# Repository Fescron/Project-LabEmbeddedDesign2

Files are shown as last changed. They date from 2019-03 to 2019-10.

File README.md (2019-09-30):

# Project-LabEmbeddedDesign2








<br/>

This repository contains the **presentation**, **reports** and **code** for the project constructed for **Embedded System Design 2 - Lab**.

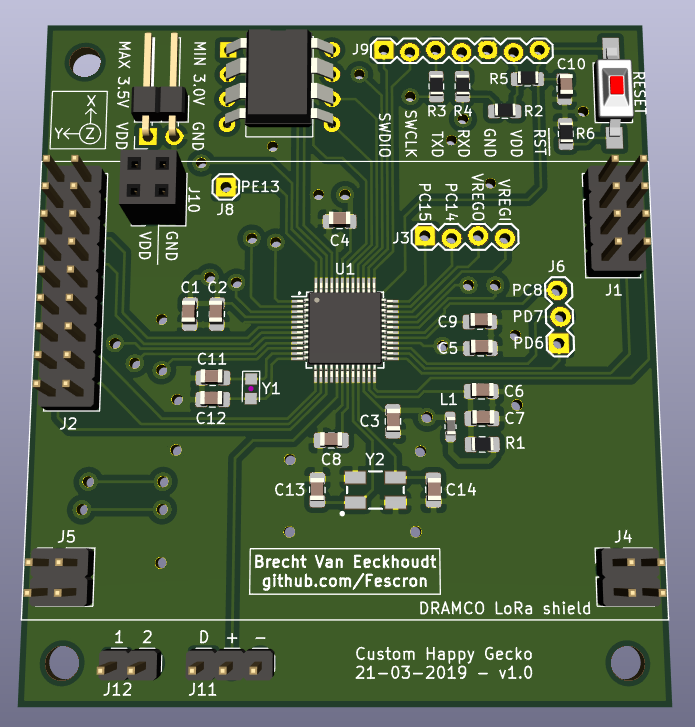
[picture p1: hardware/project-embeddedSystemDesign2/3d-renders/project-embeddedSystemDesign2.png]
Project
 Project

<br/>

## 1 - Quick links

- [**Reports and presentation**](documentation/reports)
- [General important Doxygen documentation](https://fescron.github.io/Project-LabEmbeddedDesign2/index.html)
- [Doxygen code documentation of individual files and methods](https://fescron.github.io/Project-LabEmbeddedDesign2/files.html)
- [Code for the custom TTN decoder](software/decoder.js)
- [Schematic of custom PCB](documentation/schematics/project-embeddedSystemDesign2.pdf)
- [Schematic of DRAMCO LoRaWAN shield](documentation/schematics/dramco-LoRa-addon-schematic-v4-0.pdf)
- [Picture with PCB dimensions](hardware/project-embeddedSystemDesign2/3d-renders/project-embeddedSystemDesign2-pcb-dimensions.png)
- [The Things Network - Applications](https://console.thethingsnetwork.org/applications/)
- [Cayenne Dashboard](https://cayenne.mydevices.com/cayenne/dashboard/start)

<br/>

## 2 - GIT repo structure

|  Location  |  Content  |
| --- | --- |
| [/docs/](https://fescron.github.io/Project-LabEmbeddedDesign2/index.html) | **[Doxygen](http://www.doxygen.org) code documentation.** |
| <br/> | |
| [/documentation/current measurements/](documentation/current%20measurements) | Documents containing current measurements. |
| [/documentation/current measurements/measurements-SF/](documentation/current%20measurements/measurements-SF) | Pictures depicting current profiles for sending 6 measurements at full gain with different LoraWAN *Spreading Factors*. More information can be found in section *"3 - LoRaWAN spreading factor (RN2483)"* in [this](documentation/current%20measurements/currents-2-projectEmbeddedDesign2.pdf) file . |
| <br/> | |
| [/documentation/datasheets/](documentation/datasheets) | General datasheets regarding the used items. |
| [/documentation/datasheets/hardware-design/](documentation/datasheets/hardware-design) | Documents regarding hardware design for the `EFM32HG` microcontroller. |
| [/documentation/datasheets/timers-energy-rtc/](documentation/datasheets/timers-energy-rtc) | Documents regarding `timers`, the `RTC` and `energy modes` on the `EFM32HG` microcontroller. |
| <br/> | |
| [/documentation/figures/](documentation/figures) | Figures used in reports and the README. |
| [/documentation/figures/installation/](documentation/figures/installation) | **Pictures taken during the project installation.** |
| [/documentation/reports/](documentation/reports) | **Reports and presentation.** |
| [/documentation/schematics/](documentation/schematics) | Schematics. <br/>  See [this](documentation/schematics/project-embeddedSystemDesign2.pdf) file for the schematic of the *self designed PCB* and [this](documentation/schematics/dramco-LoRa-addon-schematic-v4-0.pdf) file for the schematic of the *DRAMCO LoRaWAN shield*.
| <br/> | |
| [/hardware/project-embeddedSystemDesign2/](hardware/project-embeddedSystemDesign2) | [KiCad](http://kicad-pcb.org/) PCB design files. <br/> See [this](hardware/project-embeddedSystemDesign2/pdf/project-embeddedSystemDesign2.pdf) file for the *schematic* and [this](hardware/project-embeddedSystemDesign2/bom/bom-custom-gecko-v1-0.pdf) file for the *BOM*. |
| [/hardware/project-embeddedSystemDesign2/3d-renders/](hardware/project-embeddedSystemDesign2/3d-renders) | Pictures of 3D renders of the *self designed PCB*. <br/> On [this](hardware/project-embeddedSystemDesign2/3d-renders/project-embeddedSystemDesign2-pcb-dimensions.png) picture the *dimensions* are displayed. <br/>  [This](hardware/project-embeddedSystemDesign2/3d-renders/project-embeddedSystemDesign2.png) is a render of the *front* and [this](hardware/project-embeddedSystemDesign2/3d-renders/project-embeddedSystemDesign2-back.png) is a render of the *back*. |
| <br/> | |
| [/software/EFM32HG-Embedded2-project/](software/EFM32HG-Embedded2-project) | **Code for the project.** <br/> See [this](https://fescron.github.io/Project-LabEmbeddedDesign2/index.html) page for *general important documentation* and [this](https://fescron.github.io/Project-LabEmbeddedDesign2/files.html) page for information regarding *individual files and their methods*. [This](software/decoder.js) is the *decoder* for use on The *Things Network*. |

<br/>

## 3 - Code flow

**Note:** The code is developed using `Simplicity Studio v4` on `Ubuntu 18.04 LTS`. The code also has [dbprint](https://github.com/Fescron/dbprint) functionality.

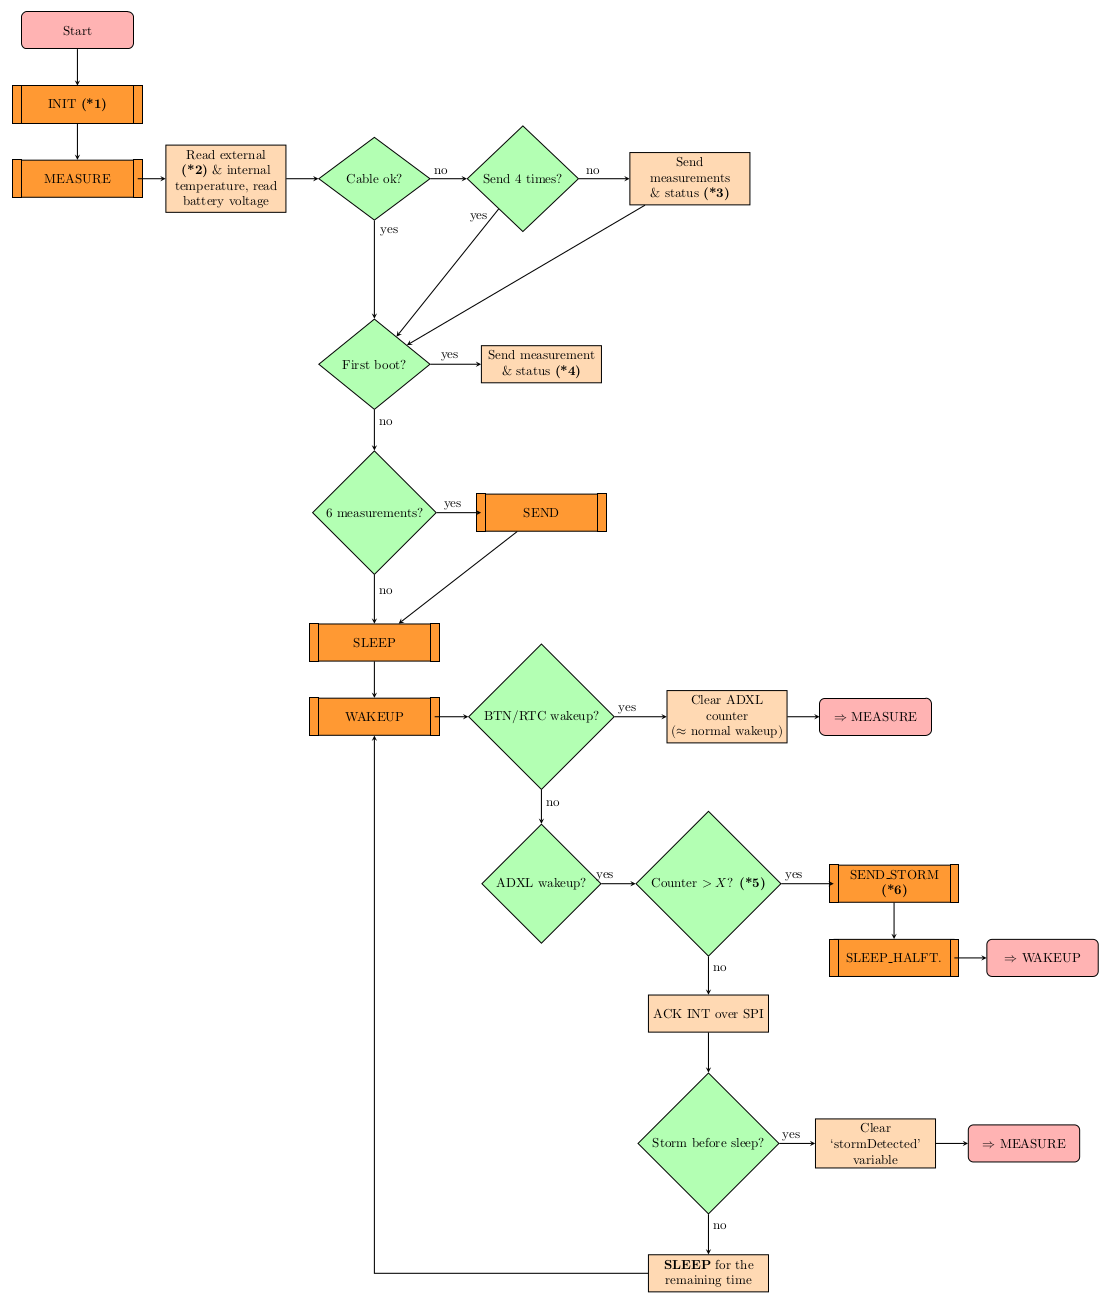
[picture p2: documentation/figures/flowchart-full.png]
Flowchart


**Extra notes on the flowchart:**

- **(\*1):** The following things get initialized:
    - Chip
    - GPIO wakeup (buttons & ADXL INT1)
    - ADC
    - Disable RN2483
    - Accelerometer (initialize SPI and use it to configure the accelerometer
- **(\*2):** On every external temperature measurement the VDD and DATA pin get re-configured. The oneWire protocol is achieved using *bit-banging*.
- **(\*3):** The RN2483 module gets enabled and configured before sending the data. Afterwards it gets disabled again. The **status** message is always send, measurements only if there are any recorded.
- **(\*4):** Only one set of measurements are send along with the status message.
- **(\*5):** The value of **X** depends on a configured setting.
- **(\*6):** A status message is send along with any recorded measurements.

<br/>

- Before entering a *sleep* state **all GPIO (data) pins are disabled** so they can't consume any power.
- **Clocks and peripherals** are only enabled when necessary.
- If an **error** occures this gets **forwarded to the cloud using a LoRaWAN status message**.
- To conserve sended bytes a **custom data-format** was used (along with a *decoder*).
- Negative internal and external temperatures were successfully send and displayed. The internal temperature seems to be 2 - 3 °C off.

<br/>

## 4 - Extra hardware changes

The [schematic](hardware/project-embeddedSystemDesign2/pdf/project-embeddedSystemDesign2.pdf) for the custom PCB **misses two resistors**. A surface mount `10 kΩ` resistor was added between the *data* and *power* pin for the DS18B20 temperature sensor. A `3,3 kΩ` resistor with wires was added between the `BREAK_1`pin and `VDD`. These added resistors can be seen on the bottom right on the left most picture below.

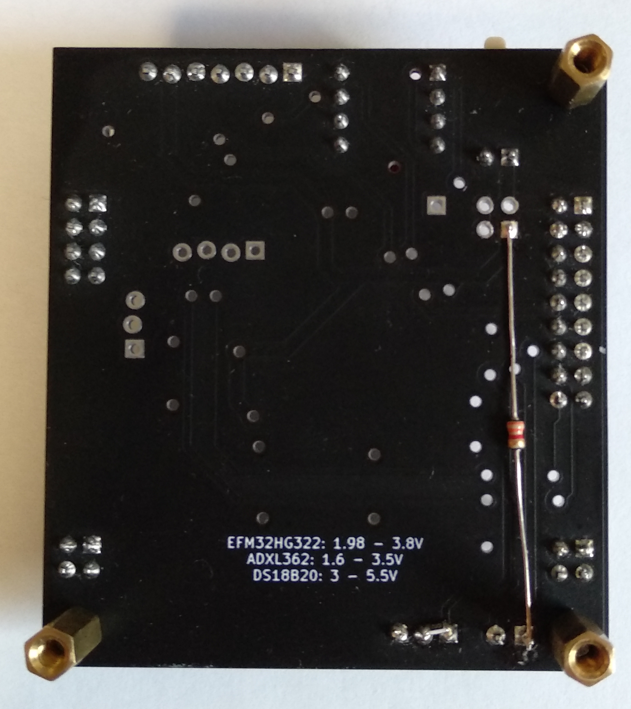
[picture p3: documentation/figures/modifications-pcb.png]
Added resistors
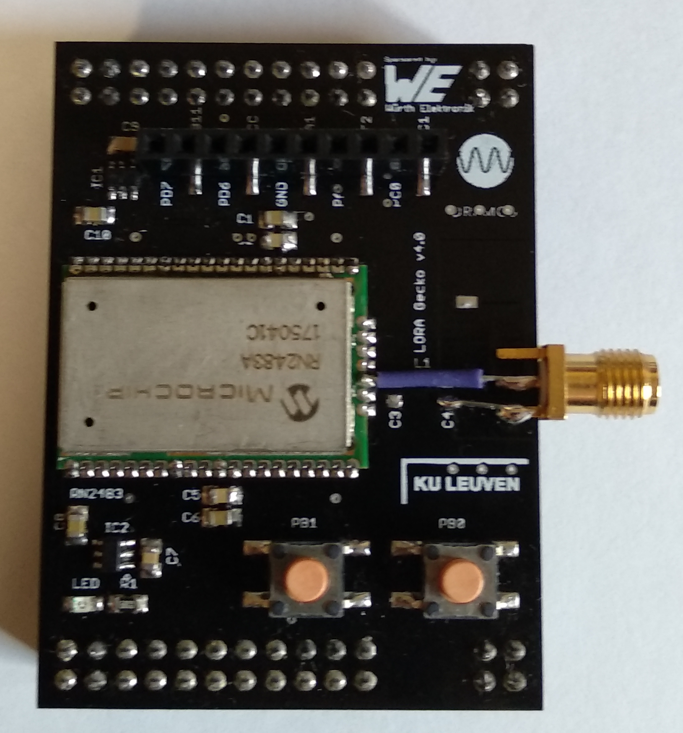
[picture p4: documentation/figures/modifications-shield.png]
Shield modifications
 

An **SMA connector for an external antenna** was also added to the DRAMCO LoRaWAN shield. This was done by **removing** the `chip-antenna`, capacitors `C3` and `C4` and inductor `L1` and replacing it with an SMA connector directly connected to the signal pin of the *RN2483* module. This modification can be seen on the right on the right most picture above.

To protect the PCB's from moisture and other contaminants, they were given 2 coats of `PLASTIK 70`.

Protection during coating Coating process

<br/>

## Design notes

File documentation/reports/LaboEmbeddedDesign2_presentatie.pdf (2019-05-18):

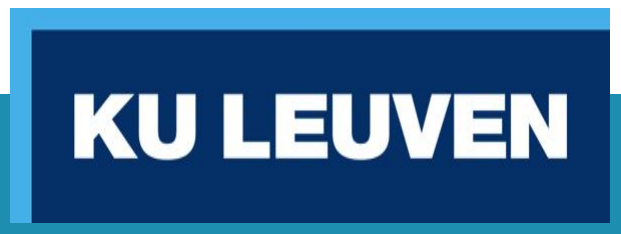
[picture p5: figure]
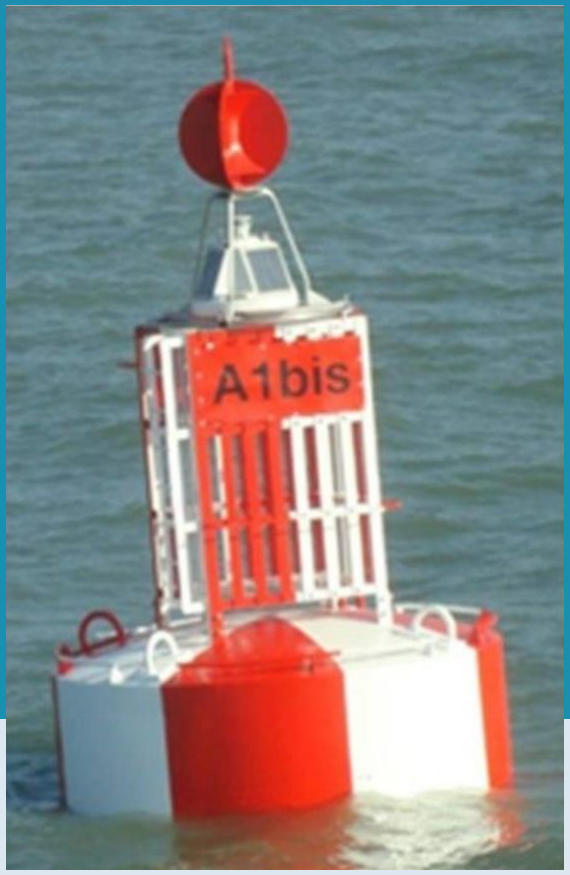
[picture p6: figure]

## Team ter Zee

Embedded System design 2
2018 - 2019

Brecht Van Eeckhoudt – Sarah Goossens – Matthias Alleman Benjamin Van der Smissen – Arno Plaetinck

- Driftdetectie boei op zee
- Meten van watertemperatuur
- Detecteren van ruwe zee
- Communicatie met het vaste land
2 | Embedded Systems Design: Team Ter Zee

## Beschrijving doelstellingen

- Specificaties
- Uitvoering
- Metingen
- Kostenanalyse
- Toekomstige verbeteringen
- Demo
- Besluit
- Q & A

3

## Inhoud

Embedded Systems Design: Team Ter Zee

- Functioneel technische:
1. Meten watertemperatuur, batterijspanning en interne temperatuur (elk uur)
2. Driftdetectie van boei (elk uur)
3. Stormdetectie via interrupts, extra metingen indien storm
4. Vier keer per dag data doorsturen naar vaste land
- Niet functioneel technische specificaties
1. Zo energiezuinig mogelijk
2. Module dient 5 jaar mee te gaan
3. Behuizing: bestand tegen zout water

## Specificaties

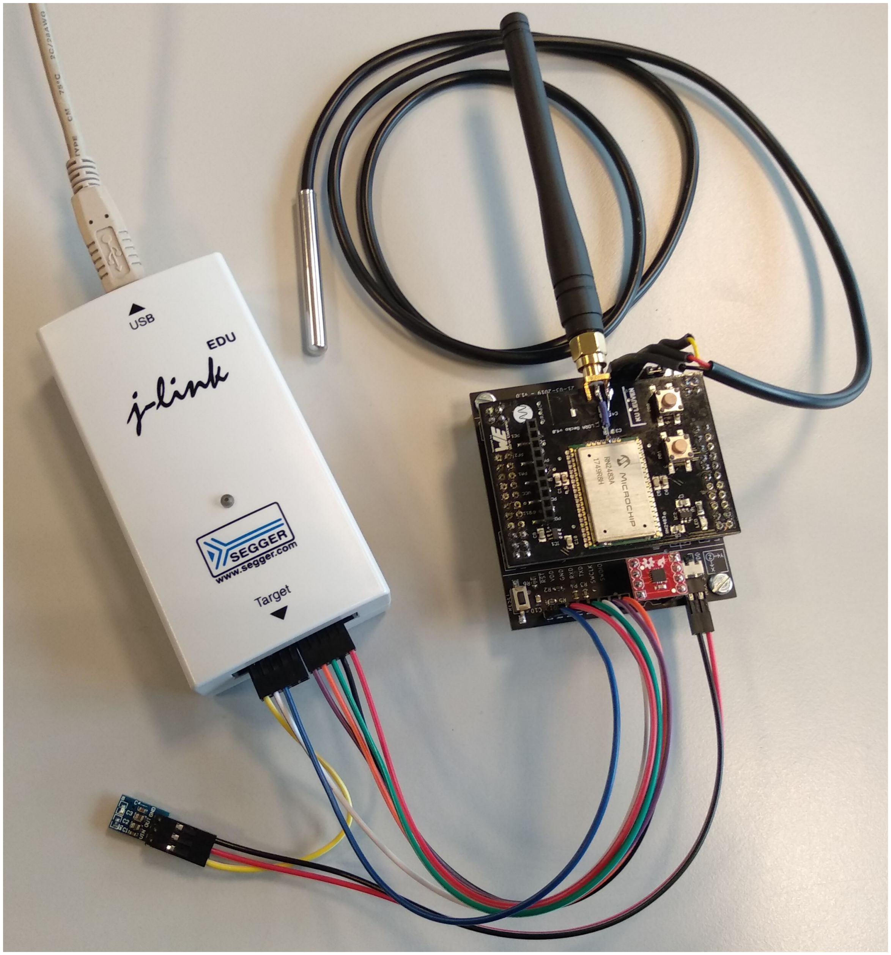
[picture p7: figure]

- Eigen PCB gebaseerd op Happy Gecko
- LoRaWAN-board van DRAMCO en antenne
- Accelerometer ADXL362
- Temperatuursensor DS18B20
- Driftdetectiesensor
- Batterij ER14505 (niet herlaadbaar) 3,6V Lithium-thionyl Chloride: Li-SOCl2
- Waterdichte behuizing

## Componenten

- Gebaseerd op een zwakke schakel van de ketting → Een kabel die breekt bij grote belasting

## Driftdetectie

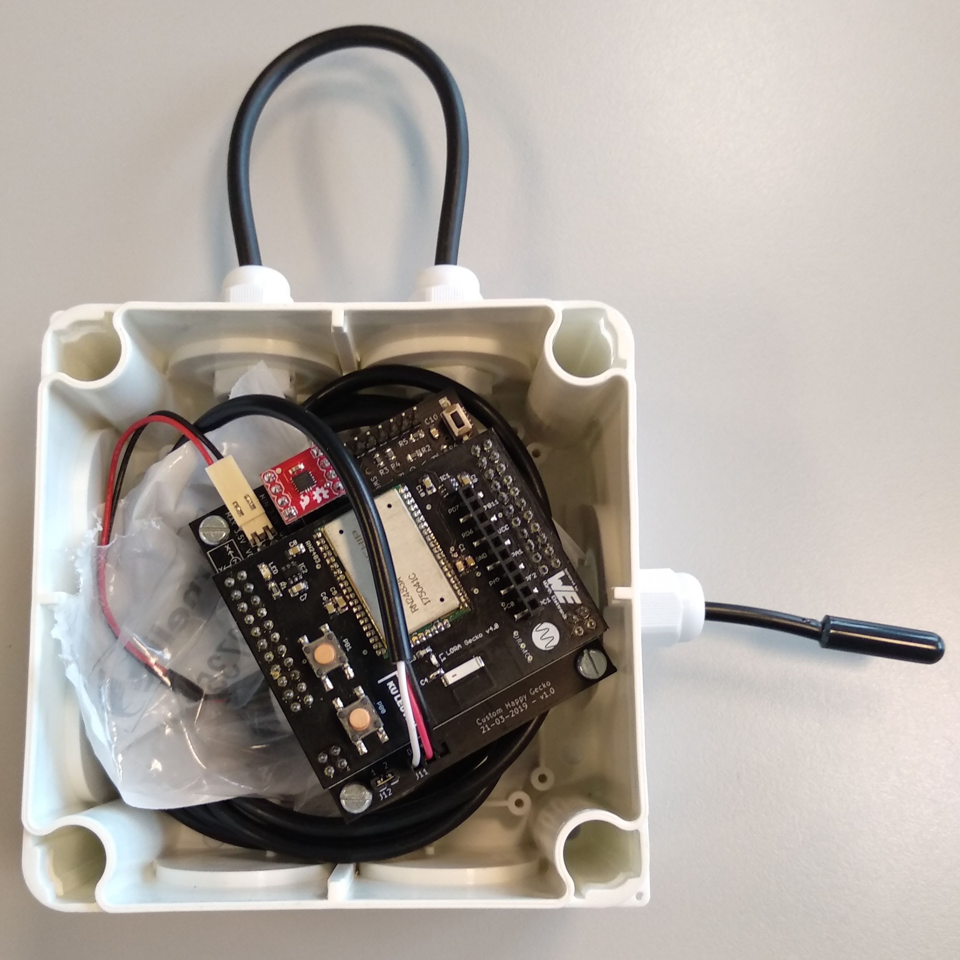
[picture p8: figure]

- Temperatuursensor meet watertemperatuur
- Accelerometer meet of er storm is

Indicatieve metingen:
- Interne temperatuur
- Batterijspanning

## Metingen

## Verbruik: metingen + sleep mode

Actieve tijd
(s)

Stroomverbruik
(mA)

Energie per onderdeel
(J/dag)
Happy Gecko | 123,2 | 5,52 | 2,244
ADXL362 | 115,2 | 0,00337 | 0,00128
DS18B20 | 24 | 2 | 0,158
LoRaWAN | 22,4 | 14,5 | 1,0696
Slaaptijd (s) | Stroomverbruik
(µA)
| | Energie per onderdeel
(J/dag)

Volledig
systeem
86,3E+03 | 4,06 | 1,16
Totale actieve energie: | 3,473 J/dag
Totale energie in sleep mode: | 1,16 J/dag

## Totaal verbruik

Totale Energie | 4,633 J/dag
Energie nodig voor vijf jaar : | 8395 J
Nodige batterijcapaciteit voor vijf jaar: | 707 mAh
Nodige batterijcapaciteit met veiligheidsfactor (x5): | 3535 mAh

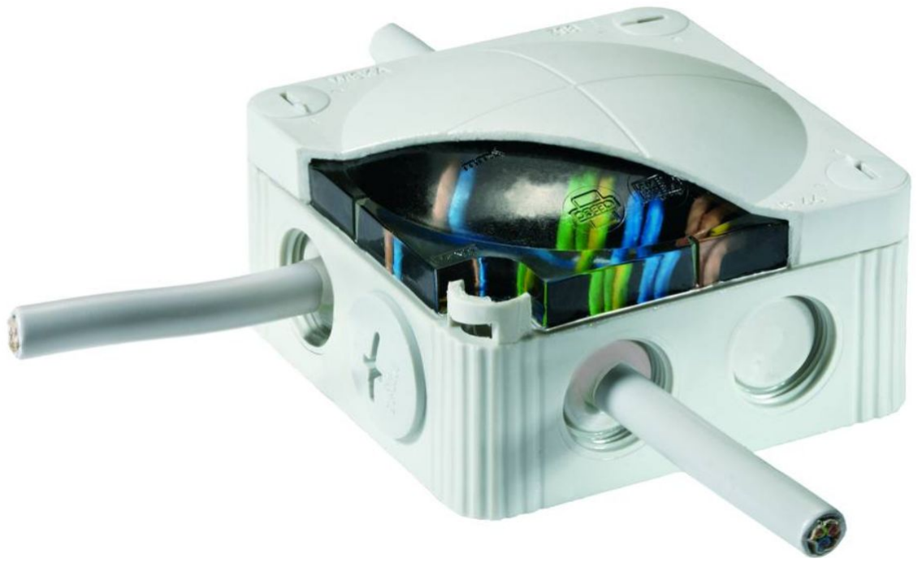
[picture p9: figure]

- IP67
- 4 connecties naar buiten
- Eventueel verzegelen met hars
- Zoutwater bestendig

→ Niet UV-bestendig ...

10

## Behuizing

- Cayenne LPP formaat vraagt veel “extra” bytes bij 6 metingen → Eigen data-formaat + decoder in TTN
- Ontvangen data moet nog niet echt verwerkt worden
→ Nu indicatief: e-mail via IFTTT
- Probleem in code → “error” methode aangeroepen → Doorzenden naar vaste land via statusbericht

## Communicatie naar vaste land

## Communicatie naar vaste land

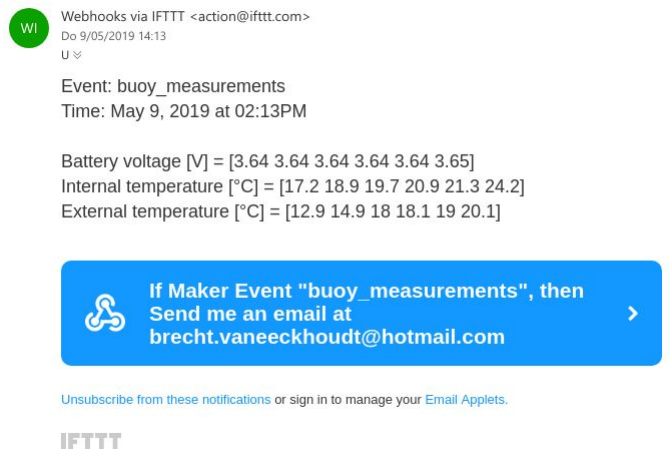
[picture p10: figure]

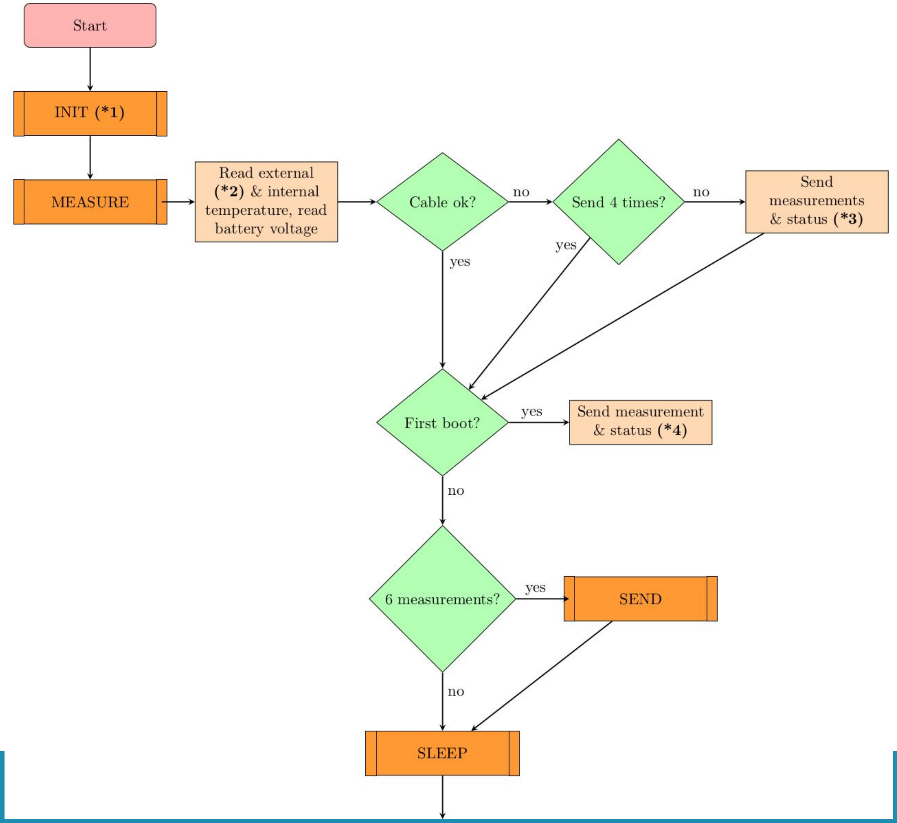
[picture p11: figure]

13

## Code Flow

## Code Flow

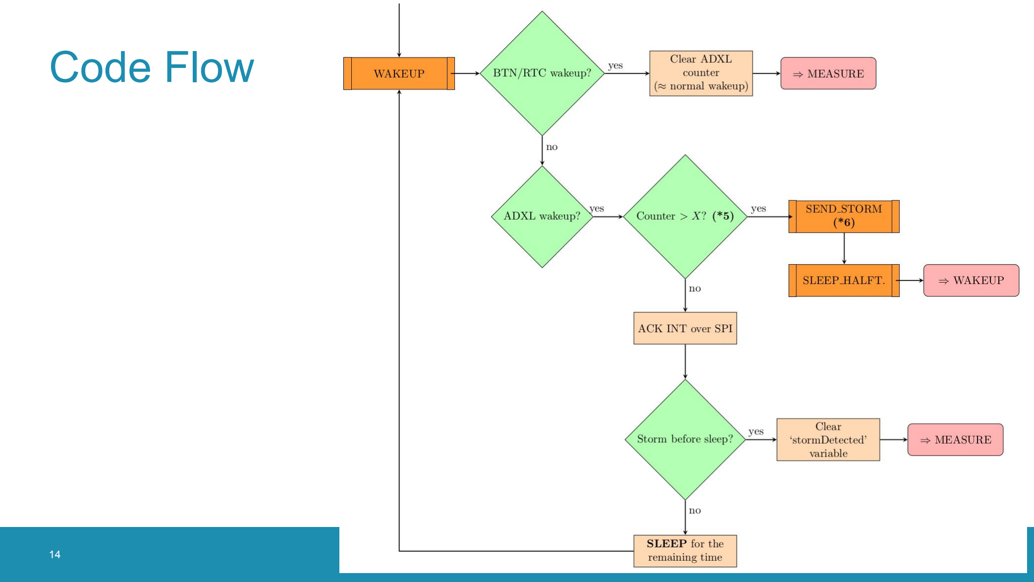
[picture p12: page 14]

14

## Metingen

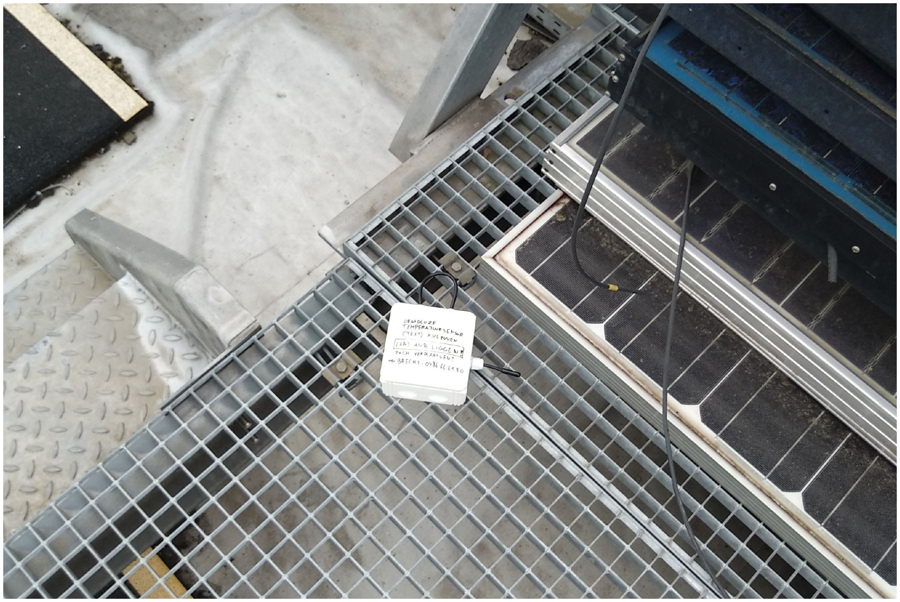
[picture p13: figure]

## Metingen

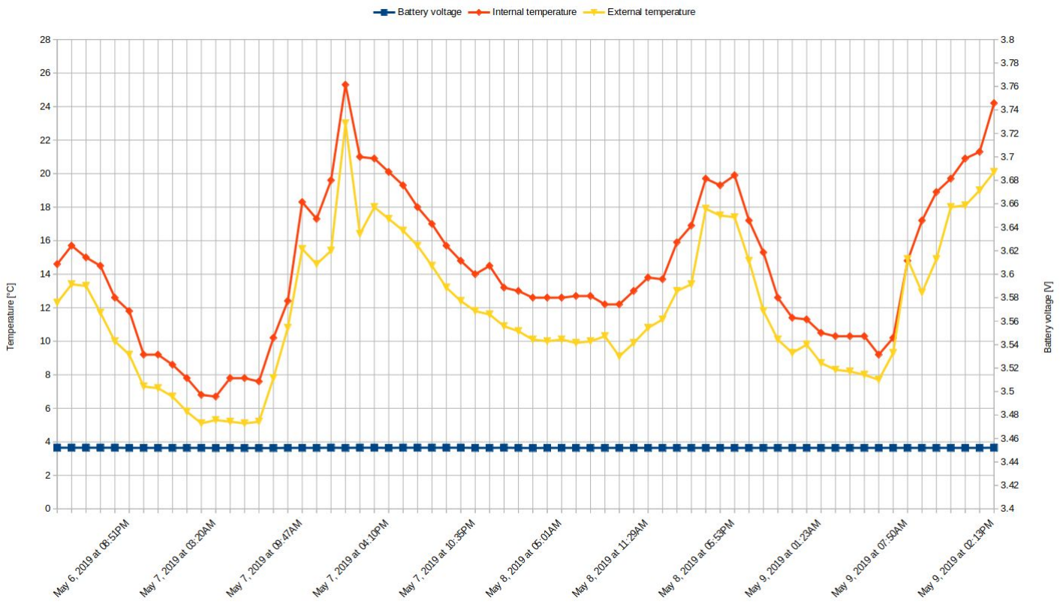
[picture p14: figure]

- De NRE-kosten zijn € 0
- Variabele kosten:
1. Eigen Happy Gecko | € 6
2. Temperatuursensor | € 10
3. Accelerometer | € 15
4. Driftsensor | € 1
5. Loramodule | € 10
6. Batterij | € 12
7. Behuizing | € 10
Totaal = € 64

## Kostenanalyse

18

- Breken van kabel via interrupt detecteren
→ Twee parallelle lijnen die normaal niet verbonden zijn → Bij een breuk verbinden ze via het water
- Andere manier om driftdetectie te detecteren
- LoRaWAN instellingen op module opslaan
- Golffrequentie berekenen met een FFT
- Accelerometer in wakeup-mode configureren
→ Ongeveer 6 keer per seconde een meting (270 nA)

19

## Toekomstige verbeteringen

## Demo

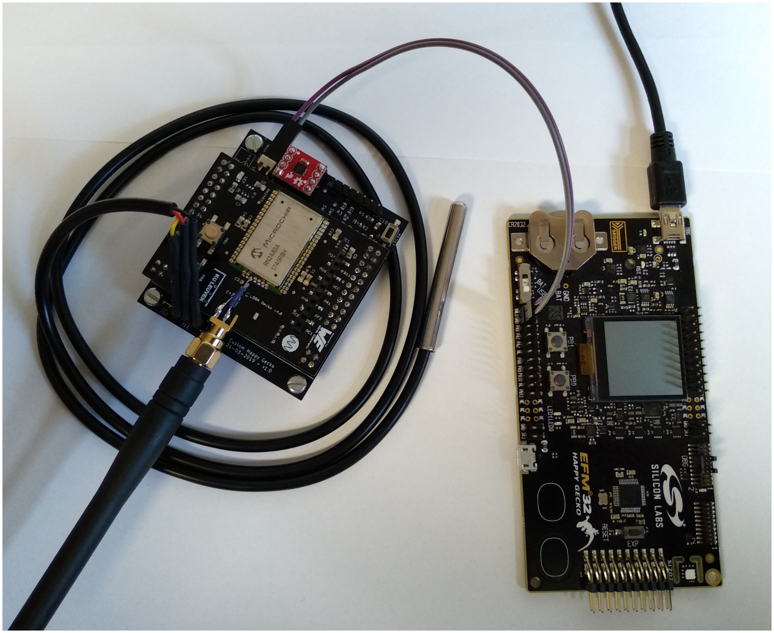
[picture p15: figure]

## Besluit

## Vragen?

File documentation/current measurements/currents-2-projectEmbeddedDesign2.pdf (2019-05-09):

### LAB EMBEDDED SYSTEM DESIGN 2

### PROJECT

## Measured currents at the end of the code development

Brecht Van Eeckhoudt
9 mei 2019

All measurements are done at 3, 29 − 3, 3 V

## 1 Sleep currents

The following currents represent the mean current consumed by the whole board between wake-ups using the RTC. An interval of 130 s was used to calculate this mean value. The accelerometer is enabled and measuring at ODR 12,5 Hz and can send an interrupt to wake-up the MCU.

| Sleeping in EM3 using ULFRCO (3600 s wake-up interval) ≈ 4, 06 µA
| Sleeping in EM2 using LFXO (500 s wake-up interval) ≈ 4, 12 µA
2 | ADXL362

The following currents represent the currents consumed by the accelerometer and MCU in various measuring modes. The settings are maintained for one second (≈ 800 ms due to the

ULFRCO not being very accurate) to calculate the mean current. The MCU is sleeping in EM3. Measurement mode is enabled for all values except when the accelerometer is in standby.

| Standby (after soft reset) ≈ 1, 60 µA
| ODR 12,5 Hz ≈ 3, 37 µA
| ODR 25 Hz ≈ 3, 43 µA
| ODR 50 Hz ≈ 3, 50 µA
| ODR 100 Hz ≈ 3, 79 µA
| ODR 200 Hz ≈ 4, 32 µA
| ODR 400 Hz ≈ 5, 53 µA

## 3 LoRaWAN spreading factor (RN2483)

The following (mean) currents are the result of sending 6 measurements using various LoRaWAN spreading factors. Use the pictures of the current proles to better understand the `peak' currents.

SF12: Imean ≈ 19, 88 mA (6, 95 s)

Ipeak 1 ≈ 41, 16 mA (2, 63 s) Ipeak 2 ≈ 15, 37 mA (150 ms) Ipeak 3 ≈ 15, 46 mA (250 ms)

Ibetween peaks ≈ 5, 10 mA

| SF11: Imean ≈ 14, 47 mA (5, 80 s)
Ipeak 1 ≈ 40, 76 mA (1, 4 s) (not | too | sure | about | the | `1,4 | s'. . . )

Ipeak 2 . . . (same currents and time as above for all the second and third peaks following, the 150 ms peak gets a bit shorter the lower the selected spreading factor.)
SF10: Imean ≈ 10, 41 mA (5, 03 s)

Ipeak 1 ≈ 40, 53 mA (650 ms)

SF9: Imean ≈ 8, 30 mA (4, 72 s)

Ipeak 1 ≈ 37, 09 mA (360 ms)

SF8: Imean ≈ 7, 28 mA (4, 56 s)

Ipeak 1 ≈ 37, 33 mA (200 ms)

SF7: Imean ≈ 6, 59 mA (4, 46 s)

Ipeak 1 ≈ 36, 42 mA (100 ms)

## 4 Active current

The following (mean) current was measured when the MCU gets woken up using a button interupt and takes measurements once. The DS18B20 temperature sensor used does very fast conversions, when using another one this timing might be dierent.

| Imean ≈ 1, 27 mA (81, 60 ms)
| Ipeak 1 ≈ 2, 83 mA

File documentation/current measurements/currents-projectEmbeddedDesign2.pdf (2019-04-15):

### LAB EMBEDDED SYSTEM DESIGN 2

### PROJECT

### Currents

Brecht Van Eeckhoudt
15 april 2019

## 1 Happy Gecko Energy modes

We jump between EM0 and EM2. The following data is from the datasheet.

EM0 230 µA/MHz (24 MHz = 5,52 nA)

EM1 67 µA/MHz

EM2 0,95 µA (RTC disabled not in our case since every hour we need to wake up?)

EM3 0,65 µA

EM4 20 nA

## 2 ADXL362

We use the accelerometer now @ 12,5 Hz ODR¹ so the actual current should be lower. The following data is from the datasheet.

100 Hz ODR @ 2V 1,8 µA

400 Hz ODR @ 2V 3,0 µA
Wakeup mode @ 2V 270 nA²

## 3 Happy Gecko + ADXL362

The following data is approximated using measurements.

Both active 2,30 mA

Happy Gecko @ EM2, ADXL active < 4 µA

3

1Output Data Rate
2Not yet implemented, 6 checks/second.
3ADXL measuring @ ODR 12,5 Hz and waiting to generate an interrupt.

1 van 2

## 4 Time and current estimates

The following data is approximated using measurements and common sense. They are pretty worst-case and should represent the total currents used by everything.

Every hour measurements 1s @ 2,8 mA

Four times a day sending LoRaWAN data 2s @ 30 mA

Sleep 5 µA

Emeasure/day = 24 [times] ⋅ 1 [second] ⋅ 2, 8 mA ⋅ 3, 3 V = 0, 22176 [J]

Esend/day = 4 [times] ⋅ 2 [seconds] ⋅ 30 mA ⋅ 3, 3 V = 0, 792 [J]

tsleep = (24 [hours] ⋅ 60 [minutes] ⋅ 60 [seconds]) − 24 ⋅ 1 [second] − 2 ⋅ 4 [seconds] tsleep = 86368 [seconds]

Esleep/day = 86368 [seconds] ⋅ 5 µA ⋅ 3, 3 V = 1, 425072 [J]

Etotal/day = 0, 22176 [J] + 0, 792 [J] + 1, 425072 [J] = 2, 438832 [J]

| [J] ⇒ [mAh]: /3, 6/VDD
| How much years will it last? (at | least | 5!)
1. You have a number in Joules/day, convert it to the mean current throughout
| the whole day.
2. Take the mAh value of the battery and use it to calculate the lifetime in years.

% sleeping/day =

sleep/day
total/day

=

86368 [seconds]
86400 [seconds]

= 99, 963%

2 van 2

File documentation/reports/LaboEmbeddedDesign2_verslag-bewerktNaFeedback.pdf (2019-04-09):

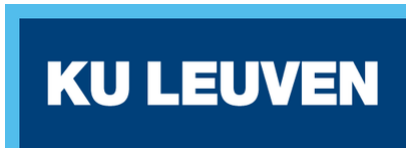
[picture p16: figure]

faculty of engineering technology

– gent –

### EMBEDDED SYSTEM DESIGN 2 – LABO

masterplan

# Project ‘Ter Zee’

### Brecht Van Eeckhoudt – Sarah Goossens – Matthias Alleman Benjamin Van der Smissen – Arno Plaetinck

MELICTE

### 28 maart 2019

Embedded System Design 2 – Labo: Masterplan: Project ‘Ter Zee’

### Inhoudsopgave

2 van 14

### 1 Identificatie van het project

### 1.1 Het team

In volgende paragrafen worden de verantwoordelijkheden van de verschillende teamleden gespecificeerd. Dit zowel op het technologisch- als op het projectmatige domein.

### 1.1.1 Technologie

Temperatuursensor Sarah

Breekbare draad Matthias

Levensduurscalculatie Arno

Powermanagement Brecht

LoRaWAN-connectie Benjamin

Behuizing Matthias

Accelerometer Brecht

### 1.1.2 Project

Time-manager Matthias

Integratie-manager Brecht

Verslagmanager Sarah

Presentatiemanager Arno

Externe communicatie Benjamin

### 1.2 Kost en duur van het project

In deze paragraaf worden de geschatte kosten en duur van het project weergegeven. Ze behoren tot de niet-technische specificaties van het project. Op basis van de gebruikte componenten bekomen we een geschatte kostprijs van 64 euro. Voor de NRE kosten en de testkost moeten er geen kosten in rekening gebracht worden. Voor het maken van een eerste prototype worden twee maanden voorzien. Om een volledig werkend product te hebben, rekenen we drie maanden. Een detailbeschrijving van alle kosten is te vinden in paragraaf 4.4 op pagina 13.

### 2 Het project

Ons project is een onderdeel van een groter project waarbij het hoofddoel het detecteren is van driftende boeien en het meten van verschillende parameters van zowel het zeewater als de lucht. Deze info wordt via draadloze communicatie doorgegeven aan het vaste land waar de info verwerkt wordt. Op die manier kan er tijdig actie ondernomen worden indien een boei zou gaan driften. Verder verkrijgen we heel wat informatie over het zeewater en de lucht.

### 3 Doelstellingen en specificaties

### 3.1 Doelstellingen

Als Team ’Ter Zee’ zijn wij verantwoordelijk om een totaalconcept uit te werken dat het mogelijk maakt om de watertemperatuur en golfsterkte te meten, te verwerken en door te sturen. Verder zal het team ook in staat moeten zijn om de drift van een boei waar te nemen en te signaleren aan het vasteland, zodat er tijdig actie ondernomen kan worden. Over de exacte locatie van de boei nadat deze is losgekomen, is geen info gekend.

Bij het meten van de golfsterkte beperken we ons tot het alarmeren van het vasteland indien er een storm gedetecteerd wordt. Een storm wordt gedefinieerd door het overschrijden van een bepaalde threshold waarde, gedetecteerd door een accelerometer. Deze waarde zal proefondervindelijk vastgelegd worden doorheen het project. Wanneer de accelerometer een storm detecteert, betekent dit dat er een verhoogd risico is op het driften van een boei. Er zal dan ook frequenter nagegaan worden of een boei aan het driften is.

Alle sensoren zullen gelijktijdig actief moeten zijn en we zullen in het totaalconcept ook zeer nauwkeurig letten op het vermogenverbruik aangezien het niet de bedoeling is dat de batterijen waarvan we gebruik zullen maken regelmatig moeten vervangen worden. Als kers op de taart is bij ons de extra moeilijkheid dat ons systeem bestand moet zijn tegen het zoute water van de zee. Een aangepaste behuizing die zowel water als zout resistent is, zal dus één van onze uitdagingen worden.

Om deze doelstellingen te bereiken, zal ons systeem aan bepaalde specificaties moeten voldoen.

### 3.2 Functioneel technische specificaties

- Watertemperatuur meten om het uur.
- Detectie van driftende boeien om het uur.
- Stormdetectie door het meten van de grootte van de golven. Indien een bepaalde waarde overschreden wordt, concluderen we dat we te maken hebben met een storm. Deze waarde wordt gedurende het project proefondervindelijk vastgelegd. Metingen gebeuren om de seconde gedurende 1 minuut en dit éénmaal per uur.
- Data verzamelen, verwerken en vier keer per dag doorsturen naar het vasteland.
- Nauwkeurigheid temperatuurmeting: 0,5 °C.
- Elk uur wordt het systeem gewekt en voert het zijn functie uit.

– In geval van een storm wordt het systeem onmiddellijk gewekt via een interrupt van de accelerometer. Dit wordt ook meteen doorgestuurd naar het vaste land. Indien dit gebeurt, zal er een frequentere controle zijn op het driften van boeien. Elke 10 minuten wordt een controle uitgevoerd.

– Het systeem gaat telkens terug in slaap van zodra alle functies afgerond zijn.

### 3.3 Niet functioneel technische specificaties

- We kiezen voor een zeer energiezuinige implementatie en schakelen onderdelen van het ontwerp uit op momenten dat deze niet nodig zijn.
- De batterij moet minstens 5 jaar meegaan.
- Het gehele ontwerp, zonder temperatuursensor zal in een behuizing van ongeveer 10×10×10 cm moeten passen.
- Het geheel weegt ongeveer 500 gram.
- Behuizing moet bestand zijn tegen zout water.
- Alle componenten en verbindingen moeten goed bevestigd zijn zodat ze tegen een stootje van de wilde golven kunnen.
- De componenten moeten temperaturen verdragen tussen de -30 °C en de +100 °C.

### 3.4 Doelstellingen buiten scoop project

Aangezien we gelimiteerd zijn om het project tot een goed einde te brengen sluiten we bepaalde ontwikkelingen uit. Om te beginnen zetten we geen LoRaWAN gateway op. We gaan er vanuit dat deze al op het vaste land aanwezig zal zijn en zorgen enkel dat we er berichten naartoe kunnen sturen.

Vervolgens gebruiken we ook niet de acceleratiewaarden om de golfhoogte en golffrequentie te berekenen. We zouden dit in principe kunnen doen aan de hand van FFT (beschikbaar in de CMSIS libraries) op waarden in de FIFO van de accelerometer. We gebruiken de accelerometer enkel om aan de hand van een threshold value de Happy Gecko via een interrupt wakker te maken en zo te zorgen dat hij regelmatiger meet of de boei al dan niet is losgeslagen.

Daarnaast werd ook het gebruik van een zonnepaneel onderzocht. Hieruit konden we concluderen dat het zeker nuttig en haalbaar was om hiervan gebruik te maken. We hebben echter beslist om dit niet zelf toe te passen om te kunnen focussen op een goed werkend systeem. Het gebruik van een zonnepaneel kan later nog toegevoegd worden.

Als laatste vullen we onze behuizing niet op met gel. Om bijvoorbeeld opbouwdozen helemaal waterdicht te maken wordt dit aangeraden, maar aangezien dit debugwerk zou bemoeilijken opteren we ervoor om dit niet te doen.

### 4 Uitvoering

Om de verschillende metingen uit te voeren, werden de nodige sensoren geselecteerd. De temperatuurmeting zullen we doen met behulp van de DS18B20 die wordt uitgelezen met behulp van een EFM32 Happy Gecko die door ons team ontworpen is. De golfsterkte meten we met behulp van de accelerometer ADXL362. De drift van de boei zullen we trachten te achterhalen met behulp van een simpele maar toch ingenieuze methode. Communicatie van alle gegevens naar het vaste land zal gebeuren via LoRaWAN. Alle onderdelen komen tenslotte terecht in een specifieke behuizing voor dit systeem. Op elke boei zal er dan een volledig systeem geplaatst worden, waarbij enkel de temperatuursensor en de driftdetec-tieconstructie contact maken met het zoute zeewater.

We bespreken alle onderdelen van het systeem uitgebreider in volgende paragrafen. Het blokschema van het concept is afgebeeld op figuur 1.

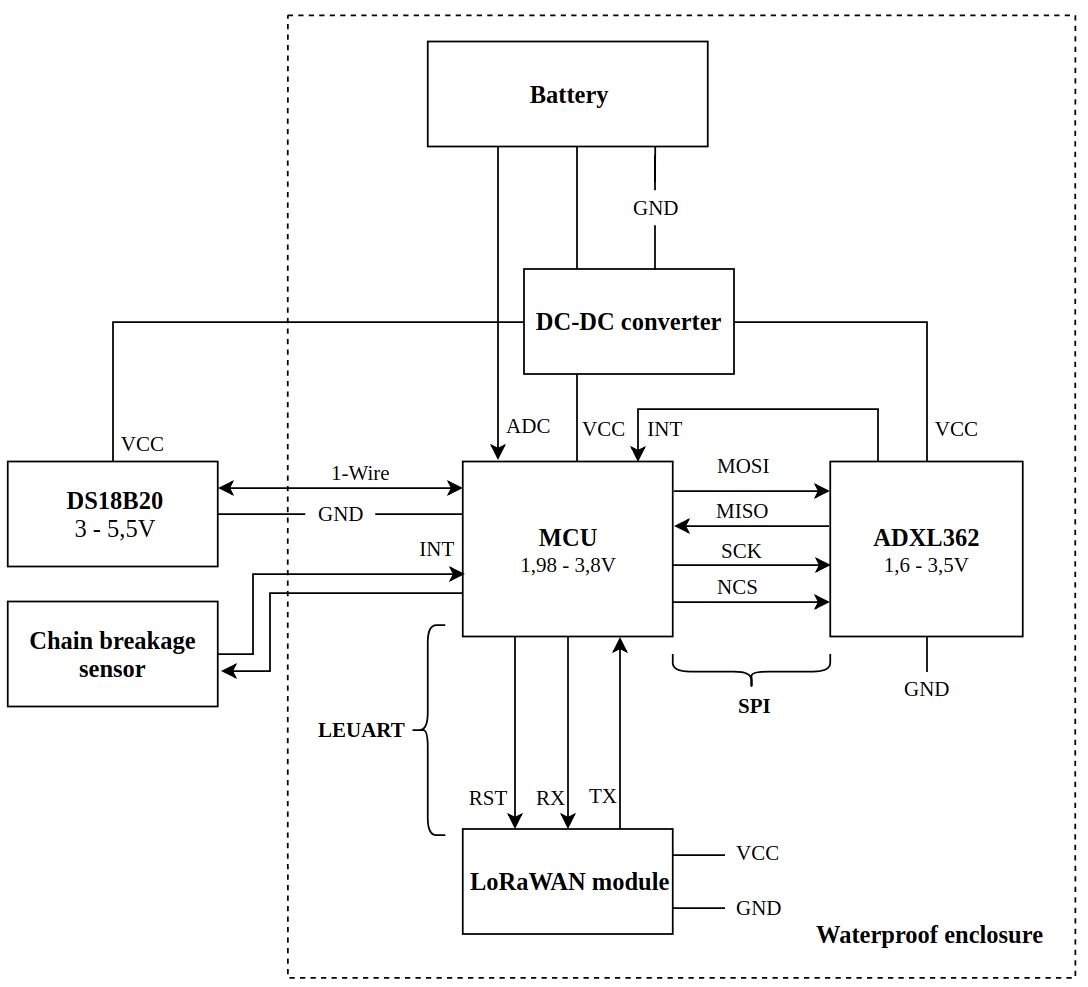
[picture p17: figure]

Figuur 1: Blokschema van het concept.

### 4.1 Onderdelen

### 4.1.1 Sensoren

### 4.1.1.1 Temperatuursensor DS18B20

Om de temperatuur van het water te meten zullen we gebruik maken van de temperatuursensor DS18B20, dewelke is afgebeeld op figuur 2. Deze sensor geeft als resultaat de digitale waarde van de temperatuur in 9 tot 12 bits. Er kan een temperatuur gemeten worden tussen -55 °C en +125 °C. De sensor is daarenboven ook waterdicht. Verdere tests zullen uitwijzen of de sensor ook bestand is tegen het zeewater. Indien zou blijken dat dit niet het geval is, wordt hiervoor een oplossing gezocht.

De sensor zal communiceren met de Happy Gecko via OneWire. Om energie te sparen zal slechts op bepaalde tijdstippen de temperatuur van het water gemeten worden, nl. om het uur. De Happy Gecko geeft telkens opdracht aan de sensor om de temperatuur te meten. De sensor stuurt hierop een digitale waarde naar de Happy Gecko, die deze temperatuur zal omzetten in een aantal graden Celsius zodat deze waarde naar het vaste land kan gestuurd worden en daar correct geïnterpreteerd kan worden.

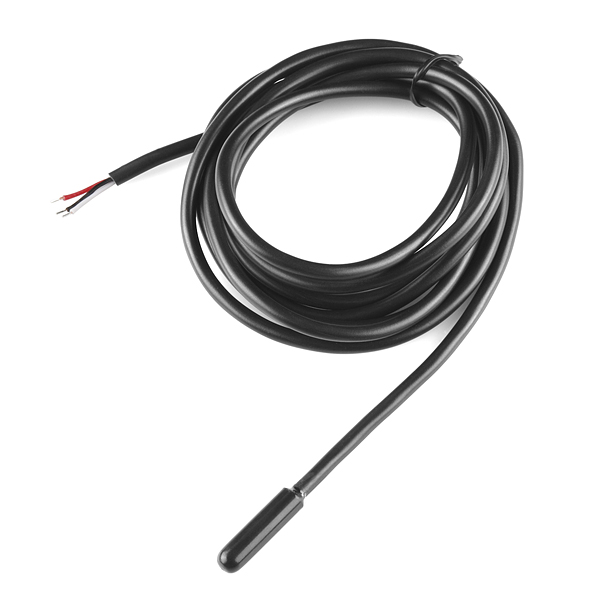
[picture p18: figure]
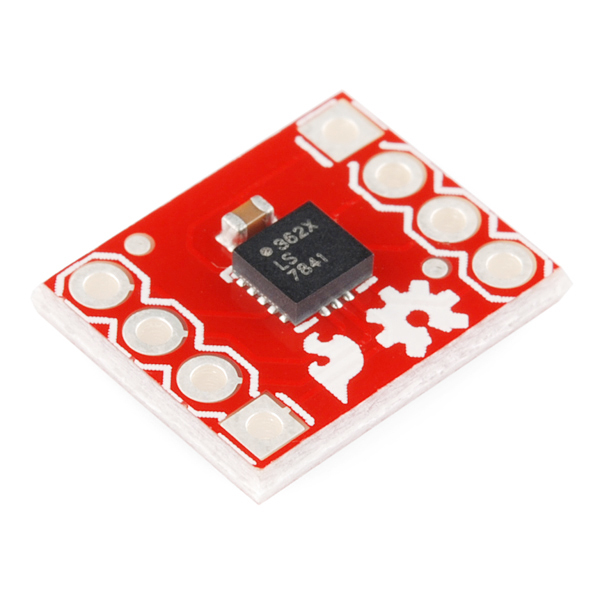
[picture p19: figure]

Figuur 2: Temperatuursensor DS18B20. Figuur 3: ADXL362 accelerometer op het breakoutbord.

### 4.1.1.2 Accelerometer ADXL362

Om de Happy Gecko, in het geval van een storm, wakker te maken uit zijn slaaptoestand zullen we gebruik maken van een ADXL362 accelerometer die een interrupt zal sturen naar de microcontroller. Dit is een ultra low power MEMS accelerometer die in drie assen de acceleratie kan meten. Deze sensor laat het ook toe om de golfslag en golf-frequentie te meten.

Voor dit labo is er gebruik gemaakt van het Sparkfun breakoutbord van deze sensor, zodat de sensor gemakkelijk aan het ontwikkelbord gekoppeld kan worden. De sensor kan gevoed worden met een spanning tussen de 1,6 V en 3,5 V en kan dus rechtstreeks verbonden worden met het development bordje. De meting van de sensorwaarde wordt digitaal doorgestuurd via SPI.

### 4.1.1.3 Driftsensor – eigen ontwerp

De drift van een boei zullen we detecteren aan de hand van een zelfontworpen sensor. De sensor zal bestaan uit een draad die op een bepaalde spanning gehouden wordt. Deze draad zal verwikkeld zijn in de schakels van de ketting waaraan de boei bevestigd is.

Op het moment dat een boei loskomt van zijn ketting zal de spanning op de pin waarmee de kabel verbonden is wegvallen (aangezien het draadje breekt) waardoor wij zullen weten dat de boei op drift is. Een extra veiligheidsmechanisme zullen we mogelijks inbouwen zodat de boei niet direct wegdrift, maar dat de boei nog enige tijd op zijn plaats blijft.

### 4.1.2 LoRaWAN

Om data vanop zee door te sturen naar ‘de cloud’ moet er gebruik gemaakt worden van een communicatieprotocol met twee belangrijke specificaties. De communicatie-range moet groot zijn, en de toepassing moet energiezuinig werken.

LoRaWAN is een long-range wireless communicatieprotocol gebruikt om data over lange afstanden te versturen, wat dus een perfecte match is voor ons project. Dit is onder andere mogelijk doordat het een lage datarate (onder 50kbps) heeft. Hierdoor is LoRaWAN wel enkel een goede keuze voor energiezuinige en non-realtime applicaties.

### 4.1.3 Behuizing

Voor het ontwerp van de behuizing zullen we voornamelijk op zoek gaan naar materialen die bestand zijn tegen corrosie van het zoute water van de Noordzee. We zullen dus rekening moeten houden met de vijsjes en het materiaal waaruit de behuizing gemaakt wordt.

Het initiële plan bestond eruit om een behuizing te 3D-printen, maar in realiteit is het zeer moeilijk deze volledig waterdicht te krijgen. Tevens is PLA ook niet echt bestand tegen de zon en het zoute water.

We gingen vervolgens op zoek naar bestaande cases en vonden enkele die gebruikt worden op werven. Ze bestaan in verschillende uitvoeringen met verschillende materiaalsterktes. De betreffende case is van het merk WISKA en is volgend model: ‘COMBI® IP68 SET 1010/5 LG’. We hopen hiermee een voldoende waterdicht systeem te realiseren, hoewel dit een risico is dat we nog niet kunnen inschatten. Volledig waterdichte behuizingen lopen vrij snel op in prijs wat voor ons project niet gunstig is.

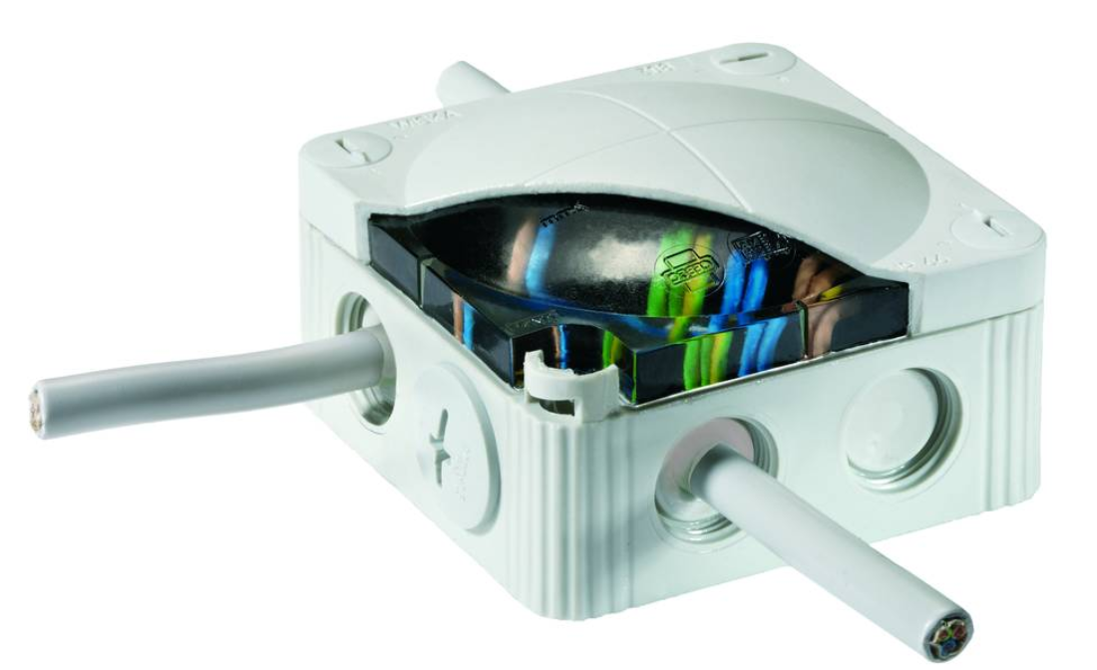
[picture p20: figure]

Figuur 4: De behuizing die we mogelijks zullen gebruiken.

### 4.2 Planning

Op volgende figuren is een overzicht gegeven van de planning van het project. Hierbij is steeds vermeld wat er moet gebeuren en hoeveel tijd we hieraan denken te spenderen. Voor elke taak is ook een eindverantwoordelijke aangesteld.

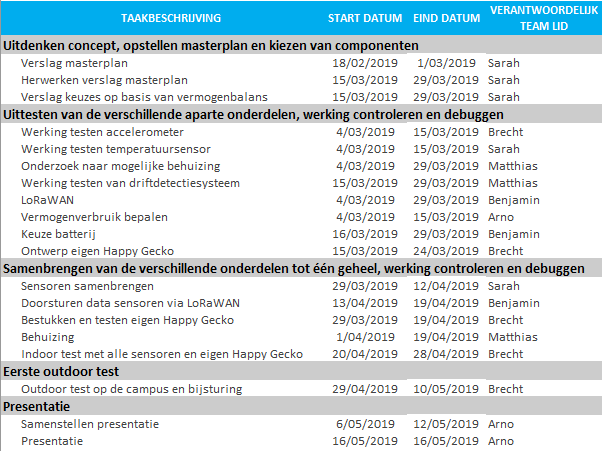
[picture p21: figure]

Figuur 5: Overzicht van het werk in de tijd.

Embedded System Design 2 – Labo: Masterplan: Project ‘Ter Zee’

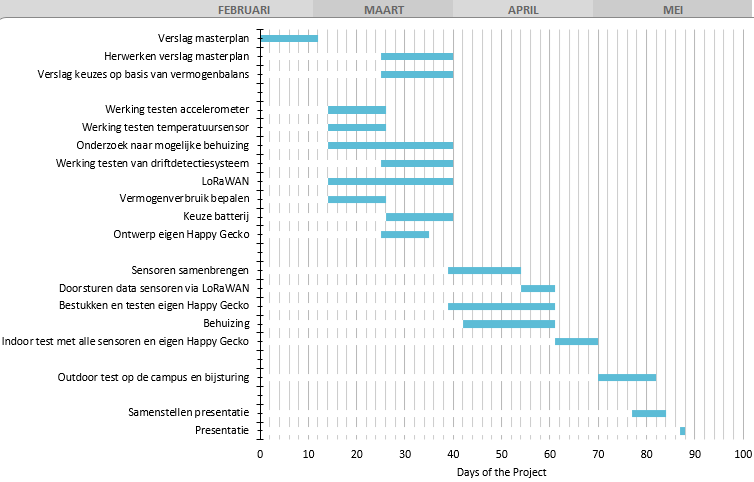
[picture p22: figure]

Figuur 6: Overzicht van het werk in de tijd.

12 van 14

### 4.3 Risico’s

Op volgende tabel lijsten we de mogelijke risico’s op met mogelijke bijhorende oplossingen.

Tabel 1: Mogelijke risico’s en bijhorende oplossingen.

Mogelijk risico | Mogelijke oplossing
Eigen Happy Gecko werkt niet. | Gebruik maken van een Happy
Gecko van Silicon Labs.
Behuizing is niet waterdicht. | Kleine aanpassingen aanbrengen
zodat systeem toch waterdicht is. Eventueel zoeken naar waterdichte alternatieven.
Ons systeem blijkt niet zoutbestendig. In | de | toekomst | uitgebreidere
research doen.
Kosten zijn hoger dan verwacht. | Kosten zoveel mogelijk proberen te
beperken, eventueel zoeken naar alternatieven.
Sensoren werken niet zoals voorzien. | Nieuwe | sensor | gebruiken | of
eventueel een andere sensor kiezen.
Een teamlid is ziek. | We verdelen de taken over de overige
| teamleden.

### 4.4 Kostenanalyse

- De NRE-kosten zijn 0 aangezien er geen lonen in rekening worden gebracht.
- Variabele kost:
1. Eigen Happy Gecko – 6 euro
2. Temperatuursensor – 10 euro
3. Accelerometer – 15 euro
4. Driftdetector – 1 euro
5. LoRa-module – 10 euro
6. Batterij – 12 euro
7. Behuizing – 10 euro

Totaal: 64 euro

- Testkost – 0 euro daar er geen lonen in rekening worden gebracht.
- Tijd tot eerste prototype – 2 maand
- Tijd tot eerste product – 3 maand
- Tijd tot massaproductie – niet van toepassing

### 4.5 Communicatie

Om tijdens het project een goede communicatie te hebben in het team wordt gebruik gemaakt van een groepschat op Facebook Messenger. Documenten worden hier eveneens in gedeeld en er wordt ook gebruik gemaakt van Google Drive en Overleaf. De groep spreekt op regelmatige basis af om de voortgang te bespreken. Dit gebeurt enerzijds om de twee weken tijdens een labozitting en anderzijds op een moment gekozen door het team zelf. Binnen het team is er ook een verantwoordelijke aangesteld om te communiceren met professoren en om bestellingen door te geven.

### Referenties

[1] Github, Project Labo Embedded System Design 1,
https: // github .com/ Fescron/ Project-LabEmbeddedDesign1 (https://github.com/Fescron/Project-LabEmbeddedDesign1)
[2] DS18B20, DS18B20 datasheet,
https: // datasheets .maximintegrated .com/ en/ ds/ DS18B20 .pdf (https://datasheets.maximintegrated.com/en/ds/DS18B20.pdf)

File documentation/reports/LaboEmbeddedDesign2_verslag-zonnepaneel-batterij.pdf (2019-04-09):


faculty of engineering technology

– gent –

### EMBEDDED SYSTEM DESIGN 2 – LABO

verslag 2

# Project ‘Ter Zee’

### Brecht Van Eeckhoudt – Sarah Goossens – Matthias Alleman Benjamin Van der Smissen – Arno Plaetinck

MELICTE

### 29 maart 2019

Embedded System Design 2 – Labo: Verslag 2: Project ‘Ter Zee’

### Inhoudsopgave

2 van 14

### 1 Het project

Als Team ‘Ter Zee’ zijn wij verantwoordelijk om een totaalconcept uit te werken dat het mogelijk maakt om de watertemperatuur en golfsterkte te meten, te verwerken en door te sturen. Verder zal het team ook in staat moeten zijn om de drift van een boei waar te nemen en te signaleren aan het vasteland, zodat er tijdig actie ondernomen kan worden.

Om dit project te verwezenlijken, zijn er verschillende oplossingen. In dit verslag vergelijken we twee mogelijke benaderingen van ons systeem. We bekijken wat het verschil in verbruik is wanneer we in ons project gebruik maken van een zonnepaneel en een batterij of enkel een batterij. Voor beide opties zal het verbruik steeds hetzelfde zijn. Hoe we het verbruik per dag bepalen, wordt verder in dit verslag besproken.

Voor de optie met het zonnepaneel worden een geschikt zonnepaneel en batterij gezocht. Voor de optie zonder een zonnepaneel bekijken we welke batterijen geschikt zijn voor ons project. Hierbij houden we rekening met het feit dat een batterij 5 jaar moet meegaan.

We bekeken ook de optie om gebruik te maken van een supercap.

### 2 Verbruik

Om het verbruik per dag te bepalen zijn we uitgegaan van volgende specificaties:

- Om het uur meten van de temperatuur van het water.
- De accelerometer meet constant om zo interrupts te kunnen sturen naar de microcontroller om deze indien het geval van een storm wakker te maken.
- Per dag wordt viermaal alle data doorgestuurd naar het land.
- Om het uur checken we of de boei aan het driften is.
- We maken gebruik van een Happy Gecko.

In volgende berekeningen geven we een duidelijke weergave van het geschatte verbruik.

We beginnen met een korte samenvatting van het verbruik van elk onderdeel in actieve- en slaapmodus.

Tabel 1: Oplijsting van het stroomverbruik.

| Actief verbruik | Passief verbruik
Happy Gecko | 5,52 mA | 0,95 µA
ADXL362 | 1,80 µA | 1,80 µA
Tempsensor | 2,00 mA | 0 mA
LoRaWAN | 30 mA | 0 mA

De driftsensor heeft ook een bepaald verbruik, maar aangezien dit verbruik zo miniem is nemen we deze niet mee in de berekeningen. Die sensor zou 1 ms lang 1 mA verbruiken.

Vervolgens bekijken we hoeveel energie onze modules verbruiken tijdens het actief verbruik, namelijk bij het meten en verzenden van de data.

Tabel 2: Oplijsting van het actief stroomverbruik.

| Actieve tijd/dag | Actieve stroom | Energie
Happy Gecko | 123,2 s | 5,52 mA | 2,244 J/dag
ADXL362 | 115,2 s | 1,80 µA | 0,000684 J/dag
Tempsensor | 24 s | 2,00 mA | 0,158J/dag
LoRaWAN | 8 s | 30 mA | 0,278 J/dag

De totale nodige energie die in actieve modus wordt verbruikt is dan 3, 19 J/dag

We herhalen dezelfde energieschatting voor de componenten in slaapmodus.

Tabel 3: Oplijsting van het slaapverbruik.

| Slapende tijd/dag | Slaapstroom | Energie
Happy Gecko | 86300 s | 0,95 µA | 0,185 J/dag
ADXL362 | 86300 s | 1,80 µA | 0,0768 J/dag
Tempsensor | 0 s | 0 mA | 0 J/dag
LoRaWAN | 0 s | 0 mA | 0 J/dag

De totale energie die al slapend wordt verbruikt is dan 0, 261 J/dag.

De totale geschatte energie voor één dag komt dus neer op | 3, 45 J/dag | .

### 3 Gebruik van een zonnepaneel en een batterij

### 3.1 Zonnepaneel

We zijn op zoek gegaan naar een zonnepaneel waarvan de afmetingen beperkt zijn zodat deze eenvoudig kan bevestigd worden op de boei waarover wij beschikken. We zijn uitgegaan van een boei met als afmetingen ongeveer 0,5 m diameter. Het zonnepaneel dat wij hiervoor geschikt zagen is een ANBES Solar Panel 5V.

Dit zonnepaneel levert in het beste geval 1,25 W aan 5 V. Idealiter zouden we dus 250 mA aan stroom kunnen leveren. De kostprijs bedraagt 1,85 euro. Het werken met zonnepanelen levert tal van voordelen. Zo zijn we in dit geval in staat om gebruik te maken van kleinere batterijen of mogelijks zelfs supercaps. De vermogensverbruiken van ons project zijn in paragraaf 2 te vinden.

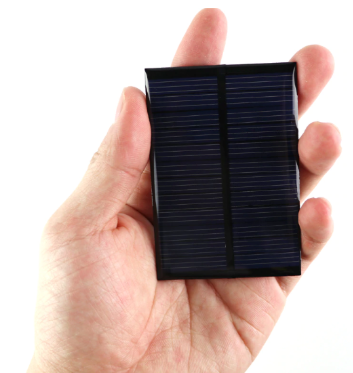
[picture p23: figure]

Figuur 1: Soortgelijk zonnepaneel dat gebruikt kan worden.

Alvorens we het vermogen, dat door het zonnepaneel wordt opgewekt, kunnen aanbieden aan een batterij, moeten we ervoor zorgen dat de spanning en de stroom niet te veel fluctueren. Een IC dat gespecialiseerd is in energy harvesting toepassingen maakt het mogelijk om de ingangsspanning, dewelke mogelijks te laag is om een batterij op te laden, te boosten tot een acceptabele spanning, of een spanning die te hoog is, met behulp van een buckconverter te reduceren tot de juiste spanning.

Een voorbeeld van zo een IC is de BQ25570 en kost ongeveer 6 euro. De grenswaarden voor de ingangsspanningen bedragen 100 mV tot maximaal 5,1 V, wat perfect te realiseren valt met het zonnepaneel waarvoor bij dit project geopteerd werd. De uitgangsspanning bedraagt 4,2 V en kan maximaal een stroom van 285 mA leveren aan de batterij. De spanningen en de stromen zijn ideaal voor het opladen van een gewone LiPo batterij.

### 3.2 Batterij

In combinatie met een zonnepaneel is er ook een batterij nodig om de momenten te overbruggen waarbij er onvoldoende energie geleverd wordt door het zonnepaneel. We gaan ervan uit dat de batterij twee weken zou moeten overleven voor hij weer opgeladen moet worden door het zonnepaneel. We maken eerst een berekening zodat we weten aan welke capaciteit onze batterij zal moeten voldoen.

14 dagen aan 3,45 J/dag.
E14dagen= 14 dagen ⋅ 3,45 J/dag = 48,40 J

Voor het berekenen van de batterijcapaciteit (in mAh) gebruiken we volgende formule.

Capaciteit =

Energie
3, 6 ⋅ V oltage

=

48, 40J
3, 6 ⋅ 3, 3V
= 4, 08mAh | (1)

De capaciteitswaarde die we nu gevonden hebben bevat niet veel marge voor onverwachte omstandigheden zoals bijvoorbeeld het degraderen van de batterij over de jaren heen. Daarom vermenigvuldigen we de capaciteit met nog een veiligheidsfactor. We kiezen hier voor een factor van 5. Dit betekent dat onze batterijcapaciteit nu 20,4 mAh zal worden. Om praktische redenen zullen we voor een batterij van 100 mAh kiezen.

Het kan ook aangewezen zijn om te weten hoe lang het duurt voor ons zonnepaneel onze batterij terug oplaad. Aangezien ons zonnepaneel een maximale output heeft van 1,25 W aan 5 V zal dit redelijk rap gebeuren.

t =

Energie ⋅ 5V
3, 3 ⋅ P ower

=

48, 40J ⋅ 5V
3, 3V ⋅ 1, 25W
= 58, 6sec | (2)

Het opladen kan dus gebeuren in minder dan één minuut in ideale omstandigheden.

### 4 Gebruik van een batterij

Het is ook mogelijk om enkel gebruik te maken van een batterij om ons systeem te voeden. Een batterij die voldoet aan onze eisen is cruciaal. In de volgende paragrafen zijn er enkele parameters besproken waar men rekening mee moet houden.

Vooreerst beginnen we met het berekenen van de benodigde energiecapaciteit die onze batterij zal moeten bevatten.

5 jaar = 1826 dagen aan 3,45 J/dag. E5jaar= 1826 dagen ⋅ 3,45 J/dag E5jaar = 6312 J

Voor het berekenen van de batterijcapaciteit (in mAh) gebruiken we volgende formule.

Capaciteit =

Energie
3.6 ⋅ V oltage

=

6312J
3.6 ⋅ 3.3V
= 531mAh | (3)

De capaciteitswaarde die we nu gevonden hebben bevat niet veel marge voor onverwachte omstandigheden zoals bijvoorbeeld het degraderen van de batterij over de jaren heen. Daarom vermenigvuldigen we de capaciteit met nog een veiligheidsfactor. We kiezen hier voor een factor van 5. Dit betekent dat onze batterijcapaciteit nu 2657 mAh zal worden. Als we voor een courante waarde gaan zal dit 3000 mAh worden.

### 4.1 Belangrijkste batterij-eigenschappen voor low-power applicaties

### 4.1.1 Chemische samenstelling

De nominale spanning van een galvanische cel wordt bepaald door de elektrochemische eigenschappen van de actieve chemicaliën die in de cel worden gebruikt. De uiteindelijke spanning op de output is afhankelijk van de belastingsstroom en de interne impedantie van de cel. Deze variëren met de temperatuur, de laadtoestand en de ouderdom van de cel[2].

Belangrijk voor onze toepassing is dat de nominale uitgangsspanning voldoende hoog (3,3V) en stabiel moet zijn.

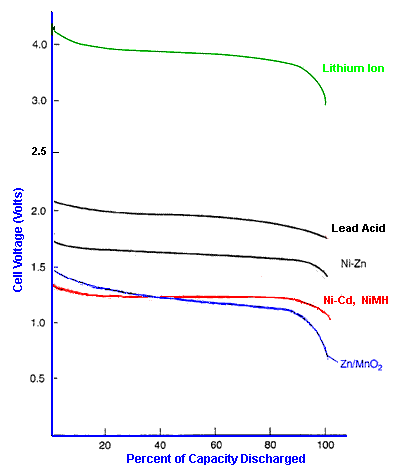
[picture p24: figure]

Figuur 2: Ontladingscurve van cellen met snelheid 0,2C[2].

Op de X-as staat het percentage van de celontlading, op de Y-as staat de celspanning. Een vlakke ontladingscurve betekent dat de geleverde voedingsspanning stabiel is en betrouwbaar gebruikt kan worden.

### 4.1.2 Temperatuursafhankelijkheid

De batterijprestaties kunnen sterk veranderen afhankelijk van de temperatuur. Batterijen met een waterachtig elektrolyt kunnen zelf bevriezen wanneer men deze blootstelt aan extreem lage temperaturen. Gelukkig heeft zeewater een vrij stabiele temperatuur die niet in de extrema liggen.

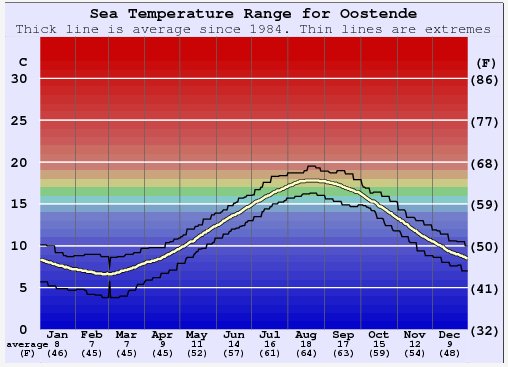
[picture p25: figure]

Figuur 3: Zee temperatuur per Jaar (Oostende) [4]

De temperatuur schommelt tussen maxima’s van 4-19 °C.

### 4.1.3 Zelfontlading

De zelfontlading van een cel is de maat waarin de cel ontlaadt tijdens het liggen op het schap (shelf life). Dit is te wijten aan ongewenste chemische reacties binnen in de cel. De snelheid waarmee de cel ontlaadt hangt af van het type cel en de temperatuur.

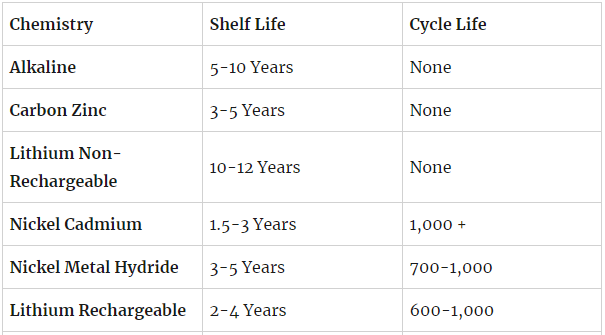
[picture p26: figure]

Figuur 4: Shelf life batterijen[3].

Voor deze studie bekijken we niet heroplaadbare batterijen: Alkaline en Lithium Ion. Beide voldoen aan ons 5 jaar battery life plan.

### 4.1.4 Temperatuur en interne veranderingen

Battery internal resistance

Een batterij met een lage interne weerstand levert een hoge stroom. Een hoge interne weerstand zorgt ervoor dat de batterij opwarmt en de spanning daalt. Dit komt omdat er een spanningsval over de interne weerstand staat.

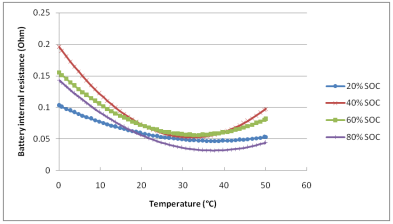
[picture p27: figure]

Figuur 5: Interne weerstand van een Li-ion batterij als functie van T and SOC [5].

Als de temperatuur stijgt, zal de interne weerstand dalen. Met de grafiek kunnen we besluiten dat de interne weerstand het laagst zal zijn tussen de 20-40 °C. De interne weerstand zal ook dalen als de state of charge (SOC) daalt.

De optimale bedrijfstemperatuur voor de lithium-ion batterij bevindt zich nog steeds in het bereik van 20-65 °C.

Ontlading

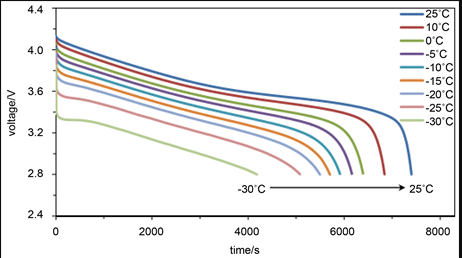
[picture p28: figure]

Figuur 6: 0.5C rate discharge curve of Li-ion battery at different temperatures. [6]

Op figuur 6 valt af te lezen dat een lage temperatuur zorgt voor een kortere levensduur. Dit is zo het geval bij eender welke onlaadstroom. Er is een correlatie met de interne weerstand van de batterij die zal toenemen.

Ook hier constateren we dat we voor een lithium-ion batterij een hogere bedrijfstemperatuur willen hebben (25 °C).

### 4.2 Besluit batterij

Voor dit project zullen we een lithium-ion batterij gebruiken. Dit is de aangeraden batterij voor low-power, low-cost applications die een hoge energiedensiteit nodig hebben. De lange shelf time, het laag gewicht, het feit dat er geen vloeibaar elektroliet in zit en een stabiele spanning zorgen ervoor dat hij de juiste keuze is[1].

### 5 Supercap

Aangezien we dagelijks een cyclus van op- en ontladen van de batterij meemaken hebben we overwogen om eventueel een supercap te gebruiken. We hadden twee mogelijke opties om de supercap te benutten.

In een eerste geval zouden we de supercap gebruiken als tijdelijke energiebuffer voor de batterij. Dit voorkomt dat de batterij te snel zal degraderen door de vele cycli van op- en ontladen. Als andere mogelijkheid zouden we de supercap proberen gebruiken als batterijvervanger.

Bij het gebruik van supercaps krijgen we enkele belangrijke voordelen:

- Geen last van geheugeneffecten zoals batterijen hebben bij meerdere cycli.
- Geen gevaar voor overladen door het zonnepaneel bij bijvoorbeeld aanhoudend zonnige dagen, als de maximale toegelaten spanning van de supercap niet overtroffen wordt door het zonnepaneel.
- Supercaps kunnen op korte tijd weer worden opgeladen, slechts enkele minuten zon kunnen volstaan.

Aangezien de batterij bij ons project niet genoeg cycli zal doormaken kunnen we het gebruik van een supercap moeilijk rechtvaardigen. Daarnaast is de zelfontlading van de supercap te hoog, waardoor onze module uit zou kunnen vallen wanneer de zon lang achterwege blijft. Deze criteria wegen meer door bij onze beslissing om bij een gewone batterij te blijven.

### 6 Besluit

Het gebruik van een zonnepaneel zal zeker voordelig zijn voor toepassingen waarbij een node een lange tijd niet onderhouden wordt of in een geval waarbij de batterij amper zal moeten vervangen worden. Een zonnepaneel zal echter wel zorgen voor extra elektrische circuits, componenten en onderzoek naar het gedrag ervan. Het is volgens onze berekeningen mogelijk om 5 jaar te overbruggen met een batterij van ongeveer 3000 mAh, wat voor ons project meer dan lang genoeg is. Hierdoor opteren we om enkel een batterij te gebruiken.

### Referenties

[1] MPower UK, Batteries and Other Energy Storage Devices, https://www.mpoweruk.com/battery_types.htm
[2] MPower UK, Battery Performance Characteristics, https://www.mpoweruk.com/performance.htm?fbclid=IwAR3y-4mZMLxQVONijRlM1yGxG8LP9hXsIWE0GZksDUSexI2pdqmQeVQ6FVM (https://www.mpoweruk.com/performance.htm)
[3] Battery Universe, How long should batteries last?, https://www.batteryuniverse.com/blog/tags/shelf-life/
[4] Surf-forecast.com, Oostende Water Temperature and Wetsuit Guide
(North Sea – Belgium), http://www.surf-forecast.com/breaks/Oostende/seatemp
[5] Universiti Teknologi Malaysia, The impact of battery operating temperature and state of charge on the lithium-ion battery internal resistance, https://mech.utm.my/wp-content/uploads/2017/12/1-THE-IMPACT-OF-BATTERY-OPERATING-TEMPERATURE-AND-STATE-OF-CHARGE-ON-THE-LITHIUM-ION-BATTERY-INTERNAL-RESISTANCE.pdf (https://mech.utm.my/wp-content/uploads/2017/12/1-THE-IMPACT-OF-BATTERY-OPERATING-TEMPERATURE-AND-STATE-OF-CHARGE-ON-THE-LITHIUM-ION-BATTERY-INTERNAL-RESISTANC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)
[6] Scientific Research Open Access, Study on Low Temperature Performance of Li-Ion Battery, https://file.scirp.org/Html/80512_80512.htm#f1

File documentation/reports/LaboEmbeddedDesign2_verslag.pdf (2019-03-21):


faculty of engineering technology

– gent –

### EMBEDDED SYSTEM DESIGN 2 – LABO

masterplan

# Project ‘Ter Zee’

### Brecht Van Eeckhoudt – Sarah Goossens – Matthias Alleman Benjamin Van der Smissen – Arno Plaetinck

MELICTE

### 1 maart 2019

Embedded System Design 2 – Labo: Masterplan: Project ‘Ter Zee’

### Inhoudsopgave

2 van 9

### 1 Concept

Team ‘Ter Zee’ heeft de verantwoordelijkheid om een totaalconcept uit te werken dat het mogelijk maakt om de watertemperatuur en golfsterkte te meten, te verwerken en door te sturen. Verder zal het team ook in staat moeten zijn om de drift van een boei waar te nemen. De temperatuursmeting zullen we doen met behulp van de DS18B20 die wordt uitgelezen met behulp van een Happy Gecko. De drift van de boei zullen we trachten te achterhalen met behulp van een simpele maar toch ingenieuze methode. De golfsterkte meten we met behulp van de accelerometer ADXL362. We bespreken alle sensoren uitgebreider in een paragraaf die nog volgt.

Alle sensoren zullen gelijktijdig actief moeten zijn en we zullen in het totaalconcept ook zeer nauwkeurig letten op het vermogenverbruik aangezien het niet de bedoeling is dat de batterijen waarvan we gebruik zullen maken regelmatig moeten vervangen worden. Als kers op de taart is bij ons de extra moeilijkheid dat ons systeem bestand moet zijn tegen het zoute water van de zee. Een aangepast behuizing die zowel water als zout resistent is, zal dus één van onze uitdagingen worden.

Het blokschema van het concept is afgebeeld op figuur 1.


Figuur 1: Blokschema van het concept.

### 2 Specificaties

### 2.1 Functioneel technische specificaties

- Watertemperatuur meten.
- Drift van een boei detecteren.
- De grootte van de golven meten.
- Data verzamelen, verwerken en doorsturen naar het vaste land.
- Nauwkeurigheid temperatuursmeting: 0,5 °C.
- Elk uur wordt het systeem gewekt en voert het zijn functie uit.

– In geval van een storm wordt het systeem onmiddellijk gewekt via een interrupt van de accelerometer.

– Het systeem gaat telkens terug in slaap van zodra alle functies afgerond zijn.

### 2.2 Niet functioneel technische specificaties

- We kiezen voor een zeer energiezuinige implementatie en schakelen onderdelen van het ontwerp uit op momenten dat deze niet nodig zijn.
- De batterij moet minstens 1 jaar meegaan.
- De gehele ontwerp, zonder temperatuursensor zal in een behuizing van ongeveer 10×10×10 cm moeten passen.
- Het geheel weegt ongeveer 500 gram.
- Behuizing moet bestand zijn tegen zout water.
- Alle componenten en verbindingen moeten goed bevestigd zijn zodat ze tegen een stootje van de wilde golven kunnen.
- De componenten moeten temperaturen verdragen tussen de -30 °C en de +100°C.

### 2.3 Niet technische specificaties

- De NRE-kosten zijn 0 aangezien er geen lonen in rekening worden gebracht.
- Variabele kost:
1. Happy Gecko – 25 euro
2. Temperatuurssensor – 10 euro
3. Accelerometer – 15 euro
4. Driftdetector – 1 euro
5. LoRa-module – 10 euro
6. Batterij – 12 euro
7. Behuizing – 10 euro

Totaal: 83 euro

- Testkost – 0 euro daar er geen lonen in rekening worden gebracht.
- Tijd tot eerste prototype – 2 maand
- Tijd tot eerste product – 3 maand
- Tijd tot massaproductie – niet van toepassing

### 3 Sensoren

### 3.1 Temperatuursensor DS18B20

Om de temperatuur van het water te meten, zullen we gebruik maken van de temperatuursensor DS18B20, zoals afgebeeld in figuur 2. Deze sensor geeft als resultaat de digitale waarde van de temperatuur in 9 tot 12 bits. Er kan een temperatuur gemeten worden tussen -55 °C en +125 °C. De sensor is daarenboven ook waterdicht. Verdere tests zullen uitwijzen of de sensor ook bestand is tegen het zeewater. Indien zou blijken dat dit niet het geval is, wordt hiervoor een oplossing gezocht.

De sensor zal communiceren met de Happy Gecko via One Wire. Om batterij te sparen zal slechts op bepaalde tijdstippen de temperatuur van het water gemeten worden, nl. om het uur. De Happy Gecko geeft telkens opdracht aan de sensor om de temperatuur te meten. De sensor stuurt hierop een digitale waarde naar de Happy Gecko, die deze temperatuur zal omzetten in een aantal graden Celsius zodat deze waarde naar het vasteland kan gestuurd worden en daar correct geïnterpreteerd kan worden.


Figuur 2: Temperatuursensor DS18B20. Figuur 3: ADXL362 accelerometer op het breakoutbord.

### 3.2 Accelerometer ADXL362

Om de Happy Gecko, in het geval van een storm, wakker te maken uit zijn slaaptoestand zullen we gebruik maken van een ADXL362 accelerometer die een interrupt zal sturen naar de microcontroller. Dit is een ultra low power MEMS accelerometer die in 3 assen de acceleratie kan meten. Deze sensor laat het ook toe om de golfslag en golf-frequentie te meten.

Voor dit labo is er gebruik gemaakt van het Sparkfun breakoutbord van deze sensor, zodat de sensor gemakkelijk aan het ontwikkelbord gekoppeld kan worden. De sensor kan gevoed worden met een spanning tussen de 1,6V en 3,5V en kan dus rechtstreeks verbonden worden met het development bordje. De meting van de sensorwaarde wordt digitaal doorgestuurd via SPI.

### 3.3 Driftsensor – eigen ontwerp

De drift van een boei zullen we detecteren aan de hand van een zelfontworpen sensor. De sensor zal bestaan uit een draad die op een bepaalde spanning gehouden wordt. Deze draad zal verwikkeld zijn in de schakels van de ketting waaraan de boei bevestigd is, op het moment dat een boei loskomt van zijn ketting zal de spanning op de pin waarmee de kabel verbonden is, wegvallen , doordat het draadje breekt, waardoor wij zullen weten dat de boei op drift is. Een extra veiligheidsmechanisme zullen we mogelijks inbouwen zodat de boei niet direct wegdrift, maar dat de boei nog enige tijd op zijn plaats blijft.

### 4 LoRaWAN

Om data vanop zee door te sturen naar ‘de cloud’ moet er gebruik gemaakt worden van een communicatie protocol met twee belangrijke specificaties. De communicatie-range moet groot zijn, en de toepassing moet energiezuinig werken.

LoRaWAN is een long-range wireless communication protocol gebruikt om data over lange afstanden te versturen. Dit is onder andere mogelijk doordat LoRaWAN een lage data rate heeft (onder 50kbps). Hierdoor is LoRaWAN enkel een goede keuze voor energiezuinige en non-real time applicaties.

### 5 Behuizing

Voor het ontwerp van de behuizing zullen we voornamelijk op zoek gaan naar materialen die bestand zijn tegen corrosie van het zoute water van de Noordzee. We zullen dus rekening moeten houden met de vijsjes en het materiaal waaruit de behuizing gemaakt wordt. We hebben daarvoor een 3D-printer ter onze beschikking om dit te ontwerpen.

### 6 Verantwoordelijkheden

### 6.1 Technologie

Temperatuursensor Sarah

Breekbare draad Matthias

Levensduurscalculatie Arno

Powermanagement Brecht

LoraWAN-connectie Benjamin

Behuizing Matthias

Accelerometer Brecht

### 6.2 Project

Time-manager Matthias

Integratie-manager Brecht

Verslagmanager Sarah

Presentatiemanager Arno

Externe communicatie Benjamin

### 7 Mijlpalen

Tabel 1: De vooropgestelde planning.

Datum | Opdracht
1 maart 2019 | Uitdenken concept, opstellen mas-
terplan en kiezen van componenten.
4 maart 2019 - 29 maart 2019 Uittesten | van | de | verschillende
aparte onderdelen, werking controleren en debuggen.

1 april 2019 - 26 april 2019 Samenbrengen van de verschillende onderdelen tot één geheel, werking controleren en debuggen.

29 april 2019 - 10 mei 2019 Outdoor test op de campus en eventuele bijsturing

16 mei 2019 | Presentatie
24 mei 2019 | ‘Go live’ – Plaatsen en testen van
het ontworpen systeem ter plaatse.

### Referenties

[1] Github, Project Labo Embedded System Design 1,
https: // github .com/ Fescron/ Project-LabEmbeddedDesign1 (https://github.com/Fescron/Project-LabEmbeddedDesign1)
[2] DS18B20, DS18B20 datasheet,
https: // datasheets .maximintegrated .com/ en/ ds/ DS18B20 .pdf (https://datasheets.maximintegrated.com/en/ds/DS18B20.pdf)

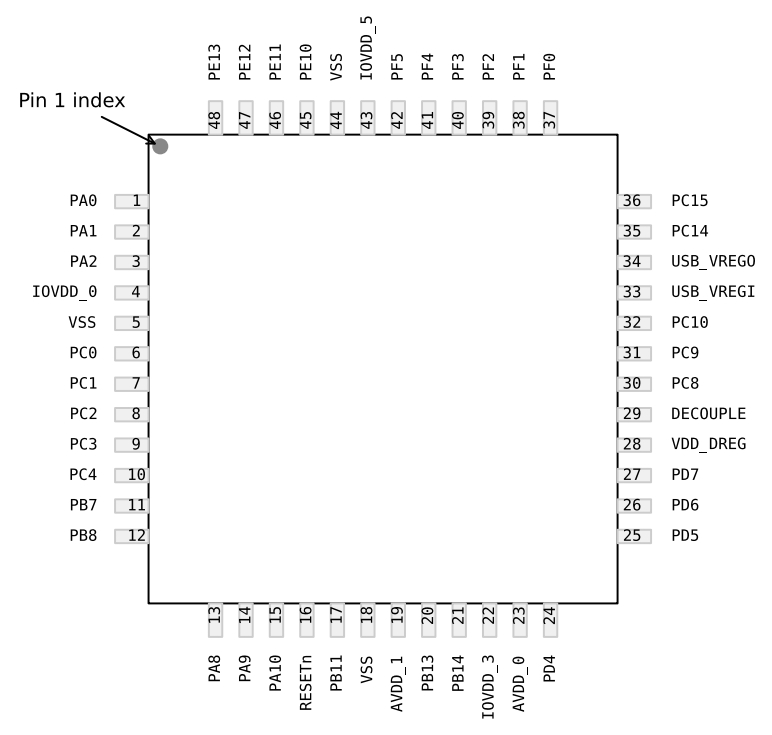
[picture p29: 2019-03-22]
hardware/project-embeddedSystemDesign2/EFM32HG322-TQFP48.jpg

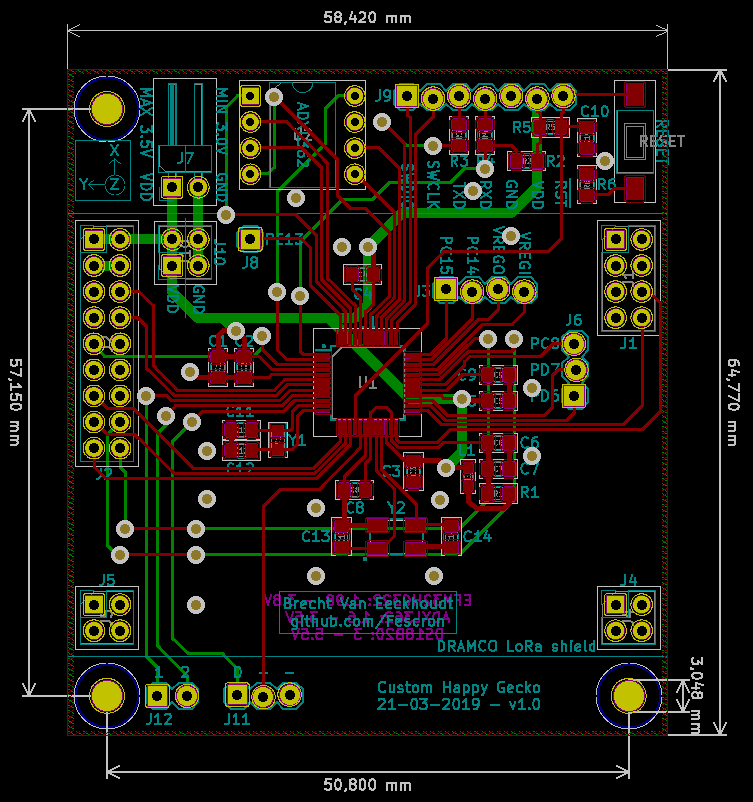
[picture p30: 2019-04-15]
hardware/project-embeddedSystemDesign2/3d-renders/project-embeddedSystemDesign2-pcb-dimensions.png

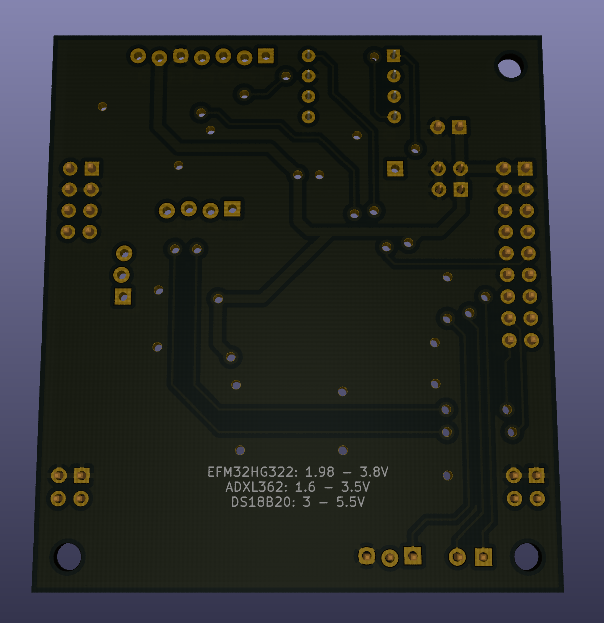
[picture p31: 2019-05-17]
hardware/project-embeddedSystemDesign2/3d-renders/project-embeddedSystemDesign2-raytracing-back.png

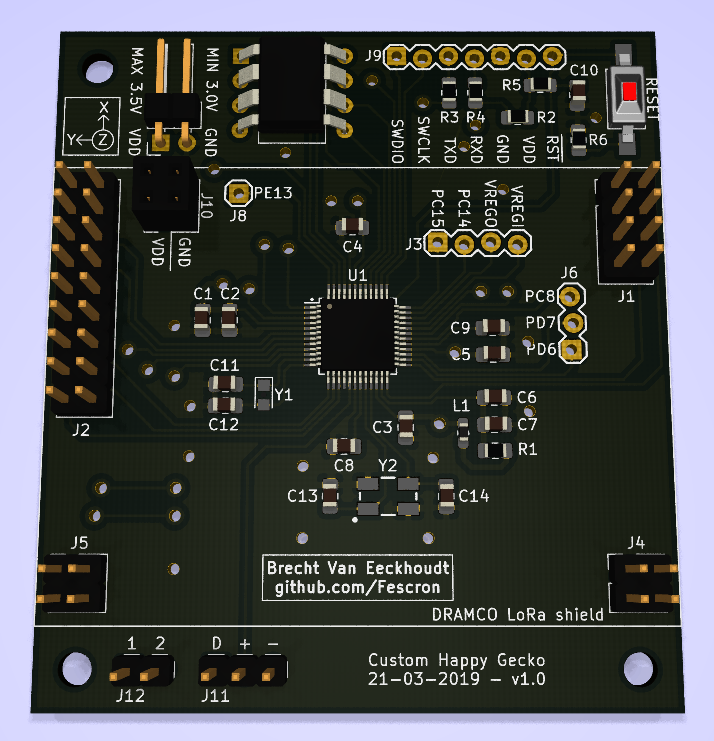
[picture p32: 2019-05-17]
hardware/project-embeddedSystemDesign2/3d-renders/project-embeddedSystemDesign2-raytracing.png

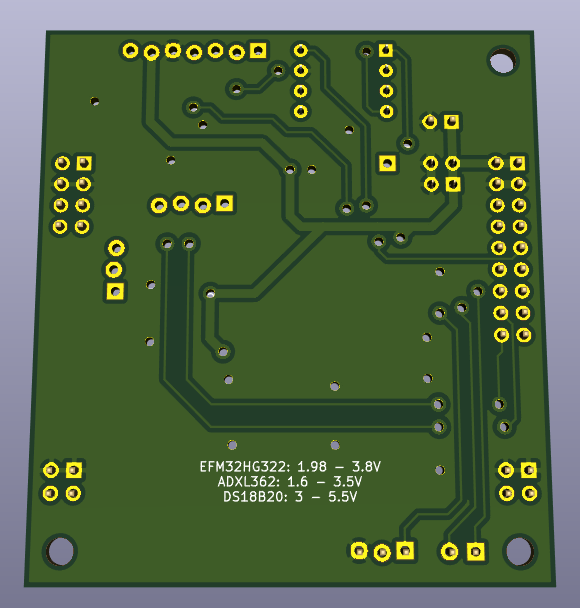
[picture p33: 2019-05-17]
hardware/project-embeddedSystemDesign2/3d-renders/project-embeddedSystemDesign2-back.png

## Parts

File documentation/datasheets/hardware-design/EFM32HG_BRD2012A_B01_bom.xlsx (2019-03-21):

P/N: | BRD2012A
Revision: | B01
Description: | EFM32 Happy Gecko Starter Kit
Revised: | Friday, March 27, 2015
Item | Quantity | Reference | Value | Manufacturer | Manufacturers Part Number | Tolerance | Rating | Technology | Not Mounted
1 | 5 | C100,C101,C610,C1001,C1003 | 1N | Murata | GRM155 |  | 16V | X7R
2 | 56 | C102,C103,C104,C105,C106,C107,C108,C408,C409,C410,C411,C600,C603,C604,C605,C606,C611,C660,C701,C702,C704,C706,C707,C710,C721,C724,C726,C727,C728,C730,C733,C734,C736,C739,C740,C741,C742,C744,C800,C803,C804,C805,C806,C807,C808,C810,C891,C904,C910,C911,C912,C913,C914,C916,C917,C920 | 100N | Murata | GRM155 |  | 16V | X7R
3 | 4 | C400,C401,C608,C609 | 1U | Murata | GRM18 |  | 10V | X5R
4 | 1 | C402 | 4U7 | Murata | GRM21 |  | 25V | X5R
5 | 15 | C404,C415,C601,C607,C700,C703,C714,C719,C720,C725,C731,C732,C735,C907,C915 | 10U | Murata | GRM21 |  | 10V | X5R
6 | 9 | C405,C406,C650,C718,C738,C890,C905,C908,C909 | 10N | Murata | GRM155 |  | 16V | X7R
7 | 2 | C417,C418 | 12P | Murata | GRM155 |  | 50V | C0G
8 | 4 | C421,C422,C900,C901 | 18P | Murata | GRM155 |  | 50V | C0G
9 | 2 | C602,C705 | 33N | Murata | GRM155 |  | 16V | X7R
10 | 2 | C729,C737 | 10N | Murata | GRM155 |  | 16V | X7R | NM
11 | 1 | C743 | 22U | Murata | GRM21 |  | 10V | X5R
12 | 2 | C902,C903 | 12P | Murata | GRM155 |  | 50V | C0G
13 | 2 | C1002,C1004 | 10P | Murata | GRM155 |  | 50V | C0G
14 | 1 | DISP1 | LS013B7DH03 | SHARP | LS013B7DH03
15 | 1 | D400 | PRTR5V0U2F | NXP Semiconductors | PRTR5V0U2F,115
16 | 1 | D600 | IP4220CZ6 | NXP Semiconductors | IP4220CZ6,125
17 | 1 | D703 | LM4040CIM3-3.0 | National | LM4040CIM3-3.0/NOPB
18 | 2 | D705,D800 | VESD05A8A-HNH | Vishay Semiconductors | VESD05A8A-HNH
19 | 1 | D801 | PESD5V0F5UF | NXP Semiconductors | PESD5V0F5UF,115
20 | 2 | J101,J102 | HEADER_2X16_2.54MM_TH |  |  |  |  |  | NM
21 | 3 | LED100,LED101,LED900 | YELLOW | Würth Electronics | 150060YS75000
22 | 1 | LED901 | BLUE | Panasonic | LNJ926W8CRA
23 | 1 | LED903 | RED | Würth Electronics | 150060RS75000
24 | 1 | LED904 | LED_G_R | Avago | HSMF-C165
25 | 9 | L400,L700,L702,L703,L780,L800,L801,L900,L1001 | CBF102WB | Würth Electronics | 74279266
26 | 2 | L401,L600 | CBF221HC | Würth Electronics | 742792022
27 | 1 | M1 | HOLE_PTH_3MM |  |  |  |  |  | NM
28 | 2 | M2,M3 | HOLE_TH_3MM |  |  |  |  |  | NM
29 | 2 | M4,M5 | 25x4mm | Parafix | PAR220812RB1
30 | 1 | PCB1 | PCB2012 |  | PCB2012 Rev. B00
31 | 1 | P100 | HEADER_2X10_2.54MM_HOR_SMD | Taitek | HE2-20G6C394-5R
32 | 1 | P101 | XF2L-1025-1A_MEMLCD | OMRON | XF2L-1025-1A
33 | 1 | P400 | USB MICRO-B | Hirose | ZX62-B-5PA(11)
34 | 1 | P601 | WR_COM_USB_MINI_B | Würth Electronics | 651 005 161 21
35 | 1 | P700 | COIN_CELL | Keystone | 3002
36 | 1 | P701 | HEADER_2X10_1.27MM_SMD | Sullins | GRPB102VWQS
37 | 1 | P800 | HEADER_DEBUG_ETM | Samtec | FSTH-110-01-L-DV-K-P-TR
38 | 1 | Q700 | BSS84 | Diodes Inc. | BSS84DW-7-F
39 | 1 | Q701 | DMN5L06 | Diodes Inc. | DMN5L06DWK-7
40 | 1 | Q702 | BC846BWT1G | ON Semiconductor | BC846BWT1G
41 | 1 | Q703 | NTS210 | ON Semiconductor | NTS2101PT1G
42 | 1 | Q800 | DMN5L06WK | Diodes Inc. | DMN5L06WK-7
43 | 2 | RP800,RP801 | 33R | ROHM | MNR04M0APJ330
44 | 6 | R100,R103,R129,R728,R810,R811 | 100R
45 | 6 | R101,R102,R109,R708,R742,R815 | 1M
46 | 8 | R104,R111,R119,R748,R779,R786,R915,R916 | 0R
47 | 4 | R105,R118,R610,R814 | 10M
48 | 16 | R106,R603,R604,R605,R606,R611,R612,R650,R651,R652,R681,R735,R800,R816,R890,R891 | 100K |  |  | 1%
49 | 3 | R107,R108,R900 | 3K
50 | 1 | R110 | 10M |  |  |  |  |  | NM
51 | 11 | R112,R113,R600,R609,R623,R700,R729,R739,R782,R785,R914 | 10K |  |  | 1%
52 | 8 | R114,R115,R607,R608,R727,R774,R807,R808 | 4K7
53 | 2 | R116,R734 | 510K |  |  | 1%
54 | 9 | R128,R682,R705,R743,R772,R783,R792,R919,R920 | 1K
55 | 3 | R403,R731,R910 | 1R
56 | 2 | R405,R406 | 15R
57 | 2 | R601,R702 | 180K
58 | 2 | R602,R703 | 110K
59 | 4 | R621,R627,R745,R747 | 0R |  |  |  |  |  | NM
60 | 1 | R622 | 47R |  |  | 1%
61 | 2 | R701,R740 | 4R7 | Bourns | CRT1206-BY-4R7-ELFTR | 0.10%
62 | 1 | R706 | 15K
63 | 1 | R707 | 33K
64 | 4 | R709,R710,R732,R733 | 1K8 | YAGEO | RT0603BRD071K8L | 0.10%
65 | 2 | R717,R736 | 10R
66 | 2 | R718,R737 | 12K | YAGEO | RT0603BRD0712KL | 0.10%
67 | 1 | R738 | 8K2
68 | 1 | R741 | 51K |  |  | 1%
69 | 1 | R744 | 22K
70 | 1 | R746 | 2R2
71 | 1 | R760 | 330K |  |  | 1%
72 | 2 | R781,R805 | 33R
73 | 1 | R801 | 47K
74 | 1 | R809 | 100K |  |  | 1% |  |  | NM
75 | 1 | R901 | 1K5
76 | 2 | R902,R904 | 22R
77 | 2 | R903,R912 | 2K
78 | 2 | R917,R918 | 4K7 |  |  |  |  |  | NM
79 | 2 | R1002,R1007 | 6K2
80 | 2 | R1003,R1008 | 62R
81 | 3 | R1004,R1009,R1010 | 51K | YAGEO | RT0603BRD0751KL | 0.10%
82 | 1 | R1005 | 160R | YAGEO | RT0603BRD07160RL | 0.10%
83 | 1 | ST1 | 2X1 2.54MM |  |  |  |  |  | NM
84 | 2 | SW100,SW101 | WS_TSS_6X6MM_SMD | Würth Electronics | 430 182 043 816
85 | 1 | SW103 | WS_TASV_6X3.5MM_SMD | Würth Electronics | 434 121 043 816
86 | 1 | SW104 | SW_DP3T | ALPS | SSSS223600
87 | 1 | TPH999 | PROTO_TH |  |  |  |  |  | NM
88 | 3 | TPJ403,TPJ404,TPJ405 | TP_SMD
89 | 54 | TP150,TP151,TP152,TP153,TPJ600,TPJ606,TPJ607,TPJ608,TPJ611,TPJ612,TPJ613,TPJ614,TPJ650,TPJ651,TPJ652,TPJ653,TP700,TP701,TP702,TP705,TP706,TP707,TP708,TP710,TP711,TP712,TP713,TP714,TPJ811,TPJ812,TPJ813,TPJ814,TPJ817,TPJ818,TPJ820,TPJ900,TPJ901,TPJ902,TP903,TPJ905,TPJ908,TPJ909,TPJ910,TPJ911,TPJ912,TPJ913,TP923,TPJ950,TPJ951,TPJ952,TPJ953,TPJ954,TPJ955,TPJ956 | TP_SMD |  |  |  |  |  | NM
90 | 6 | TP154,TP156,TP400,TP401,TP703,TP709 | TP_SMD |  |  |  |  |  | NM
91 | 2 | T1,T2 | TOUCH |  |  |  |  |  | NM
92 | 1 | U1 | EFM32HG322F64 | Silicon Laboratories | EFM32HG322F64
93 | 1 | U100 | TS3A44159 | Texas Instruments | TS3A44159RSVR
94 | 2 | U101,U707 | TS3A24159 | Texas Instruments | TS3A24159YZPR
95 | 1 | U102 | Si7021-A10 | Silicon Laboratories | Si7021-A10-GM1
96 | 5 | U103,U602,U650,U702,U805 | TS3A4751 | Texas Instruments | TS3A4751RUCR
97 | 2 | U600,U701 | LP3982ILD-ADJ | National Semiconductor | LP3982ILDX-ADJ
98 | 1 | U601 | 24AA024 | Microchip | 24AA024-I/MS
99 | 1 | U603 | TLV70536 | Texas Instruments | TLV70536YFP
100 | 4 | U604,U800,U802,U806 | 74LVC4066 | NXP | 74LVC4066BQ,115
101 | 5 | U660,U661,U803,U804,U809 | 74LVC2G125 | Texas Instruments | SN74LVC2G125YZPR
102 | 1 | U700 | NX3V1G66 | NXP | NX3V1G66GM
103 | 2 | U703,U705 | LTC6102CDD | National Semiconductor | LTC6102CDD#PBF
104 | 1 | U704 | TS5A23167 | Texas Instruments | TS5A23167YZP
105 | 1 | U706 | MCP6001T | Microchip Technology | MCP6001T-I/LT
106 | 2 | U708,U709 | TS5A23166 | Texas Instruments | TS5A23166YZPR
107 | 1 | U808 | 74LVC8T245 | Texas Instruments | SN74LVC8T245RHL
108 | 1 | U900 | Control MCU
109 | 1 | U902 | M25PX16 | Numonyx | M25PX16-VMP6E
110 | 1 | U1000 | AD8656 | Analog Devices Inc | AD8656ARMZ
111 | 1 | X400 | 24 MHz | NDK | NX3225GA-24.000MHz
112 | 1 | X401 | 32.768kHz | Micro Crytstal AG | CM8V-T1A, 32768Hz, 12.5pF, +/- 20ppm
113 | 1 | X900 | 16MHz | NDK | NX3225GA-16.000MHZ

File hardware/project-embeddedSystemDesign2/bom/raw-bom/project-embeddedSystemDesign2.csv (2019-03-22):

Source: | /home/brecht/Qsync/Documents/1 - School/2018 - 2019/Semester 2/Embedded system design 2 - labo/project-embeddedSystemDesign2/project-embeddedSystemDesign2.sch
Date: | vr 22 mrt 2019 00:52:19 CET
Tool: | Eeschema 5.1.0-060a0da~80~ubuntu18.10.1
Generator: | /usr/share/kicad/plugins/bom_csv_grouped_by_value.py
Component Count: | 41
Individual Components:
Item | Qty | Reference(s) | Value | LibPart | Footprint | Datasheet | Class | Load capacitance | Placement | Tolerance
 |  | C1 | 10 µF | Device:C_Small | Capacitor_SMD:C_0805_2012Metric_Pad1.15x1.40mm_HandSolder | ~ |  |  | IOVDD_0
 |  | C2 | 100 nF | Device:C_Small | Capacitor_SMD:C_0805_2012Metric_Pad1.15x1.40mm_HandSolder | ~ |  |  | IOVDD_0
 |  | C3 | 100 nF | Device:C_Small | Capacitor_SMD:C_0805_2012Metric_Pad1.15x1.40mm_HandSolder | ~ |  |  | IOVDD_3
 |  | C4 | 100 nF | Device:C_Small | Capacitor_SMD:C_0805_2012Metric_Pad1.15x1.40mm_HandSolder | ~ |  |  | IOVDD_5
 |  | C5 | 100 nF | Device:C_Small | Capacitor_SMD:C_0805_2012Metric_Pad1.15x1.40mm_HandSolder | ~ |  |  | VDD_DREG
 |  | C6 | 10 µF | Device:C_Small | Capacitor_SMD:C_0805_2012Metric_Pad1.15x1.40mm_HandSolder | ~ |  |  | AVDDD_0
 |  | C7 | 10 nF | Device:C_Small | Capacitor_SMD:C_0805_2012Metric_Pad1.15x1.40mm_HandSolder | ~ |  |  | AVDD_0
 |  | C8 | 10 nF | Device:C_Small | Capacitor_SMD:C_0805_2012Metric_Pad1.15x1.40mm_HandSolder | ~ |  |  | AVDD_1
 |  | C9 | 1 µF | Device:C_Small | Capacitor_SMD:C_0805_2012Metric_Pad1.15x1.40mm_HandSolder | ~ | X5R |  | DECOUPLE
 |  | C10 | 100 nF | Device:C_Small | Capacitor_SMD:C_0805_2012Metric_Pad1.15x1.40mm_HandSolder | ~
 |  | C11 | 18 pF | Device:C_Small | Capacitor_SMD:C_0805_2012Metric_Pad1.15x1.40mm_HandSolder | ~
 |  | C12 | 18 pF | Device:C_Small | Capacitor_SMD:C_0805_2012Metric_Pad1.15x1.40mm_HandSolder | ~
 |  | C13 | 12 pF | Device:C_Small | Capacitor_SMD:C_0805_2012Metric_Pad1.15x1.40mm_HandSolder | ~
 |  | C14 | 12 pF | Device:C_Small | Capacitor_SMD:C_0805_2012Metric_Pad1.15x1.40mm_HandSolder | ~
 |  | H1 | MountingHole | Mechanical:MountingHole | MountingHole:MountingHole_3mm | ~
 |  | H2 | MountingHole | Mechanical:MountingHole | MountingHole:MountingHole_3mm | ~
 |  | H3 | MountingHole | Mechanical:MountingHole | MountingHole:MountingHole_3mm | ~
 |  | J1 | Conn_02x04_Odd_Even | Connector_Generic:Conn_02x04_Odd_Even | Connector_PinHeader_2.54mm:PinHeader_2x04_P2.54mm_Vertical | ~
 |  | J2 | Conn_02x09_Odd_Even | Connector_Generic:Conn_02x09_Odd_Even | Connector_PinHeader_2.54mm:PinHeader_2x09_P2.54mm_Vertical | ~
 |  | J3 | Conn_01x04 | Connector_Generic:Conn_01x04 | Connectors:1X04_LOCK | ~
 |  | J4 | Conn_02x02_Odd_Even | Connector_Generic:Conn_02x02_Odd_Even | Connector_PinHeader_2.54mm:PinHeader_2x02_P2.54mm_Vertical | ~
 |  | J5 | Conn_02x02_Odd_Even | Connector_Generic:Conn_02x02_Odd_Even | Connector_PinHeader_2.54mm:PinHeader_2x02_P2.54mm_Vertical | ~
 |  | J6 | Conn_01x03 | Connector_Generic:Conn_01x03 | Connectors:1X03_LOCK | ~
 |  | J7 | Conn_01x02 | Connector_Generic:Conn_01x02 | Connector_PinHeader_2.54mm:PinHeader_1x02_P2.54mm_Horizontal | ~
 |  | J8 | Conn_01x01 | Connector_Generic:Conn_01x01 | Connectors:1X01 | ~
 |  | J9 | Conn_01x07 | Connector_Generic:Conn_01x07 | Connectors:1X07_LOCK | ~
 |  | J10 | Conn_02x02_Odd_Even | Connector_Generic:Conn_02x02_Odd_Even | Connector_PinSocket_2.54mm:PinSocket_2x02_P2.54mm_Vertical | ~
 |  | J11 | Conn_01x03 | Connector_Generic:Conn_01x03 | Connectors:1X03_LOCK | ~
 |  | J12 | Conn_01x02 | Connector_Generic:Conn_01x02 | Connectors:1X02_LOCK | ~
 |  | L1 | CBF102WB | Device:L_Core_Ferrite_Small | Inductor_SMD:L_0603_1608Metric_Pad1.05x0.95mm_HandSolder | ~
 |  | R1 | 1 Ω | Device:R_Small | Resistor_SMD:R_0805_2012Metric_Pad1.15x1.40mm_HandSolder | ~
 |  | R2 | 10 kΩ | Device:R_Small | Resistor_SMD:R_0805_2012Metric_Pad1.15x1.40mm_HandSolder | ~
 |  | R3 | 100 Ω | Device:R_Small | Resistor_SMD:R_0805_2012Metric_Pad1.15x1.40mm_HandSolder | ~
 |  | R4 | 100 Ω | Device:R_Small | Resistor_SMD:R_0805_2012Metric_Pad1.15x1.40mm_HandSolder | ~
 |  | R5 | 1 kΩ | Device:R_Small | Resistor_SMD:R_0805_2012Metric_Pad1.15x1.40mm_HandSolder | ~
 |  | R6 | 100 Ω | Device:R_Small | Resistor_SMD:R_0805_2012Metric_Pad1.15x1.40mm_HandSolder | ~
 |  | SW1 | SW_Push | Switch:SW_Push | Button_Switch_SMD:SW_SPST_FSMSM | ~
 |  | U1 | EFM32HG322 | MCU_SiliconLabs-extra:EFM32HG322 | Package_QFP:LQFP-48_7x7mm_P0.5mm
 |  | U2 | ADXL362-breakout | Sensor_Breakout:ADXL362-breakout | Package_DIP:DIP-8_W10.16mm
 |  | Y1 | 32,768 kHz | Device:Crystal_Small | Crystal:Crystal_SMD_2012-2Pin_2.0x1.2mm_HandSoldering | ~ |  | 12,5 pF |  | +- 20 ppm
 |  | Y2 | 24 MHz | Device:Crystal_GND24_Small | Clocks:CRYSTAL-SMD-5X3.2-4PAD | ~ |  | 8 pF |  | +- 20 ppm
Collated Components:
Item | Qty | Reference(s) | Value | LibPart | Footprint | Datasheet | Class | Load capacitance | Placement | Tolerance
1 | 2 | C1, C6 | 10 µF | Device:C_Small | Capacitor_SMD:C_0805_2012Metric_Pad1.15x1.40mm_HandSolder | ~ |  |  | IOVDD_0
2 | 5 | C2, C3, C4, C5, C10 | 100 nF | Device:C_Small | Capacitor_SMD:C_0805_2012Metric_Pad1.15x1.40mm_HandSolder | ~ |  |  | IOVDD_0
3 | 2 | C7, C8 | 10 nF | Device:C_Small | Capacitor_SMD:C_0805_2012Metric_Pad1.15x1.40mm_HandSolder | ~ |  |  | AVDD_0
4 | 1 | C9 | 1 µF | Device:C_Small | Capacitor_SMD:C_0805_2012Metric_Pad1.15x1.40mm_HandSolder | ~ | X5R |  | DECOUPLE
5 | 2 | C11, C12 | 18 pF | Device:C_Small | Capacitor_SMD:C_0805_2012Metric_Pad1.15x1.40mm_HandSolder | ~
6 | 2 | C13, C14 | 12 pF | Device:C_Small | Capacitor_SMD:C_0805_2012Metric_Pad1.15x1.40mm_HandSolder | ~
7 | 3 | H1, H2, H3 | MountingHole | Mechanical:MountingHole | MountingHole:MountingHole_3mm | ~
8 | 1 | J1 | Conn_02x04_Odd_Even | Connector_Generic:Conn_02x04_Odd_Even | Connector_PinHeader_2.54mm:PinHeader_2x04_P2.54mm_Vertical | ~
9 | 1 | J2 | Conn_02x09_Odd_Even | Connector_Generic:Conn_02x09_Odd_Even | Connector_PinHeader_2.54mm:PinHeader_2x09_P2.54mm_Vertical | ~
10 | 1 | J3 | Conn_01x04 | Connector_Generic:Conn_01x04 | Connectors:1X04_LOCK | ~
11 | 2 | J4, J5 | Conn_02x02_Odd_Even | Connector_Generic:Conn_02x02_Odd_Even | Connector_PinHeader_2.54mm:PinHeader_2x02_P2.54mm_Vertical | ~
12 | 2 | J6, J11 | Conn_01x03 | Connector_Generic:Conn_01x03 | Connectors:1X03_LOCK | ~
13 | 1 | J7 | Conn_01x02 | Connector_Generic:Conn_01x02 | Connector_PinHeader_2.54mm:PinHeader_1x02_P2.54mm_Horizontal | ~
14 | 1 | J8 | Conn_01x01 | Connector_Generic:Conn_01x01 | Connectors:1X01 | ~
15 | 1 | J9 | Conn_01x07 | Connector_Generic:Conn_01x07 | Connectors:1X07_LOCK | ~
16 | 1 | J10 | Conn_02x02_Odd_Even | Connector_Generic:Conn_02x02_Odd_Even | Connector_PinSocket_2.54mm:PinSocket_2x02_P2.54mm_Vertical | ~
17 | 1 | J12 | Conn_01x02 | Connector_Generic:Conn_01x02 | Connectors:1X02_LOCK | ~
18 | 1 | L1 | CBF102WB | Device:L_Core_Ferrite_Small | Inductor_SMD:L_0603_1608Metric_Pad1.05x0.95mm_HandSolder | ~
19 | 1 | R1 | 1 Ω | Device:R_Small | Resistor_SMD:R_0805_2012Metric_Pad1.15x1.40mm_HandSolder | ~
20 | 1 | R2 | 10 kΩ | Device:R_Small | Resistor_SMD:R_0805_2012Metric_Pad1.15x1.40mm_HandSolder | ~
21 | 3 | R3, R4, R6 | 100 Ω | Device:R_Small | Resistor_SMD:R_0805_2012Metric_Pad1.15x1.40mm_HandSolder | ~
22 | 1 | R5 | 1 kΩ | Device:R_Small | Resistor_SMD:R_0805_2012Metric_Pad1.15x1.40mm_HandSolder | ~
23 | 1 | SW1 | SW_Push | Switch:SW_Push | Button_Switch_SMD:SW_SPST_FSMSM | ~
24 | 1 | U1 | EFM32HG322 | MCU_SiliconLabs-extra:EFM32HG322 | Package_QFP:LQFP-48_7x7mm_P0.5mm
25 | 1 | U2 | ADXL362-breakout | Sensor_Breakout:ADXL362-breakout | Package_DIP:DIP-8_W10.16mm
26 | 1 | Y1 | 32,768 kHz | Device:Crystal_Small | Crystal:Crystal_SMD_2012-2Pin_2.0x1.2mm_HandSoldering | ~ |  | 12,5 pF |  | +- 20 ppm
27 | 1 | Y2 | 24 MHz | Device:Crystal_GND24_Small | Clocks:CRYSTAL-SMD-5X3.2-4PAD | ~ |  | 8 pF |  | +- 20 ppm

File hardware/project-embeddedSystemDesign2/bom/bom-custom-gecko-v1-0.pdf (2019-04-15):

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

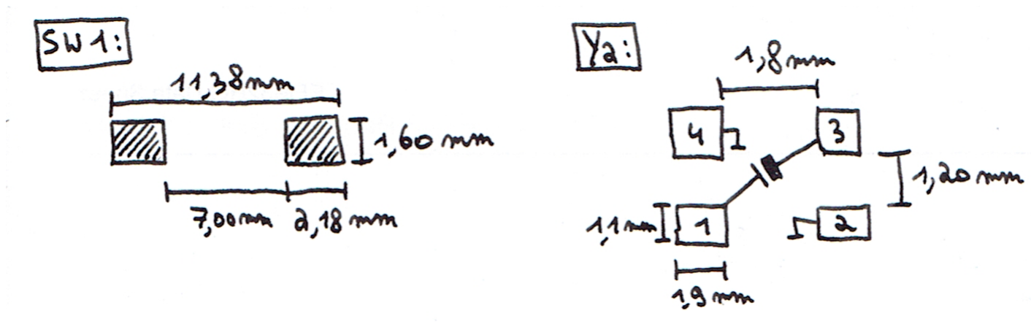
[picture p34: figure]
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

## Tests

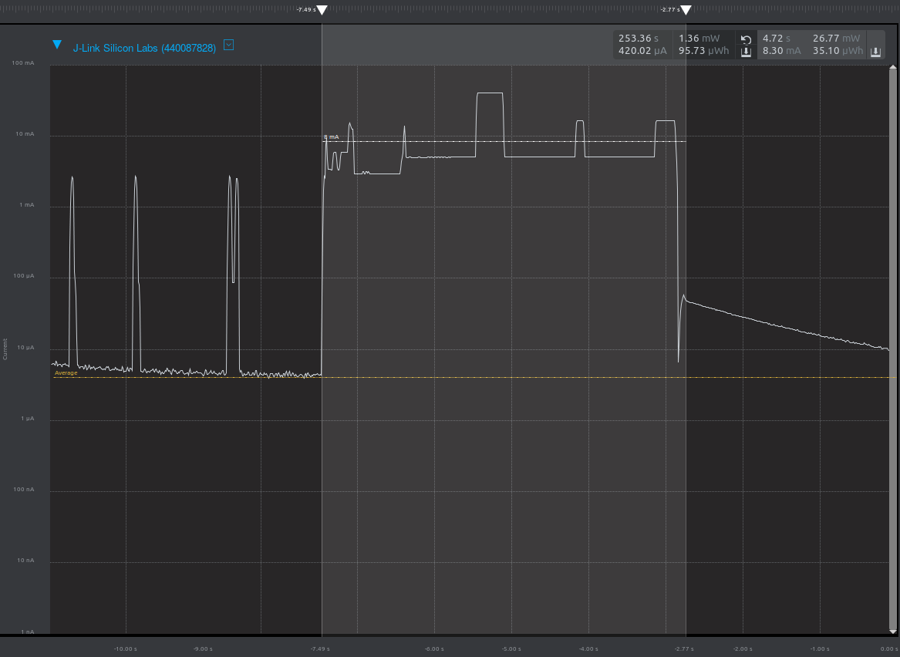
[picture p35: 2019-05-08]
documentation/current measurements/measurements-SF/SF09.png

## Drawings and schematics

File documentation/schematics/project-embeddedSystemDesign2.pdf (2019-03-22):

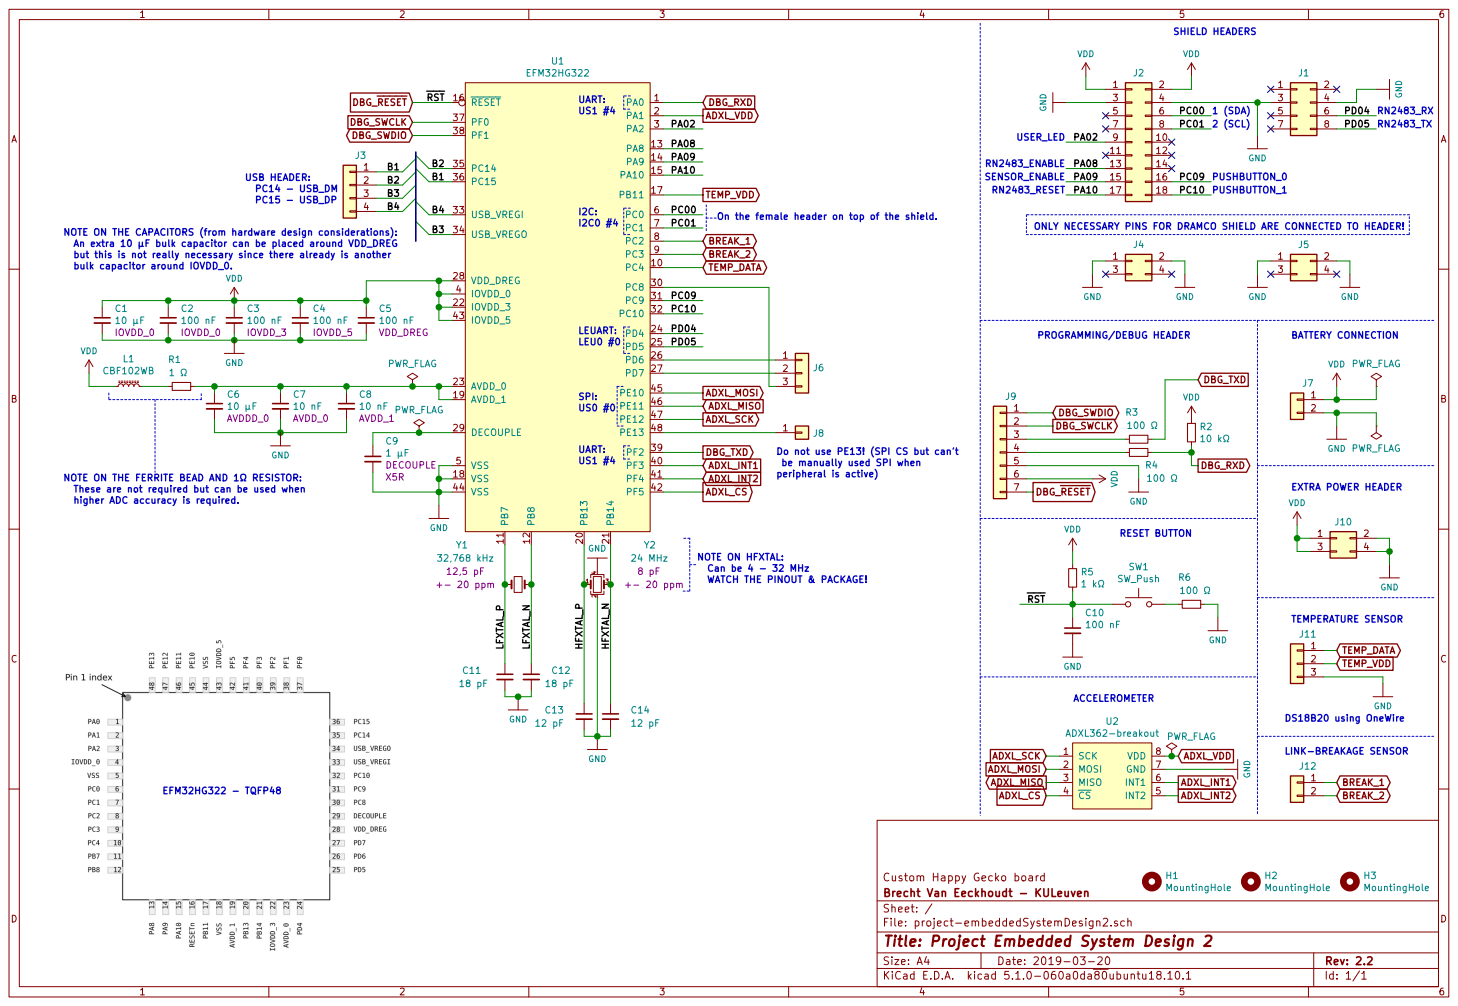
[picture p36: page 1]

On the female header on top of the shield. 1

WATCH THE PINOUT & PACKAGE! NOTE ON THE CAPACITORS (from hardware design considerations):
An extra 10 µF bulk capacitor can be placed around VDD_DREG
but this is not really necessary since there already is another
bulk capacitor around IOVDD_0. NOTE ON THE FERRITE BEAD AND 1 RESISTOR:

Do not use PE13! (SPI CS but can't
be manually used SPI when

These are not required but can be used when
higher ADC accuracy is required. EFM32HG322 - TQFP48

DS18B20 using OneWire BREAK_1 BREAK_2 LINK-BREAKAGE SENSOR

File: project-embeddedSystemDesign2.sch Sheet: / Brecht Van Eeckhoudt - KULeuven Custom Happy Gecko board

Id: 1/1 Title: Project Embedded System Design 2

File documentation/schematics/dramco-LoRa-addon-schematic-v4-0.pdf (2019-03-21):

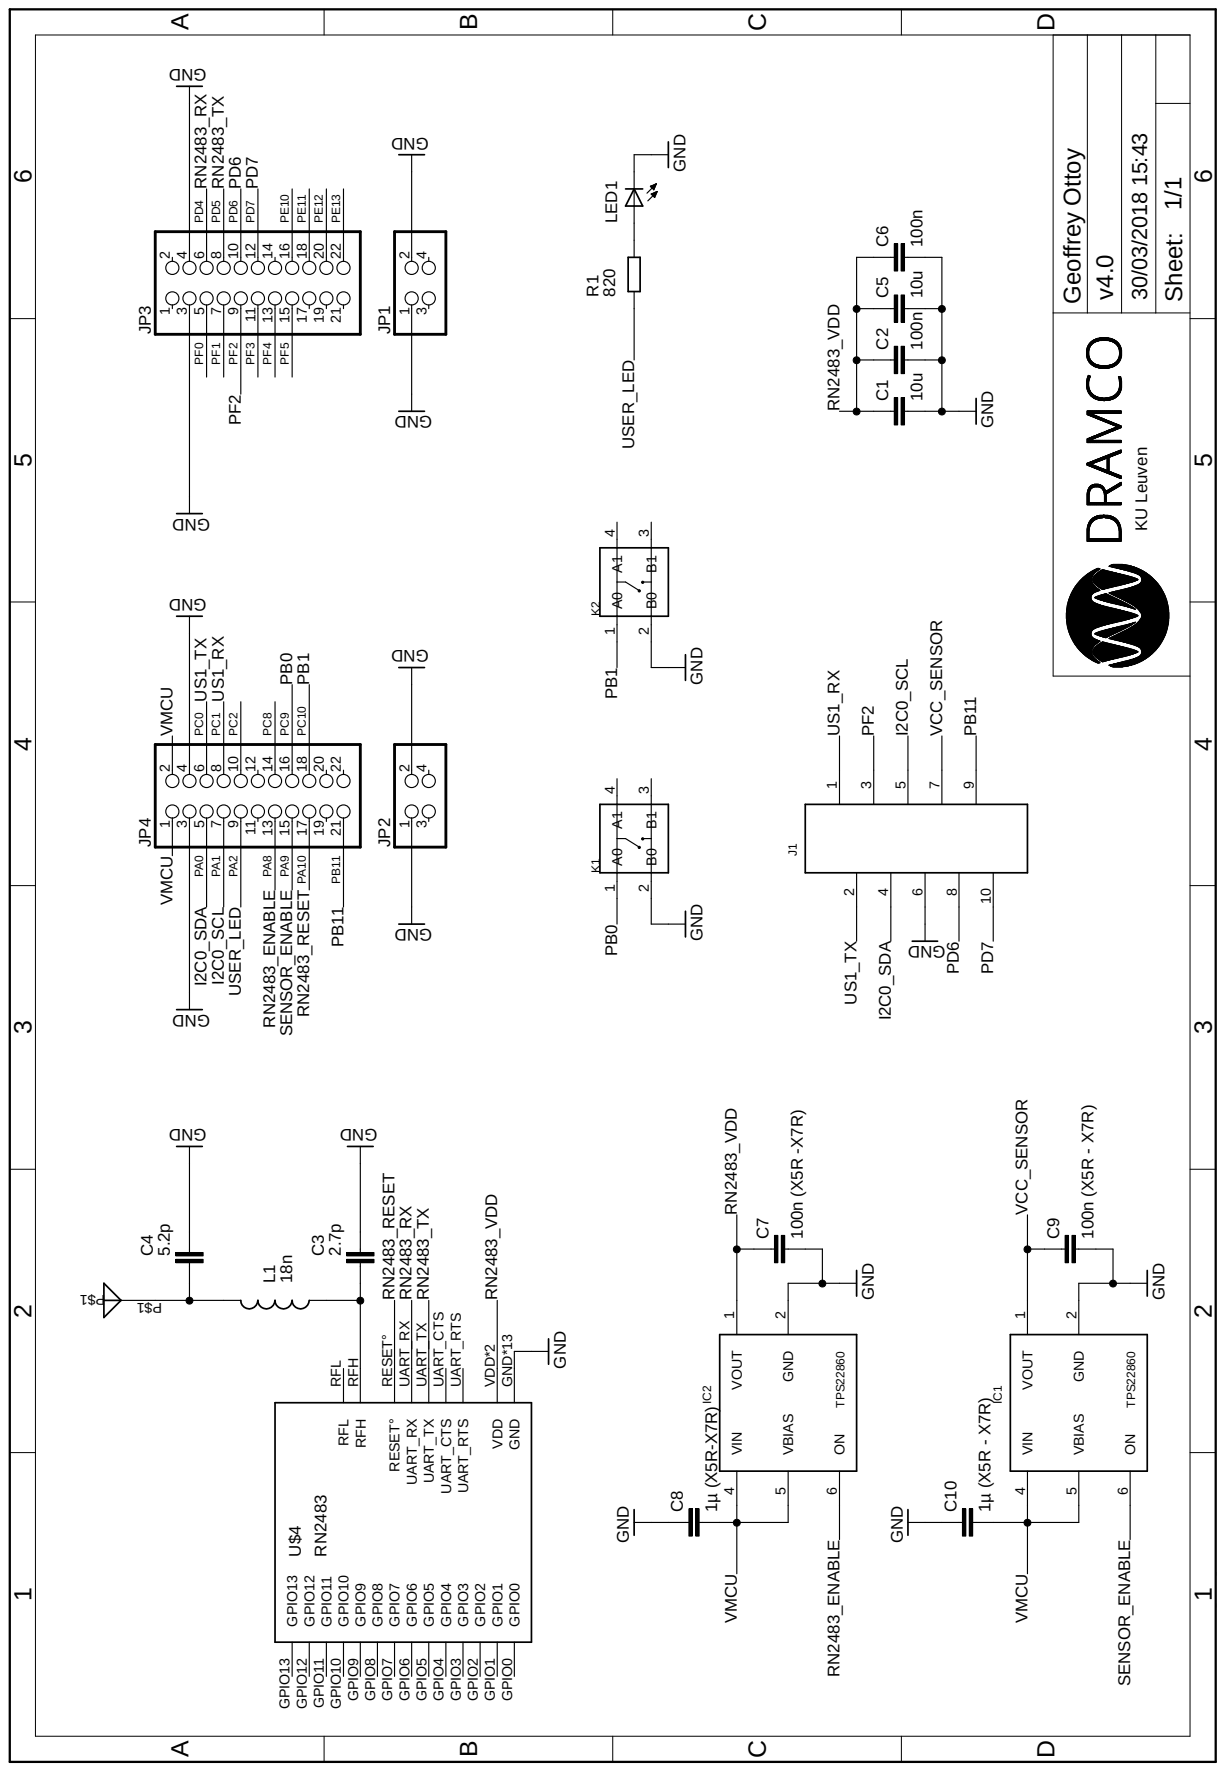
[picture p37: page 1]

P$1 P$1 L1 C5 C6 JP11 2 3 4 JP21 2 3 4 JP31 2 3 4 5 6 7 8 9 10 11 12 13 14 15 16 17 18 19 20 21 22 JP41 2 3 4 5 6 7 8 9 10 11 12 13 14 15 16 17 18 19 20 21 22 VOUT 1 GND 2 VIN 4 VBIAS 5 ON 6 IC1VOUT 1 GND 2 VIN 4 VBIAS 5 ON 6 IC2 C7 C9 C8 C10 VMCU VMCU VMCU VMCU PC0 PC1 PC2 PC8 PC9 PC10 PA0 PA1 PA2 PA8 PA9 PA10 PB11 PB11 PD4 PD5 PD6 PD6 PD6 PD7 PD7 PD7 PE10 PE11 PE12 PE13 PF0 PF1 PF2 PF2 PF2 PF3 PF4 PF5 VCC_SENSOR RN2483_VDD VCC_SENSOR RN2483_VDD RN2483_VDD v4.0 30/03/2018 15:43 1/1 Sheet: ABCD 1 2 3 4 5 6 ABCD 1 2 3 4 5 6

GND GND 18n 10u 100n GND TPS22860 TPS22860 GND 100n (X5R -X7R) 100n (X5R - X7R) 1µ (X5R-X7R) 1µ (X5R - X7R) GND GND I2C0_SDA I2C0_SCL PB0 PB1 PB11 RN2483_RESET RN2483_RX RN2483_TX RN2483_RX RN2483_TX RN2483_RESET I2C0_SCL I2C0_SDA US1_TX US1_RX US1_TX US1_RX PB0 PB1 USER_LED USER_LED SENSOR_ENABLE RN2483_ENABLE RN2483_ENABLE SENSOR_ENABLE C1 C2 GND GND*13 UART_TX UART_TX UART_RX UART_RX VDD VDD*2 RFH RFH RFL RFL RESET° RESET° U$4 UART_CTS UART_CTS UART_RTS UART_RTS GPIO0 GPIO0 GPIO1 GPIO1 GPIO2 GPIO2 GPIO3 GPIO3 GPIO4 GPIO4 GPIO5 GPIO5 GPIO6 GPIO6 GPIO7 GPIO7 GPIO8 GPIO8 GPIO9 GPIO9 GPIO10 GPIO10 GPIO11 GPIO11 GPIO12 GPIO12 GPIO13 GPIO13 J1 10 9 8 7 6 5 4 3 2 1 K1A0 1 A1 4 B0 2 B1 3 K2A0 1 A1 4 B0 2 B1 3 R1 LED1 C4 C3

GND GND GND 820 GND 5.2p 2.7p

Geoffrey Ottoy KU Leuven 10u 100n GND RN2483 GND

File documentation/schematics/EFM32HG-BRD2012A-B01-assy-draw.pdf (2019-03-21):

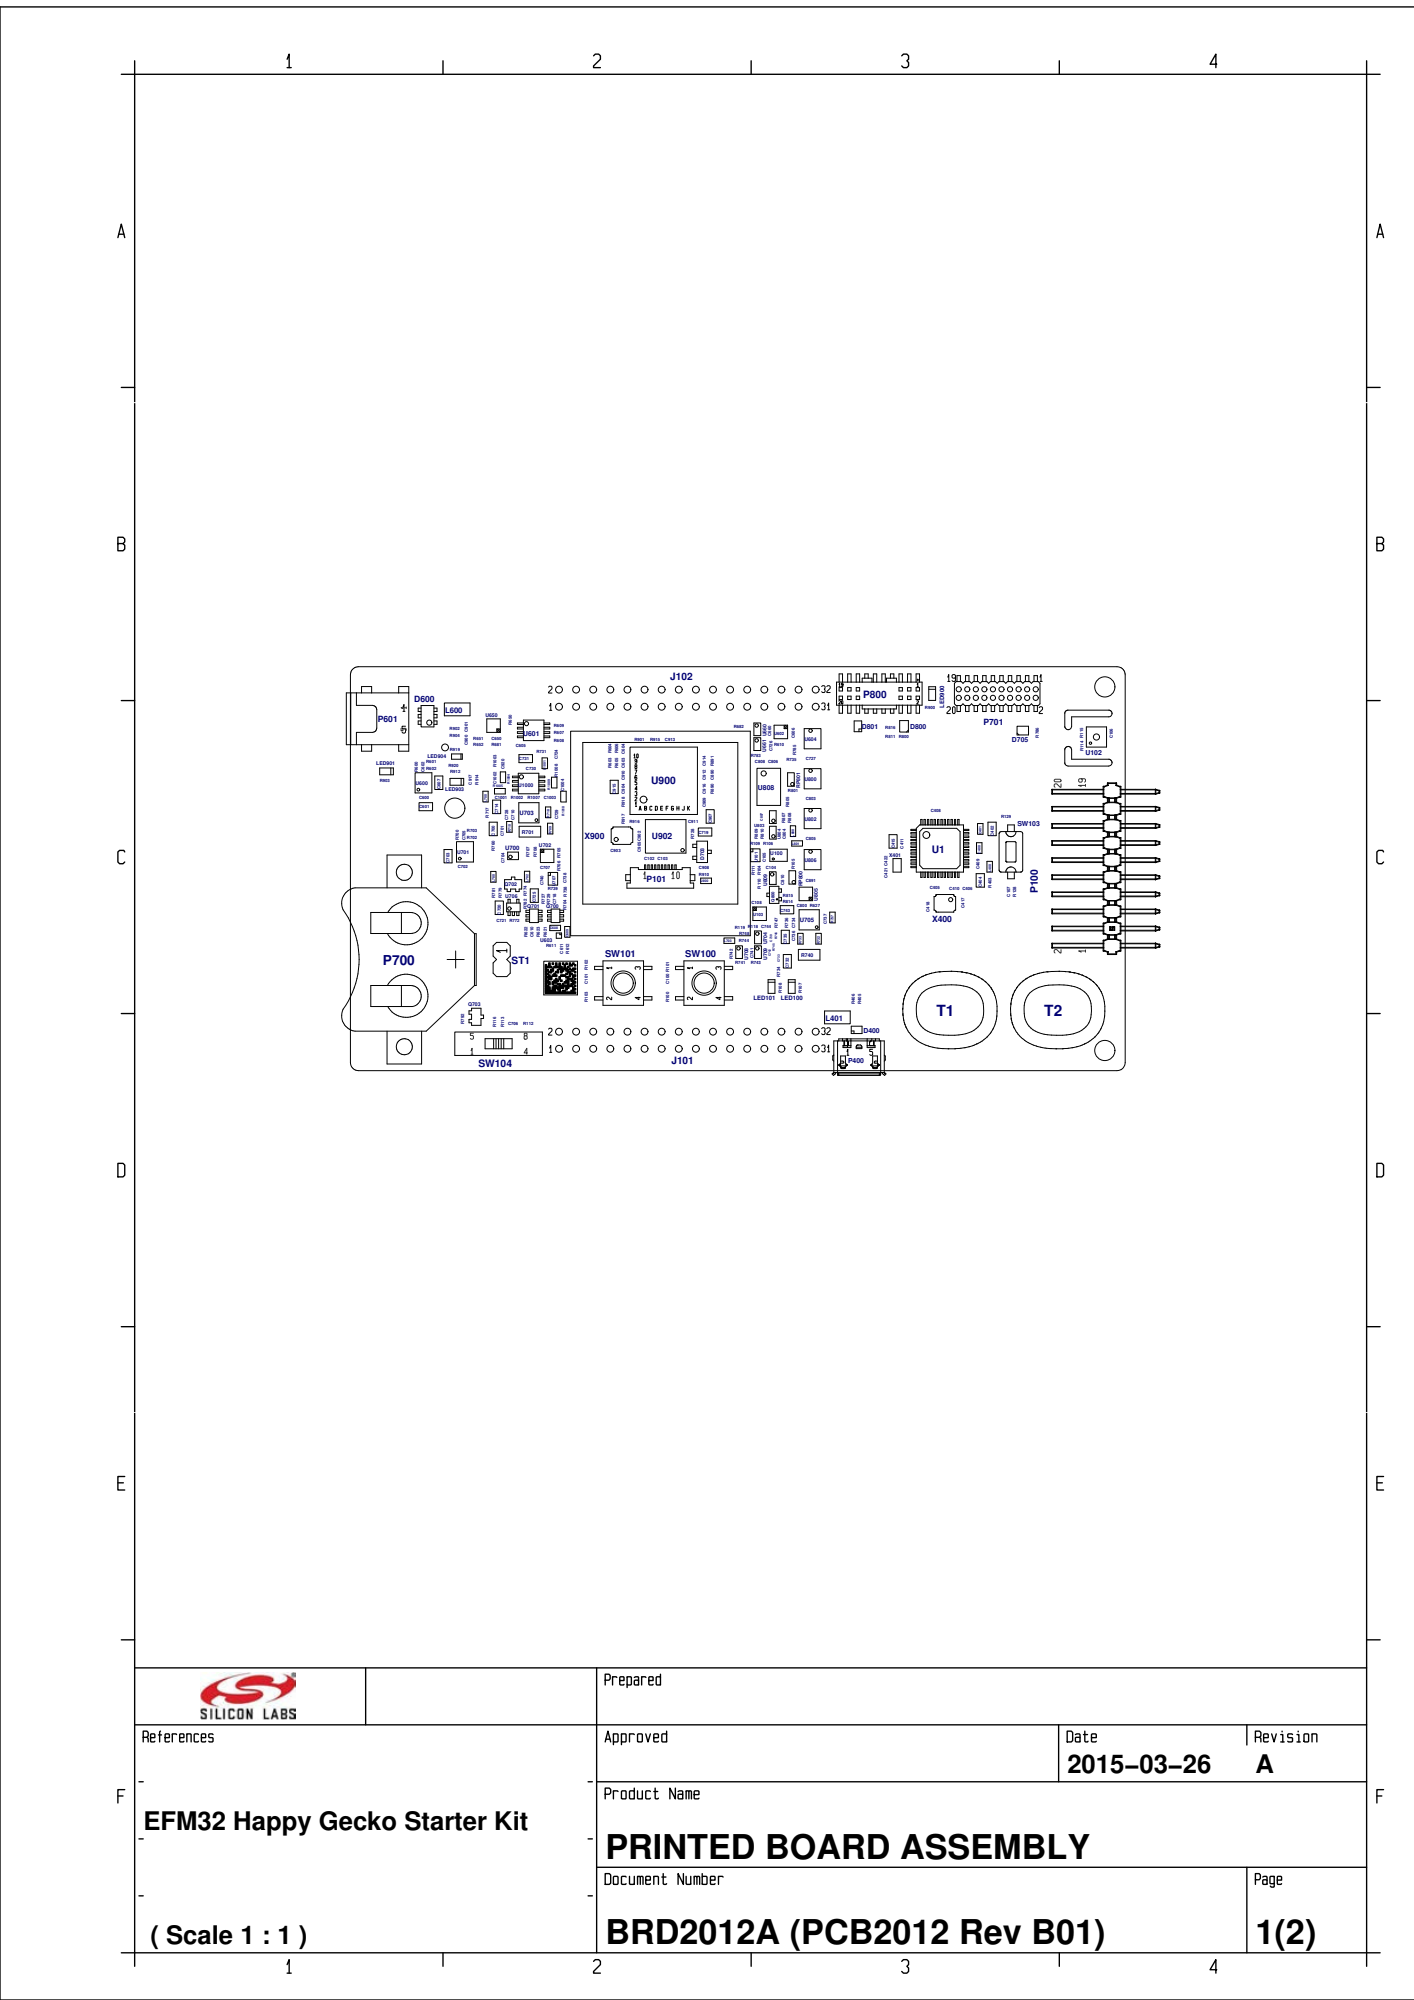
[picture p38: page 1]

EFM32 Happy Gecko Starter Kit

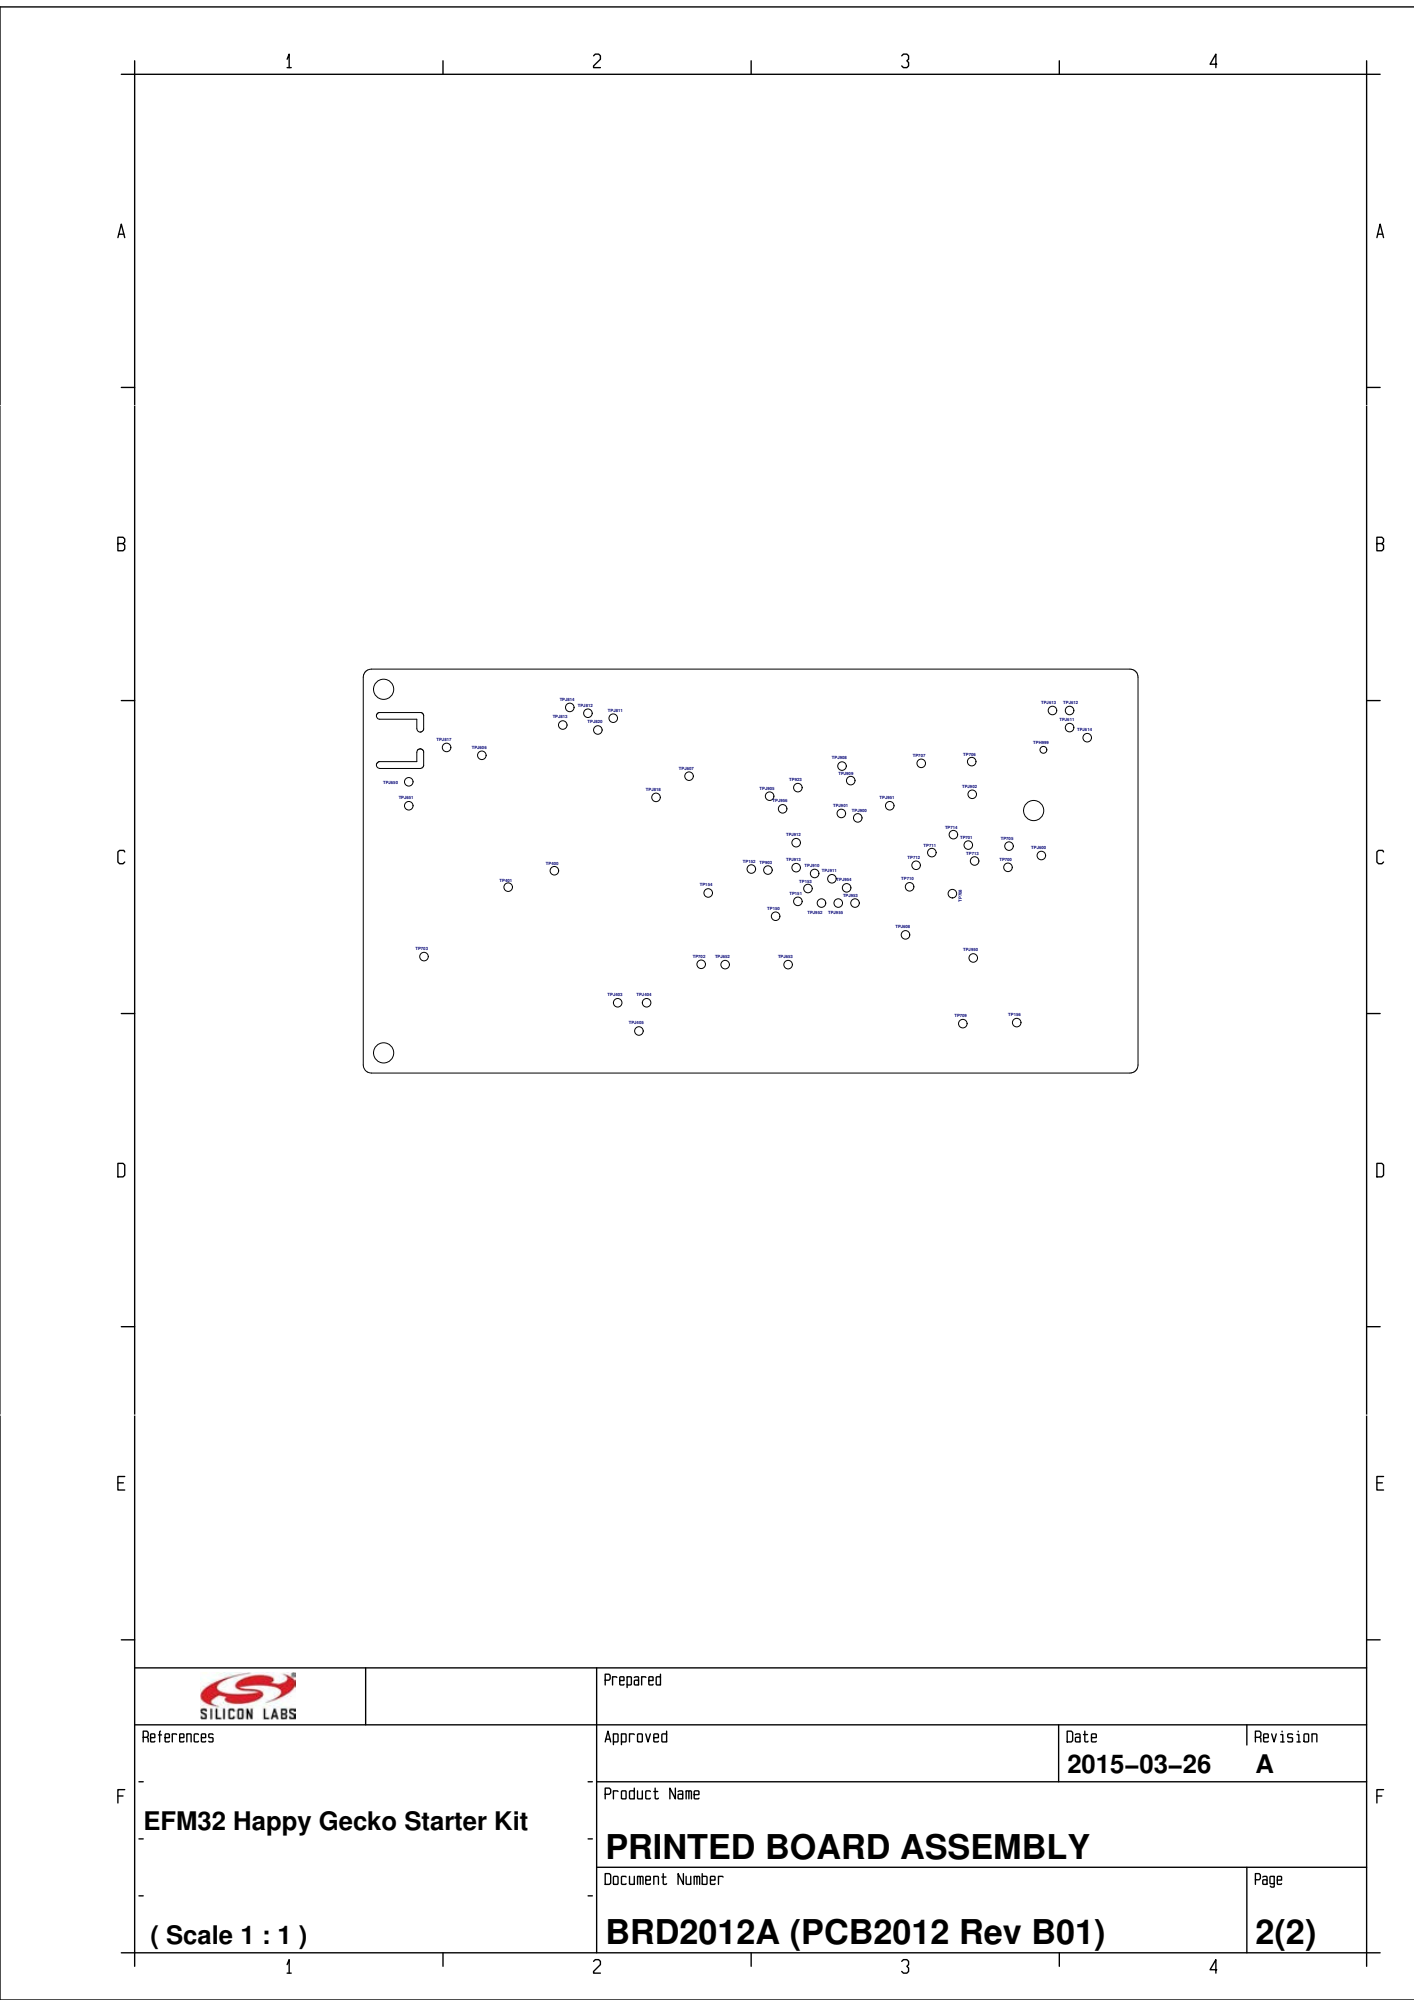
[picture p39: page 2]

EFM32 Happy Gecko Starter Kit

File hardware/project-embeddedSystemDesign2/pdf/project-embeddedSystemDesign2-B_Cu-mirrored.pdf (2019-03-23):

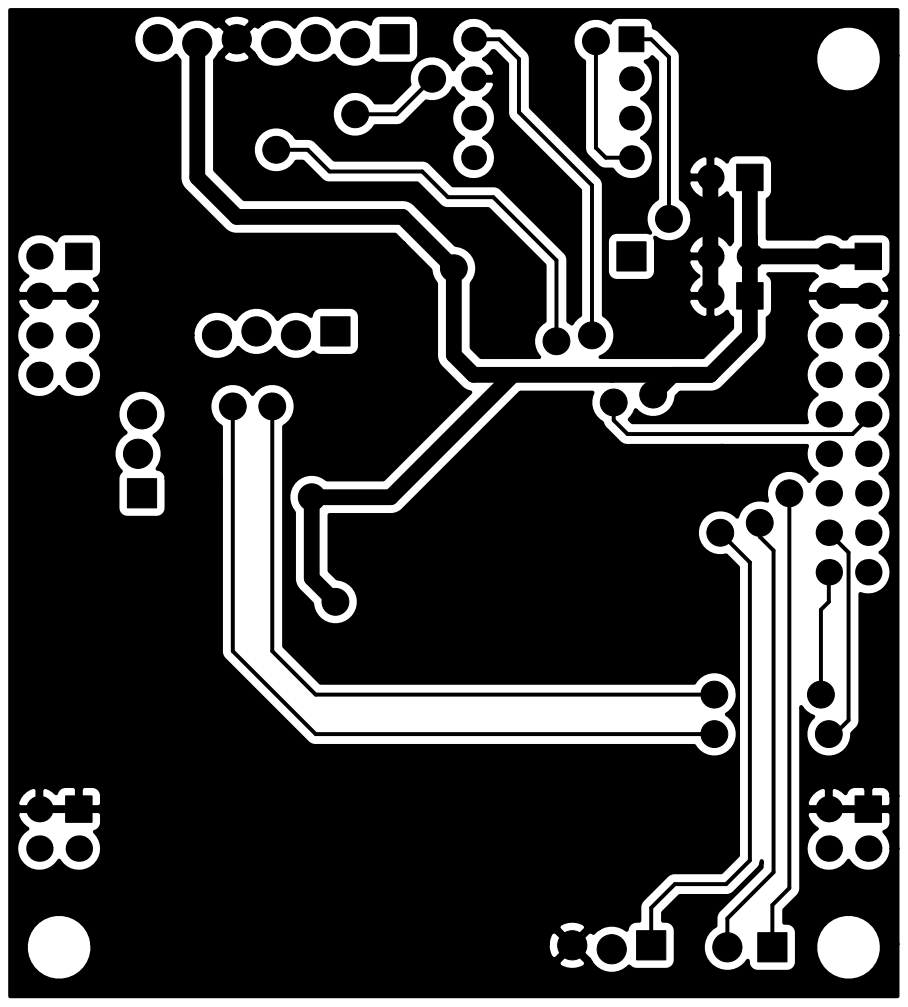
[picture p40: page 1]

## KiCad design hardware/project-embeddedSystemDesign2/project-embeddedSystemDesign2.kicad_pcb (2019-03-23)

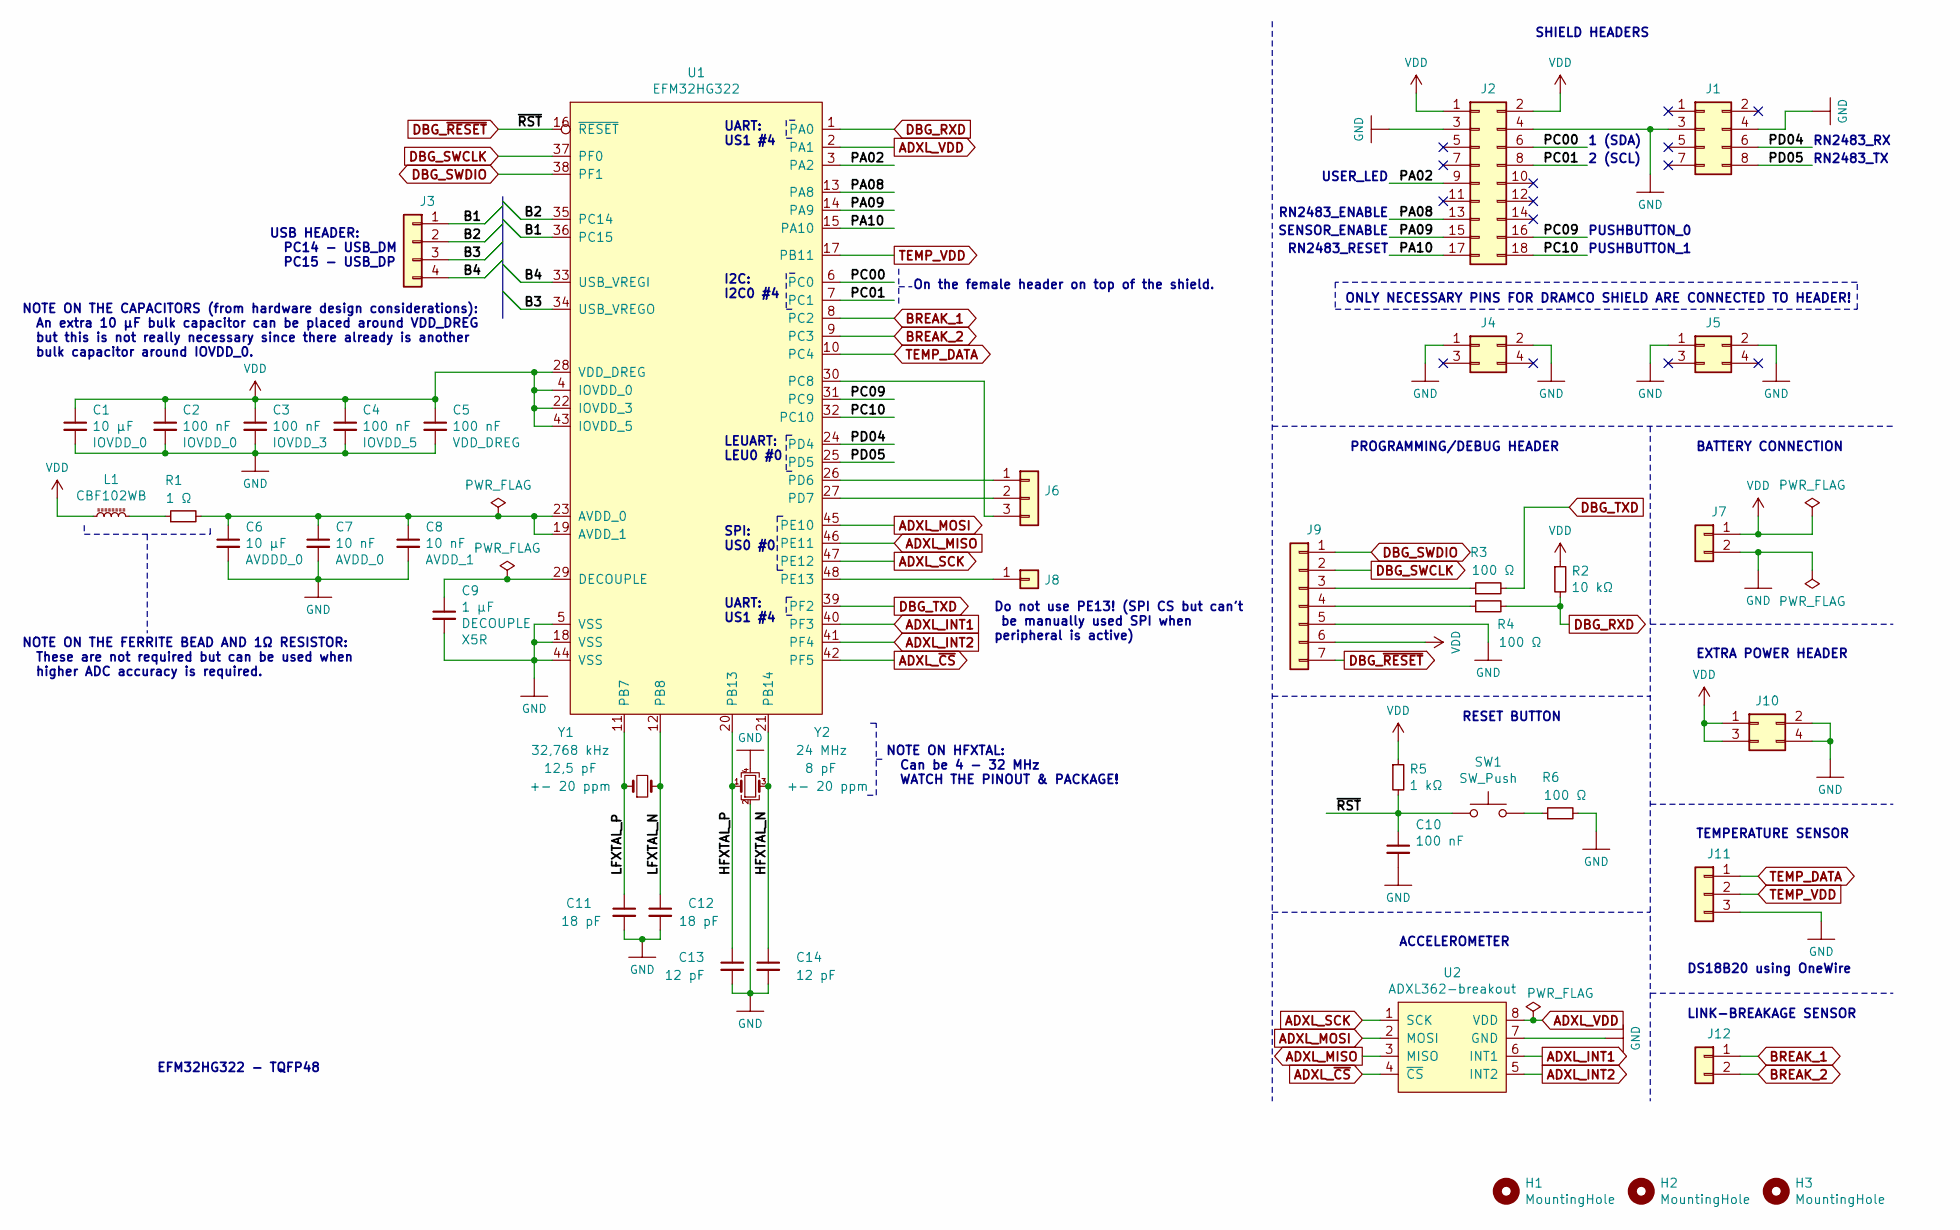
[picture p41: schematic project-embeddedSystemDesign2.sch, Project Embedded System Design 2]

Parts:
C1, C6: 10 µF; C_0805_2012Metric_Pad1.15x1.40mm_HandSolder
C2, C3, C4, C5, C10: 100 nF; C_0805_2012Metric_Pad1.15x1.40mm_HandSolder
C7, C8: 10 nF; C_0805_2012Metric_Pad1.15x1.40mm_HandSolder
C9: 1 µF; C_0805_2012Metric_Pad1.15x1.40mm_HandSolder
C11, C12: 18 pF; C_0805_2012Metric_Pad1.15x1.40mm_HandSolder
C13, C14: 12 pF; C_0805_2012Metric_Pad1.15x1.40mm_HandSolder
H1, H2, H3: MountingHole; MountingHole_3mm
J1: Conn_02x04_Odd_Even; PinHeader_2x04_P2.54mm_Vertical
J2: Conn_02x09_Odd_Even; PinHeader_2x09_P2.54mm_Vertical
J3: Conn_01x04; 1X04_LOCK
J4, J5: Conn_02x02_Odd_Even; PinHeader_2x02_P2.54mm_Vertical
J6, J11: Conn_01x03; 1X03_LOCK
J7: Conn_01x02; PinHeader_1x02_P2.54mm_Horizontal
J8: Conn_01x01; 1X01
J9: Conn_01x07; 1X07_LOCK
J10: Conn_02x02_Odd_Even; PinSocket_2x02_P2.54mm_Vertical
J12: Conn_01x02; 1X02_LOCK
L1: CBF102WB; L_0603_1608Metric_Pad1.05x0.95mm_HandSolder
R1: 1 Ω; R_0805_2012Metric_Pad1.15x1.40mm_HandSolder
R2: 10 kΩ; R_0805_2012Metric_Pad1.15x1.40mm_HandSolder
R3, R4, R6: 100 Ω; R_0805_2012Metric_Pad1.15x1.40mm_HandSolder
R5: 1 kΩ; R_0805_2012Metric_Pad1.15x1.40mm_HandSolder
SW1: SW_Push; SW_SPST_FSMSM
U1: EFM32HG322; LQFP-48_7x7mm_P0.5mm
U2: ADXL362-breakout; DIP-8_W10.16mm
Y1: 32,768 kHz; Crystal_SMD_2012-2Pin_2.0x1.2mm_HandSoldering; Tolerance +- 20 ppm
Y2: 24 MHz; CRYSTAL-SMD-5X3.2-4PAD; Tolerance +- 20 ppm

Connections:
/B1: J3.1, U1.36 (PC15)
/B2: J3.2, U1.35 (PC14)
/B3: J3.3, U1.34 (USB_VREGO)
/B4: J3.4, U1.33 (USB_VREGI)
/HFXTAL_N: C14.1, U1.21 (PB14), Y2.3
/HFXTAL_P: C13.1, U1.20 (PB13), Y2.1
/LFXTAL_N: C12.1, U1.12 (PB8), Y1.2
/LFXTAL_P: C11.1, U1.11 (PB7), Y1.1
/PA02: J2.9, U1.3 (PA2)
/PA08: J2.13, U1.13 (PA8)
/PA09: J2.15, U1.14 (PA9)
/PA10: J2.17, U1.15 (PA10)
/PC00: J2.6, U1.6 (PC0)
/PC01: J2.8, U1.7 (PC1)
/PC09: J2.16, U1.31 (PC9)
/PC10: J2.18, U1.32 (PC10)
/PD04: J1.6, U1.24 (PD4)
/PD05: J1.8, U1.25 (PD5)
ADXL_INT1: U1.40 (PF3), U2.6 (INT1)
ADXL_INT2: U1.41 (PF4), U2.5 (INT2)
ADXL_MISO: U1.46 (PE11), U2.3 (MISO)
ADXL_MOSI: U1.45 (PE10), U2.2 (MOSI)
ADXL_SCK: U1.47 (PE12), U2.1 (SCK)
ADXL_VDD: U1.2 (PA1), U2.8 (VDD)
ADXL_~CS: U1.42 (PF5), U2.4 (~CS)
BREAK_1: J12.1, U1.8 (PC2)
BREAK_2: J12.2, U1.9 (PC3)
DBG_RXD: R2.2, R4.2, U1.1 (PA0)
DBG_SWCLK: J9.2, U1.37 (PF0)
DBG_SWDIO: J9.1, U1.38 (PF1)
DBG_TXD: R3.2, U1.39 (PF2)
DBG_~RESET: C10.1, J9.7, R5.2, SW1.1, U1.16 (~RESET); also elsewhere on the board
GND: C1.2, C2.2, C3.2, C4.2, C5.2, C6.2, C7.2, C8.2, C9.2, C10.2, C11.2, C12.2, C13.2, C14.2, J1.3, J1.4, J2.3, J2.4, J4.1, J4.2, J5.1, J5.2, J7.2, J9.5, J10.2, J10.4, J11.3, R6.2, U1.5 (VSS), U1.18 (VSS), U1.44 (VSS), U2.7 (GND), Y2.2, Y2.4
unnamed: C6.1, C7.1, C8.1, R1.2, U1.19 (AVDD_1), U1.23 (AVDD_0)
unnamed: C9.1, U1.29 (DECOUPLE)
unnamed: J6.1, U1.26 (PD6)
unnamed: J6.2, U1.27 (PD7)
unnamed: J6.3, U1.30 (PC8)
unnamed: J8.1, U1.48 (PE13)
unnamed: J9.3, R3.1
unnamed: J9.4, R4.1
unnamed: L1.2, R1.1
unnamed 42: R6.1, SW1.2; also elsewhere on the board
TEMP_DATA: J11.1, U1.10 (PC4)
TEMP_VDD: J11.2, U1.17 (PB11)
VDD: C1.1, C2.1, C3.1, C4.1, C5.1, J2.1, J2.2, J7.1, J9.6, J10.1, J10.3, L1.1, R2.1, R5.1, U1.4 (IOVDD_0), U1.22 (IOVDD_3), U1.28 (VDD_DREG), U1.43 (IOVDD_5)

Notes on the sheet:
SHIELD HEADERS
PROGRAMMING/DEBUG HEADER
ACCELEROMETER
TEMPERATURE SENSOR
DS18B20 using OneWire
LINK-BREAKAGE SENSOR
RESET BUTTON
BATTERY CONNECTION
Do not use PE13! (SPI CS but can't be manually used SPI when peripheral is active)
EXTRA POWER HEADER
SPI: US0 #0
UART: US1 #4
I2C: I2C0 #4
LEUART: LEU0 #0
NOTE ON HFXTAL: Can be 4 - 32 MHz WATCH THE PINOUT & PACKAGE!
NOTE ON THE CAPACITORS (from hardware design considerations): An extra 10 µF bulk capacitor can be placed around VDD_DREG but this is not really necessary since there already is another bulk capacitor around IOVDD_0.
NOTE ON THE FERRITE BEAD AND 1Ω RESISTOR: These are not required but can be used when higher ADC accuracy is required.
EFM32HG322 - TQFP48
USB HEADER: PC14 - USB_DM PC15 - USB_DP
ONLY NECESSARY PINS FOR DRAMCO SHIELD ARE CONNECTED TO HEADER!
USER_LED
RN2483_ENABLE
SENSOR_ENABLE
RN2483_RESET
PUSHBUTTON_0
PUSHBUTTON_1
RN2483_RX
RN2483_TX
1 (SDA)
2 (SCL)
On the female header on top of the shield.

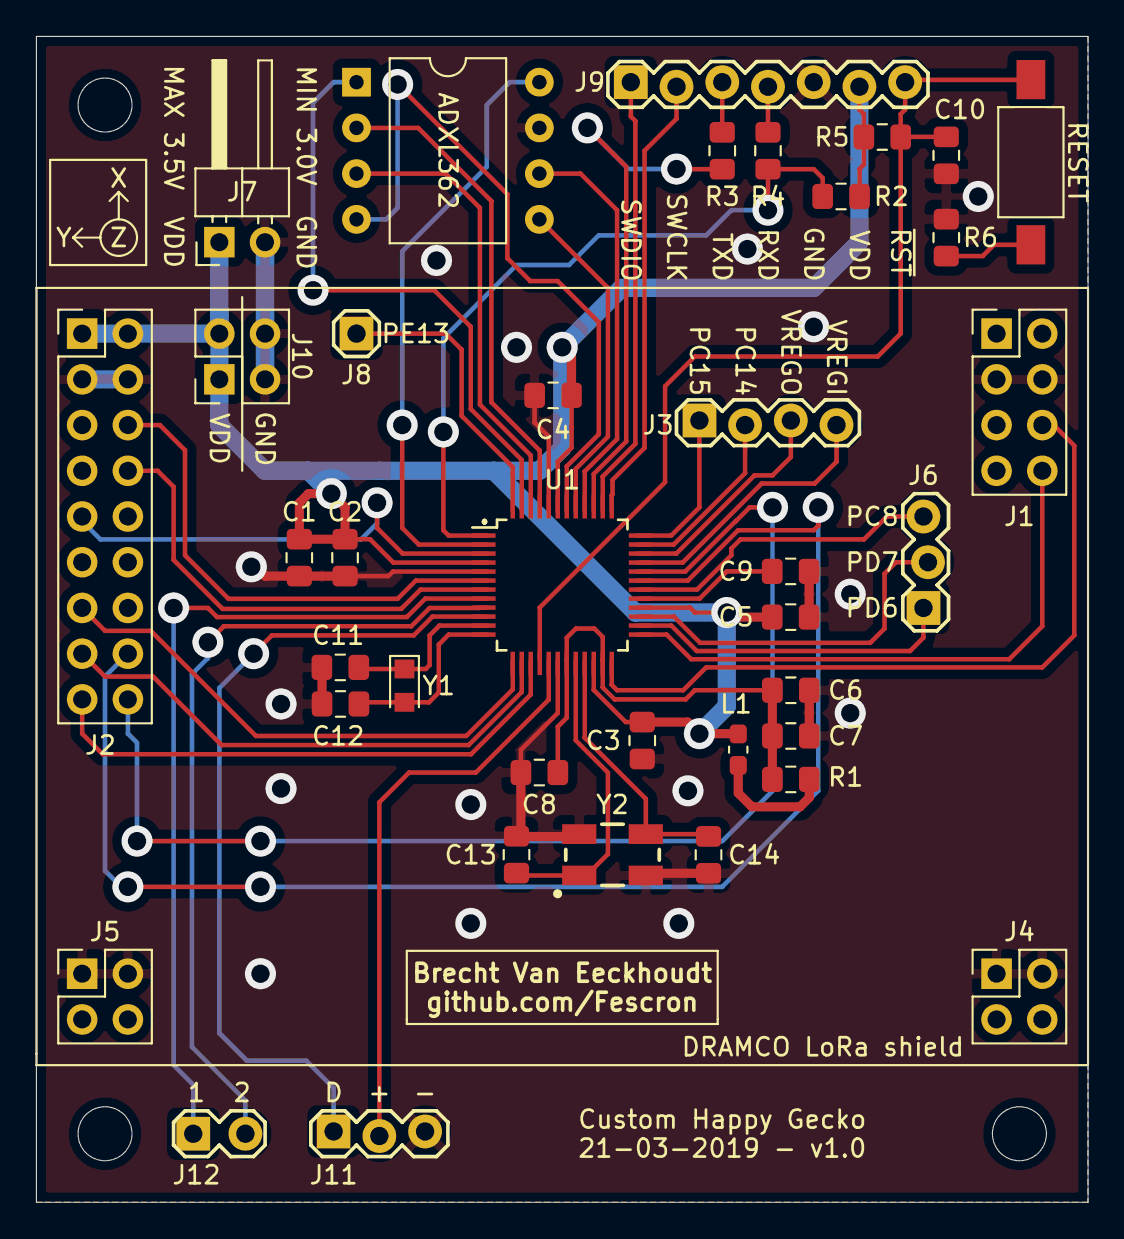
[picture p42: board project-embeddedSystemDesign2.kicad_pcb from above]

Board: 2 copper layers, 58.4 x 64.8 mm, 41 parts (0 on the bottom side), 46 nets.

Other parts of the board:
RESET: SW_Push; SW_SPST_FSMSM

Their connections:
DBG_~RESET: RESET.1; also elsewhere on the board
unnamed 42: RESET.2; also elsewhere on the board

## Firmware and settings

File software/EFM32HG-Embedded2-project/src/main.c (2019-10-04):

/***************************************************************************//**
 * @file main.c
 * @brief The main file for Project 2 from Embedded System Design 2 - Lab.
 * @version 5.2
 * @author Brecht Van Eeckhoudt
 *
 * ******************************************************************************
 *
 * @section Versions
 *
 *   Please check https://github.com/Fescron/Project-LabEmbeddedDesign2/tree/master/software to find the latest version!
 *
 *   @li v1.0: Started from https://github.com/Fescron/Project-LabEmbeddedDesign1
 *             and added code for the DS18B20 temperature sensor and the selfmade
 *             link breakage sensor. Reformatted some of these imported methods.
 *   @li v1.1: Removed unused files, add cable-checking method.
 *   @li v1.2: Moved initRTCcomp method to "util.c".
 *   @li v1.3: Stopped using deprecated function "GPIO_IntConfig".
 *   @li v1.4: Started using get/set method for the static variable "ADXL_triggered".
 *   @li v1.5: Reworked the code a lot (stopped disabling cmuClock_GPIO, ...).
 *   @li v1.6: Moved all documentation above source files to this file.
 *   @li v1.7: Updated documentation, started using a state-machine.
 *   @li v1.8: Moved checkCable method to "other.c" and started using readVBAT method.
 *   @li v1.9: Cleaned up documentation and TODO's.
 *   @li v2.0: Updated code with new DEFINE checks.
 *   @li v2.1: Updated code with new ADC functionality.
 *   @li v2.2: Started using working temperature sensor code.
 *   @li v2.3: Started using working cable checking code and added "SEND" `mcu_state`.
 *   @li v2.4: Started using a struct to keep the measurements in, added line to disable the RN2483.
 *   @li v2.5: Started using custom enum types for the accelerometer settings.
 *   @li v2.6: Added ADXL testing functionality.
 *   @li v2.7: Removed USTIMER logic from this file.
 *   @li v2.8: Added functionality to detect a *storm*.
 *   @li v2.9: Started adding LoRaWAN functionality, added more wake-up/sleep functionality.
 *   @li v3.0: Started using updated LoRaWAN send methods.
 *   @li v3.1: Added functionality to enable/disable the LED blinking when measuring/sending data.
 *   @li v3.2: Fixed button wake-up when sleeping for WAKE_UP_PERIOD_S/2.
 *   @li v3.3: Moved `data.index` reset to LoRaWAN sending functionality and updated documentation.
 *   @li v3.4: Moved `data.index` reset back to `main.c`.
 *   @li v3.5: Added functionality to go back to the remaining sleep time on an accelerometer wake-up.
 *   @li v3.6: Updated code to handle underlying changes.
 *   @li v4.0: Updated documentation and version number.
 *   @li v4.1: Added definitions to easily change the accelerometer's configuration settings.
 *   @li v5.0: Updated sleep logic when waking up using the accelerometer.
 *   @li v5.1: Added extra ISR handlers.
 *   @li v5.2: Removed `static` before a local variable (not necessary).
 *
 * ******************************************************************************
 *
 * @todo
 *   **Optimalisations:**@n
 *     - Change LoRaWAN Spreading Factor and send power, and check the effect on the power usage.
 *     - Add some time to the `while` increment escape counters?
 *     - Check power usage effect of disabling `PM_SENS_EXT`.
 *     - Check difference between absolute/referenced mode for the accelerometer.
 *     - Change *mode* to release.
 *
 * @todo
 *   **Future improvements:**@n
 *     - Use *IAR toolchain* instead of *GCC*, see section **Optimizing code** in `documentation.h`
 *     - Sleep for some time in *while* loops instead of just incrementing the *escape-counter*.
 *         - First separate `ULFRCO` definition in `delay.c
 *     - Try to shorten delays (for example: 40 ms power-up time for the RN2483...)
 *     - Fix `sleepLoRaWAN` and `wakeLoRaWAN` functionality (also see `lora_wrappers.c`).
 *
 * ******************************************************************************
 *
 * @section License
 *
 *   **Copyright (C) 2019 - Brecht Van Eeckhoudt**
 *
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
 *   *A copy of the GNU General Public License can be found in the `LICENSE`
 *   file along with this source code.*
 *
 *   @n
 *
 *   Some methods also use code obtained from examples from [Silicon Labs' GitHub](https://github.com/SiliconLabs/peripheral_examples).
 *   These sections are licensed under the Silabs License Agreement. See the file
 *   "Silabs_License_Agreement.txt" for details. Before using this software for
 *   any purpose, you must agree to the terms of that agreement.
 *
 * ******************************************************************************
 *
 * @attention
 *   See the file `documentation.h` for a lot of useful documentation about this project!
 *
 * ******************************************************************************
 *
 * @section Errors
 *
 *   If in this project something unexpected occurs, an `error` method gets called.
 *   What happens in this method can be selected in `util.h` with the definition
 *   `ERROR_FORWARDING`. If it's value is `0` the MCU displays (if `dbprint` is enabled)
 *   a UART message and gets put in a `while(true)` to flash the LED. If it's value is
 *   `1` then certain values (all values except 30 - 55 since these are errors in the
 *   LoRaWAN functionality itself) get forwarded to the cloud using LoRaWAN functionality
 *   and the MCU resumes it's code.
 *
 *   When calling an `error` method, the following things were kept in mind:
 *     - **Values 0 - 9:** Reserved for reset and other critical functionality.
 *         - **1:** Send once after a reset (`firstBoot == true` in `main.c`)
 *         - **9:** Used in `sendTest(data);` method (`lora_wrappers.c`)
 *     - **Values 10 - ... :** Available to use for anything else.
 *
 *   Below is a list of values which correspond to certain functionality:
 *     - **10:** Problem in the case of the state machine (`main.c`)
 *     - **11 - 13:** `adc.c`
 *     - **14 - 17:** `delay.c`
 *     - **18 - 19:** `interrupt.c`
 *     - **20 - 27:** `ADXL362.c`
 *     - **28 - 29:** `DS18B20.c`
 *     - **30 - 50:** `lora_wrappers.c`
 *     - **51 - 55:** `leuart.c`
 *
 * ******************************************************************************
 *
 * @section CHANNELS LoRaWAN sensor channels
 *
 *   - `LPP_VBAT_CHANNEL            0x10 // 16`
 *   - `LPP_TEMPERATURE_CHANNEL_INT 0x11 // 17`
 *   - `LPP_TEMPERATURE_CHANNEL_EXT 0x12 // 18`
 *   - `LPP_STORM_CHANNEL           0x13 // 19`
 *   - `LPP_CABLE_BROKEN_CHANNEL    0x14 // 20`
 *   - `LPP_STATUS_CHANNEL          0x15 // 21`
 *
 ******************************************************************************/


#include <stdint.h>        /* (u)intXX_t */
#include <stdbool.h>       /* "bool", "true", "false" */
#include "em_device.h"     /* Include necessary MCU-specific header file */
#include "em_chip.h"       /* Chip Initialization */
#include "em_cmu.h"        /* Clock management unit */
#include "em_gpio.h"       /* General Purpose IO */
#include "em_rtc.h"        /* Real Time Counter (RTC) */

#include "pin_mapping.h"   /* PORT and PIN definitions */
#include "debug_dbprint.h" /* Enable or disable printing to UART for debugging */
#include "delay.h"         /* Delay functionality */
#include "util.h"          /* Utility functionality */
#include "interrupt.h"     /* GPIO wake-up initialization and interrupt handlers */
#include "ADXL362.h"       /* Functions related to the accelerometer */
#include "DS18B20.h"       /* Functions related to the temperature sensor */
#include "adc.h"           /* Internal voltage and temperature reading functionality */
#include "cable.h"         /* Cable checking functionality */
#include "lora_wrappers.h" /* LoRaWAN functionality */
#include "datatypes.h"     /* Definitions of the custom data-types */


/* Local definitions */
/** Time between each wake-up in seconds
 *    @li max 500 seconds when using LFXO delay
 *    @li 3600 seconds (one hour) works fine when using ULFRCO delay */
#define WAKE_UP_PERIOD_S   180 // On buoy: 1800 /* 600 = every 10 minutes */

/** Amount of PIN interrupt wakeups (before a RTC wake-up) to be considered as a *storm* */
#define STORM_INTERRUPTS   8

/** The threshold value [g] for the accelerometer to detect and send an interrupt to wake-up the MCU */
#define ADXL_THRESHOLD     7

/** The *g* range to configure the accelerometer with */
#define ADXL_RANGE         ADXL_RANGE_8G

/** The ODR setting to configure the accelerometer with */
#define ADXL_ODR           ADXL_ODR_12_5_HZ

/** Public definition to select if the LED is turned on while measuring or sending data
 *    @li `1` - Enable the LED when while measuring or sending data.
 *    @li `0` - Don't enable the LED while measuring or sending data. */
#define LED_ENABLED        0


/* Local variables */
/** Keep the state of the state machine */
static MCU_State_t MCUstate; /* Static so it's always kept in memory (@data segment, space provided during compile time) */

/** Keep the measurement data */
MeasurementData_t data;


/**************************************************************************//**
 * @brief
 *   Method to check if any interrupts are triggered by buttons.
 *
 * @return
 *   @li `true` - A button interrupt was triggered.
 *   @li `false` - No button interrupt was triggered.
 *****************************************************************************/
bool checkBTNinterrupts (void)
{
	bool value = false;

	if (BTN_getTriggered(0))
	{

#if DEBUG_DBPRINT == 1 /* DEBUG_DBPRINT */
		dbprintln_color("PB0 pushed!", 4);
#endif /* DEBUG_DBPRINT */

		value = true;

		BTN_setTriggered(0, false); /* Clear variable */
	}


	if (BTN_getTriggered(1))
	{

#if DEBUG_DBPRINT == 1 /* DEBUG_DBPRINT */
		dbprintln_color("PB1 pushed!", 4);
#endif /* DEBUG_DBPRINT */

		value = true;

		BTN_setTriggered(1, false); /* Clear variable */
	}

	return (value);
}


/**************************************************************************//**
 * @brief
 *   Main function.
 *****************************************************************************/
int main (void)
{
	/* Keep a value if a storm has been detected */
	bool stormDetected = false;

	/* Value used to send one test LoRaWAN message after booting */
	bool firstBoot = true;

	/* Value to keep the remaining sleep time when waking up using the accelerometer */
	uint32_t remainingSleeptime = 0;

	/* Set the index to put the measurements in */
	data.index = 0;

	while (1)
	{
		switch (MCUstate)
		{
			case INIT:
			{
				CHIP_Init(); /* Initialize chip */

#if DEBUG_DBPRINT == 1 /* DEBUG_DBPRINT */
#if CUSTOM_BOARD == 1 /* Custom Happy Gecko pinout */
				dbprint_INIT(DBG_UART, DBG_UART_LOC, false, false);
				dbwarn("CUSTOM board pinout selected");
#else /* Regular Happy Gecko pinout */
				dbprint_INIT(USART1, 4, true, false); /* VCOM */
				dbwarn("REGULAR board pinout selected");
#endif /* Board pinout selection */
#endif  /* DEBUG_DBPRINT */

				led(true); /* Enable (and initialize) LED */

				delay(4000); /* 4 second delay to notice initialization */
				led(false);
				delay(100);
				led(true);

				initGPIOwakeup(); /* Initialize GPIO wake-up */

				initADC(BATTERY_VOLTAGE); /* Initialize ADC to read battery voltage */

				/* Initialize pin and disable power to RN2483 */
				GPIO_PinModeSet(PM_RN2483_PORT, PM_RN2483_PIN, gpioModePushPull, 0);

				/* Initialize pin and disable external sensor power on DRAMCO shield */
				GPIO_PinModeSet(PM_SENS_EXT_PORT, PM_SENS_EXT_PIN, gpioModePushPull, 0); // TODO: check power usage effect?

				/* Initialize accelerometer */
				if (true)
				{
					/* Go through all of the accelerometer ODR settings to see the influence they have on power usage. */
					if (false)
					{
						initADXL(); /* Initialize the accelerometer */

						led(false);
						testADXL();
						led(true);
					}

					initADXL(); /* Initialize the accelerometer */

					ADXL_configRange(ADXL_RANGE); /* Set the measurement range */

					ADXL_configODR(ADXL_ODR); /* Configure ODR */

					if (false) ADXL_readValues(); /* Read and display values forever */

					ADXL_configActivity(ADXL_THRESHOLD); /* Configure (referenced) activity threshold mode on INT1 [g] */

					ADXL_enableMeasure(true); /* Enable measurements */

					delay(300);

					ADXL_ackInterrupt(); /* ADXL gives interrupt, capture this and acknowledge it by reading from it's status register */

					ADXL_enableSPI(false); /* Disable SPI after the initializations */

					ADXL_clearCounter(); /* Clear the trigger counter */
				}

#if DEBUG_DBPRINT == 1 /* DEBUG_DBPRINT */
				dbprintln("");
#endif /* DEBUG_DBPRINT */

				led(false); /* Disable LED */

				MCUstate = MEASURE;
			} break;

			case MEASURE:
			{

#if LED_ENABLED == 1 /* LED_ENABLED */
				led(true); /* Enable LED */
#endif /* LED_ENABLED */

				/* Measure and store the external temperature */
				data.extTemp[data.index] = readTempDS18B20();

				/* Measure and store the battery voltage */
				data.voltage[data.index] = readADC(BATTERY_VOLTAGE);

				/* Measure and store the internal temperature */
				data.intTemp[data.index] = readADC(INTERNAL_TEMPERATURE);

#if DEBUG_DBPRINT == 1 /* DEBUG_DBPRINT */
				dbinfoInt("Measurement ", data.index + 1, "");
				dbinfoInt("Temperature: ", data.extTemp[data.index], "");
				dbinfoInt("Battery voltage: ", data.voltage[data.index], "");
				dbinfoInt("Internal temperature: ", data.intTemp[data.index], "");
#endif /* DEBUG_DBPRINT */

				/* Increase the index to put the next measurements in */
				data.index++;

				/* Check if the cable is intact and send LoRaWAN data if necessary */
				if (checkCable(data)) data.index = 0; /* If measurements have been send, reset the index */

				if (firstBoot && (data.index > 0))
				{

#if DEBUG_DBPRINT == 1 /* DEBUG_DBPRINT */
					dbwarn("Sending first measurements ...");
#endif /* DEBUG_DBPRINT */

					initLoRaWAN(); /* Initialize LoRaWAN functionality */

					sendStatus(1); /* Send the status data */

					sendMeasurements(data); /* Send the measurements */

					disableLoRaWAN(); /* Disable RN2483 */

					data.index = 0; /* Reset the index to put the measurements in (needs to be here for the correct data to be affected) */

					firstBoot = false;
				}

#if LED_ENABLED == 1 /* LED_ENABLED */
				led(false); /* Disable LED */
#endif /* LED_ENABLED */

				/* Decide if 6 measurements are taken or not and react accordingly */
				if (data.index == 6) MCUstate = SEND;
				else MCUstate = SLEEP;
			} break;

			case SEND:
			{

#if LED_ENABLED == 1 /* LED_ENABLED */
				led(true); /* Enable LED */
#endif /* LED_ENABLED */

#if DEBUG_DBPRINT == 1 /* DEBUG_DBPRINT */
				dbwarnInt("Sending ", data.index, " measurements ...");
#endif /* DEBUG_DBPRINT */

				initLoRaWAN(); /* Initialize LoRaWAN functionality */

				sendMeasurements(data); /* Send the measurements */

				disableLoRaWAN(); /* Disable RN2483 */

				data.index = 0; /* Reset the index to put the measurements in (needs to be here for the correct data to be affected) */

#if LED_ENABLED == 1 /* LED_ENABLED */
				led(false); /* Disable LED */
#endif /* LED_ENABLED */

				MCUstate = SLEEP;
			} break;

			case SEND_STORM:
			{

#if LED_ENABLED == 1 /* LED_ENABLED */
				led(true); /* Enable LED */
#endif /* LED_ENABLED */

#if DEBUG_DBPRINT == 1 /* DEBUG_DBPRINT */
				dbwarnInt("STORM DETECTED! Sending ", data.index, " measurement(s) ...");
#endif /* DEBUG_DBPRINT */

				initLoRaWAN(); /* Initialize LoRaWAN functionality */

				sendStormDetected(true); /* Send a message to indicate that a storm has been detected */

				if (data.index > 0)
				{
					sendMeasurements(data); /* Send the already gathered measurements */

					data.index = 0; /* Reset the index to put the measurements in (needs to be here for the correct data to be affected) */
				}

				disableLoRaWAN(); /* Disable RN2483 */

				stormDetected = true; /* Indicate that a storm has been detected */

#if LED_ENABLED == 1 /* LED_ENABLED */
				led(false); /* Disable LED */
#endif /* LED_ENABLED */

				MCUstate = SLEEP_HALFTIME;
			} break;

			case SLEEP:
			{
				sleep(WAKE_UP_PERIOD_S); /* Go to sleep for xx seconds */

				MCUstate = WAKEUP;
			} break;

			case SLEEP_HALFTIME:
			{
				sleep(WAKE_UP_PERIOD_S/2); /* Go to sleep for xx seconds */

				MCUstate = WAKEUP;
			} break;

			case WAKEUP:
			{

#if LED_ENABLED == 1 /* LED_ENABLED */
				led(true); /* Enable LED */
#endif /* LED_ENABLED */

				/* Check if we woke up using buttons */
				if (checkBTNinterrupts())
				{
					ADXL_clearCounter(); /* Clear the trigger counter */
					remainingSleeptime = 0; /* Reset passed sleeping time */

					MCUstate = MEASURE; /* Take measurements on "case WAKEUP" exit */
				}

				/* Check if we woke up using the RTC sleep functionality and act accordingly */
				if (RTC_checkWakeup())
				{
					RTC_clearWakeup(); /* Clear variable */

					ADXL_clearCounter(); /* Clear the trigger counter because we woke up "normally" */
					remainingSleeptime = 0; /* Reset passed sleeping time since it's an RTC wakeup */

					MCUstate = MEASURE; /* Take measurements on "case WAKEUP" exit */
				}

				/* Check if we woke up using the accelerometer */
				if (ADXL_getTriggered())
				{
					/* Check if we detected a storm */
					if (ADXL_getCounter() > STORM_INTERRUPTS)
					{
						RTC_Enable(false); /* Disable the counter */

						MCUstate = SEND_STORM; /* Storm detected, send a message on "case WAKEUP" exit */
					}
					else
					{

#if DEBUG_DBPRINT == 1 /* DEBUG_DBPRINT */
						dbprintln_color("INT-PD7 triggered!", 4);
#endif /* DEBUG_DBPRINT */

						ADXL_enableSPI(true);  /* Enable SPI functionality */
						ADXL_ackInterrupt();   /* Acknowledge ADXL interrupt by reading the status register */
						ADXL_enableSPI(false); /* Disable SPI functionality */

						/* Check if a storm was detected before going to sleep for WAKE_UP_PERIOD_S/2 */
						if (stormDetected)
						{
							stormDetected = false; /* Reset variable */
							MCUstate = MEASURE; /* Take measurements on "case WAKEUP" exit */
						}
						else
						{
							remainingSleeptime += RTC_getPassedSleeptime(); /* Add the time spend sleeping to the variable */

#if LED_ENABLED == 1 /* LED_ENABLED */
							led(false); /* Disable LED */
#endif /* LED_ENABLED */

							/* Go back to sleep for the remaining time until another measurement (we only take measurements on RTC/button wake-up) */
							sleep(WAKE_UP_PERIOD_S - remainingSleeptime);

							MCUstate = WAKEUP; /* Go back to this case if we wake-up */
						}
					}
				}

#if LED_ENABLED == 1 /* LED_ENABLED */
				led(false); /* Disable LED */
#endif /* LED_ENABLED */

			} break;

			default:
			{
				error(10);
			} break;
		}
	}
}


/**************************************************************************//**
 * @brief
 *   NMI interrupt service routine.
 *
 * @note
 *   The *weak* definition for this method is located in `startup_gcc_efm32hg.h`.
 *****************************************************************************/
void NMI_Handler(void)
{
	while(1);
}


/**************************************************************************//**
 * @brief
 *   HardFault interrupt service routine.
 *
 * @note
 *   The *weak* definition for this method is located in `startup_gcc_efm32hg.h`.
 *****************************************************************************/
void HardFault_Handler(void)
{
	while(1);
}


/**************************************************************************//**
 * @brief
 *   SVC interrupt service routine.
 *
 * @note
 *   The *weak* definition for this method is located in `startup_gcc_efm32hg.h`.
 *****************************************************************************/
void SVC_Handler(void)
{
	while(1);
}


/**************************************************************************//**
 * @brief
 *   PendSV interrupt service routine.
 *
 * @note
 *   The *weak* definition for this method is located in `startup_gcc_efm32hg.h`.
 *****************************************************************************/
void PendSV_Handler(void)
{
	while(1);
}

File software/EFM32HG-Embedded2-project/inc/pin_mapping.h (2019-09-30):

/***************************************************************************//**
 * @file pin_mapping.h
 * @brief The pin definitions for the regular and custom Happy Gecko board.
 * @version 2.0
 * @author Brecht Van Eeckhoudt
 *
 * ******************************************************************************
 *
 * @section Versions
 *
 *   @li v1.0: Started with custom board pinout.
 *   @li v1.1: Added regular board pinout, selectable with define statement.
 *   @li v1.2: Added documentation.
 *   @li v1.3: Updated code with new DEFINE checks.
 *   @li v1.4: Added IIC definitions.
 *   @li v2.0: Updated version number.
 *
 * ******************************************************************************
 *
 * @section License
 *
 *   **Copyright (C) 2019 - Brecht Van Eeckhoudt**
 *
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
 *   *A copy of the GNU General Public License can be found in the `LICENSE`
 *   file along with this source code.*
 *
 *   @n
 *
 *   Some methods use code obtained from examples from [Silicon Labs' GitHub](https://github.com/SiliconLabs/peripheral_examples).
 *   These sections are licensed under the Silabs License Agreement. See the file
 *   "Silabs_License_Agreement.txt" for details. Before using this software for
 *   any purpose, you must agree to the terms of that agreement.
 *
 ******************************************************************************/


/* Include guards prevent multiple inclusions of the same header */
#ifndef _PIN_MAPPING_H_
#define _PIN_MAPPING_H_


/* Include necessary for this header file */
#include "em_device.h" /* Include necessary MCU-specific header file */
#include "em_gpio.h"   /* General Purpose IO */


/** Public definition to select the Happy Gecko board *version*
 *    @li `1` - Use the custom Happy Gecko board pinout.
 *    @li `0` - Use the regular Happy Gecko board pinout. */
#define CUSTOM_BOARD 1


#if CUSTOM_BOARD == 1 /* Custom Happy Gecko pinout */

	/* ADXL362 */
	#define ADXL_SPI            USART0
	#define ADXL_SPI_LOC        0
	#define ADXL_MOSI_PORT      gpioPortE
	#define ADXL_MOSI_PIN       10
	#define ADXL_MISO_PORT      gpioPortE
	#define ADXL_MISO_PIN       11
	#define ADXL_CLK_PORT       gpioPortE
	#define ADXL_CLK_PIN        12
	#define ADXL_NCS_PORT       gpioPortF /* Can't use the US0_CS port (PE13) to manually set/clear CS line */
	#define ADXL_NCS_PIN        5

	#define ADXL_INT1_PORT      gpioPortF
	#define ADXL_INT1_PIN       3
	#define ADXL_INT2_PORT      gpioPortF /* Unused */
	#define ADXL_INT2_PIN       4         /* Unused */
	#define ADXL_VDD_PORT       gpioPortA
	#define ADXL_VDD_PIN        1

	/* LED */
	#define LED_PORT            gpioPortA
	#define LED_PIN             2

	/* Buttons */
	#define PB0_PORT            gpioPortC
	#define PB0_PIN             9
	#define PB1_PORT            gpioPortC
	#define PB1_PIN             10

	/* UART */
	#define DBG_UART            USART1
	#define DBG_UART_LOC        4
	#define DBG_TXD_PORT        gpioPortF
	#define DBG_TXD_PIN         2
	#define DBG_RXD_PORT        gpioPortA
	#define DBG_RXD_PIN         0

	/* DS18B20 */
	#define TEMP_DATA_PORT      gpioPortC
	#define TEMP_DATA_PIN       4
	#define TEMP_VDD_PORT       gpioPortB
	#define TEMP_VDD_PIN        11

	/* Link breakage sensor */
	#define BREAK1_PORT         gpioPortC
	#define BREAK1_PIN          2
	#define BREAK2_PORT         gpioPortC
	#define BREAK2_PIN          3

	/* RN2483 */
	#define RN2483_UART         LEUART0
	#define RN2483_UART_LOC     0
	#define RN2483_TX_PORT      gpioPortD
	#define RN2483_TX_PIN       4
	#define RN2483_RX_PORT      gpioPortD
	#define RN2483_RX_PIN       5
	#define RN2483_RESET_PORT   gpioPortA
	#define RN2483_RESET_PIN    10

	/* External header */
	#define IIC_EXT             I2C0      /* Unused */
	#define IIT_EXT_LOC         4         /* Unused */
	#define IIC_SDA_PORT        gpioPortC /* Unused */
	#define IIC_SDA_PIN         0         /* Unused */
	#define IIC_SCL_PORT        gpioPortC /* Unused */
	#define IIC_SCL_PIN         1         /* Unused */

	/* Power supply enable */
	#define PM_RN2483_PORT		gpioPortA
	#define PM_RN2483_PIN		8
	#define PM_SENS_EXT_PORT	gpioPortA
	#define PM_SENS_EXT_PIN		9
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

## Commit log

2019-03-21 Add datasheets
    [EFM32HG_BRD2012A_B01_bom.xlsx]
2019-03-22 Add PCB design files
    [project-embeddedSystemDesign2.csv, project-embeddedSystemDesign2.kicad_pcb, project-embeddedSystemDesign2.sch]
2019-03-23 Update PCB
    [project-embeddedSystemDesign2-B_Cu.gbr, project-embeddedSystemDesign2-B_Paste.gbr, project-embeddedSystemDesign2-B_SilkS.gbr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]
2019-03-23 Update BOM
    [project-embeddedSystemDesign2.csv]
2019-03-25 Update PCB gerbers
    [project-embeddedSystemDesign2-B_Cu.gbr, project-embeddedSystemDesign2-B_Mask.gbr, project-embeddedSystemDesign2-B_Paste.gbr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]
2019-03-27 Add current estimates
2019-04-02 Remove unnecessary files, start adding link break sensor, cleanup code
2019-04-04 Made some methods/global variables static, fixed some debug printing
    [ADXL362.c, DS18B20.c, handlers.c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]
2019-04-06 Reworked delay functionality, updated documentation & include locations
    [ADXL362.c, DS18B20.c, handlers.c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]
2019-04-08 Fixed Doxygen documentation and included it in upload
    [ADXL362.c, DS18B20.c, interrupt.c]
2019-04-13 Added extra ADC functionality, updated inc, started changing temp logic
2019-04-13 Added extra ADC functionality, updated incs, started changing temp logic
2019-04-15 Upload PCB with dimensions
2019-04-15 Updated BOM
2019-04-15 Update current estimates
2019-04-19 Fixed cable checking method, started checking hourly wakeup timing
    [cable.c, interrupt.c, main.c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]
2019-04-20 Removed unnecessary INT checks, cleaned up ADC code
2019-04-20 Fixed "sleep" current but broke read temperature functionality
    [DS18B20.c]
2019-04-25 Stopped disabling RTC timer on pin wakeup
2019-04-25 Only enabled timer clocks when in use
2019-04-30 Updated error numbering and documentation
    [ADXL362.c, adc.c, interrupt.c]
2019-04-30 Updated return type of temperature reading method
2019-04-30 Implemented error method to forward value to the cloud
    [util.c]
2019-04-30 Added extra I2C definitions
2019-04-30 Updated error number, added enable/disable functionality for LED
    [main.c]
2019-05-01 Started fixing timeout functionality and changed returntypes
    [DS18B20.c]
2019-05-01 Fixed error forwarding functionality
    [util.c]
2019-05-03 Update dbprint and timeout functionality and fix temperature reading
    [DS18B20.c]
2019-05-06 Fixed data.index clearing (previous code wrote data out of given array)
    [lora_wrappers.c, main.c]
2019-05-06 Changed so that no code will be executed further if first INIT failed
    [DS18B20.c]
2019-05-07 Added functionality around "error" calls and updated version number
    [ADXL362.c, DS18B20.c, adc.c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]
2019-05-07 Added functionality to send measurements on cable breaking detection
2019-05-08 Added battery datasheets
2019-05-09 Added current measurements
2019-05-10 Added flowchart
2019-05-23 Updated sleep logic when waking up using the accelerometer
2019-09-30 Chanced logic to clear the buffer before going to sleep to fix bug
    [lora_wrappers.c]
2019-10-03 Added comment about supposed problem with dbpointer
    [rn2483.c]

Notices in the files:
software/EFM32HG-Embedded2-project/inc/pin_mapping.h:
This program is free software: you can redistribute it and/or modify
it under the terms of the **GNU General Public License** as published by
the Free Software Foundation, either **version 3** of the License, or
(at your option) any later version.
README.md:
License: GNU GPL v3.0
